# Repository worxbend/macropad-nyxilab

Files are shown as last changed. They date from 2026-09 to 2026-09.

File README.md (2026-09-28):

<div align="center">

# 🌙 nyxilab macropad

**12 keys. 2 screens. 16 LEDs. 1 stick *or* 1 knob. 0 glue.**
<br>it's giving main character desk energy 💅








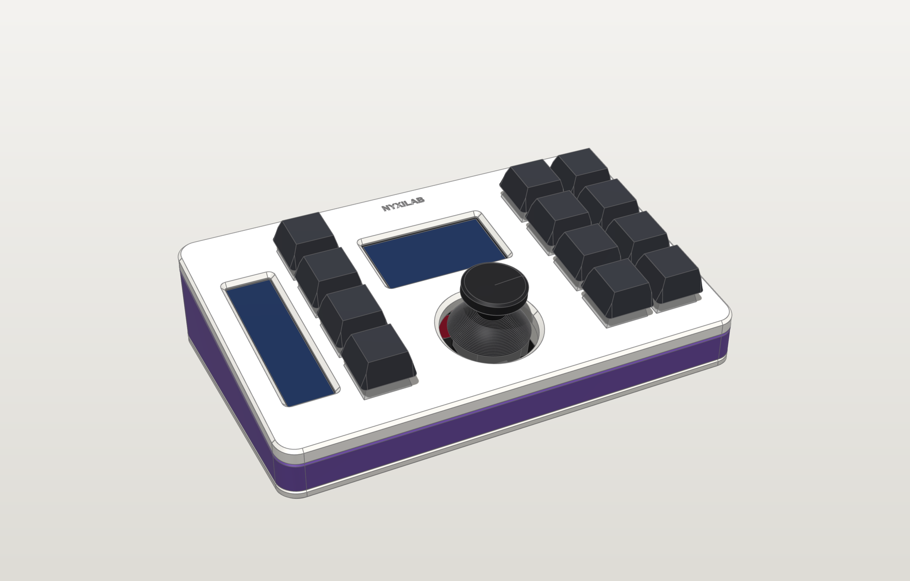
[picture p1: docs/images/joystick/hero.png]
nyxilab macropad render, joystick edition


**[📖 docs site](https://worxbend.github.io/macropad-nyxilab/) · [🧊 3D viewer](https://worxbend.github.io/macropad-nyxilab/viewer.html) · [⬇️ downloads](https://worxbend.github.io/macropad-nyxilab/downloads.html)**

</div>

## tl;dr 🫠

a hand-wired, 3D-printed macropad built around a **Raspberry Pi Pico 2**, with two color
displays, 16 RGB LEDs, and your pick of an analog thumbstick or a clicky rotary knob. this
monorepo has literally everything: the parametric case, print-ready files, blueprints,
a soldering guide with wiring maps, and the firmware. clone it, print it, solder it, flex it.
no custom PCB, no extra USB socket, no cap.

## choose your fighter 🎮

same case, same keys, same screens, same LEDs. only the thing in the middle changes,
and each edition is its own pair of projects.

| 🕹️ **joystick edition** | 🎛️ **rotary edition** |
|---|---|
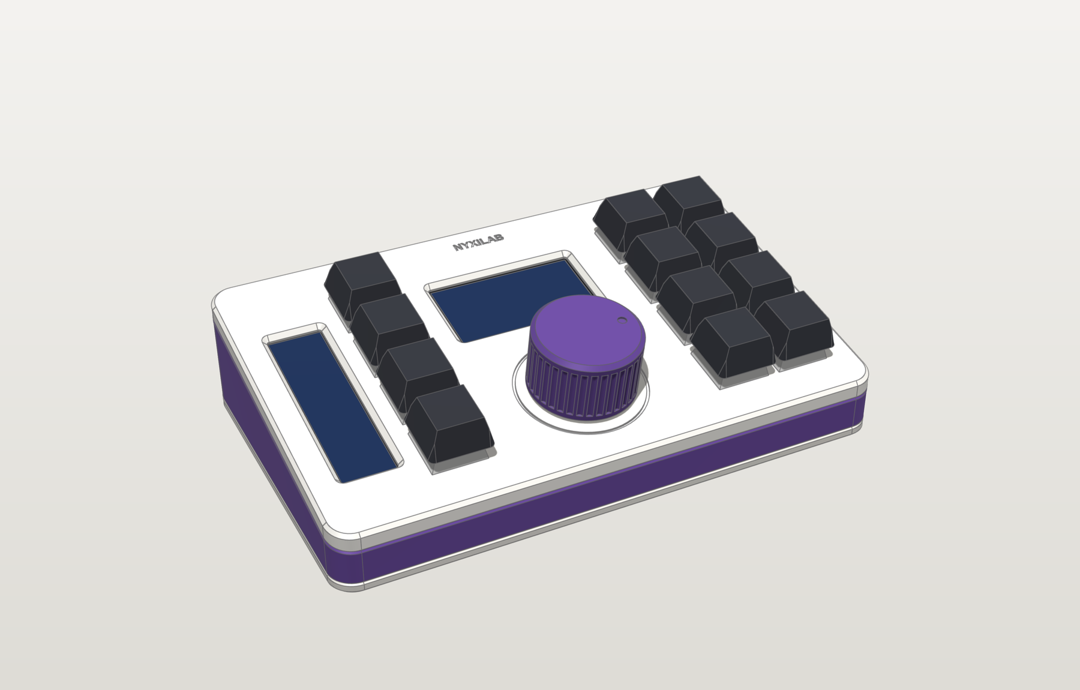
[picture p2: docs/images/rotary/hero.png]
rotary edition
| joystick edition |  |
| KY-023 thumbstick: mouse, scroll or arrow keys, per layer | KY-040 encoder + a chunky printed Ø30 knob: volume, undo/redo, scroll, zoom… |
| [`joystick/cad`](joystick/cad) · [`joystick/firmware`](joystick/firmware) | [`rotary/cad`](rotary/cad) · [`rotary/firmware`](rotary/firmware) |
| `nyxilab-macropad-joystick-pico2.uf2` | `nyxilab-macropad-rotary-pico2.uf2` |
| [read more →](joystick/README.md) | [read more →](rotary/README.md) |

the frame and the bar-display spine are literally the same parts in both, so switching
teams later means reprinting the top plate and the base. that's it.

## the specs (no cap) 📋

| | |
|---|---|
| ⌨️ **inputs** | 12 × MX switches (hand-wired matrix + diodes) and a KY-023 thumbstick that clicks **or** a KY-040 knob that clicks |
| 📺 **screens** | 1.9" 170×320 ST7789 IPS (main character) + 2.25" 76×284 ST7789P3 bar (the sidekick) |
| 💡 **lights** | 2 × 8 WS2812B LED sticks on the base, either side of the Pico: layer color, breathing or rainbow |
| 🧠 **brain** | Pico 2 (RP2350) USB-C clone, or the OG Pico (RP2040) if that's what you've got |
| 📐 **case** | 3-layer wedge: top plate, contrasting centre frame, base · 10° tilt · 159 × 98 mm · 18 → 35 mm tall |
| 🔩 **held together by** | 8 × M3×8 countersunk screws into heat-set inserts. zero glue, fully serviceable |
| ⚡ **firmware** | USB keyboard + media + mouse, layers, tap-hold, macros, joystick modes or per-layer knob bindings, LED effects |

## the lore 📜

every design decision had a reason, bestie. here's the tea:

- **three layers, two colors.** top plate + base in color A, the frame in color B, so you get
  that stripe all the way around. the screws pull the base and plate together *through* the frame,
  so the color seams close tight. no gaps, no drama.
- **print the frame translucent and the stripe glows.** the LED sticks sit on the base
  pointing up, so a clear or frosted PETG frame turns into a light band in your layer color.
  opaque frame? still works, just more subtle (the glow leaks around the stick).
- **all 8 screws are the same length.** the screw posts hang off the top plate, so the wedge
  doesn't make you buy three screw sizes. we love a consistent queen.
- **the Pico clone has no holes at the USB end** (rude). so the back wall thins down to 1.2 mm
  around the USB-C socket and holds it in place. any cable plugs in all the way. understood the assignment.
- **the joystick dome swings wider than you'd think** when you tilt it. posts hanging from the top
  plate would've been in the way, so the stick stands on tilted posts that grow out of the base.
- **the knob is panel-mounted like a real audio knob.** the encoder's M7 nut clamps the plate,
  a square pocket underneath stops it from spinning, and the printed knob's bore ends exactly at
  the shaft tip, so you just press it on until it stops. pressing it clicks the switch, not the knob
  down the shaft. an engraved ring frames it, because a sunken well would've printed as a 34 mm
  bridge on the pretty side. no thanks.
- **the bar display only has holes at one end.** a tiny printed clamp (`bar_spine`) holds the
  other end. no glue, no hot-glue era.

<div align="center">
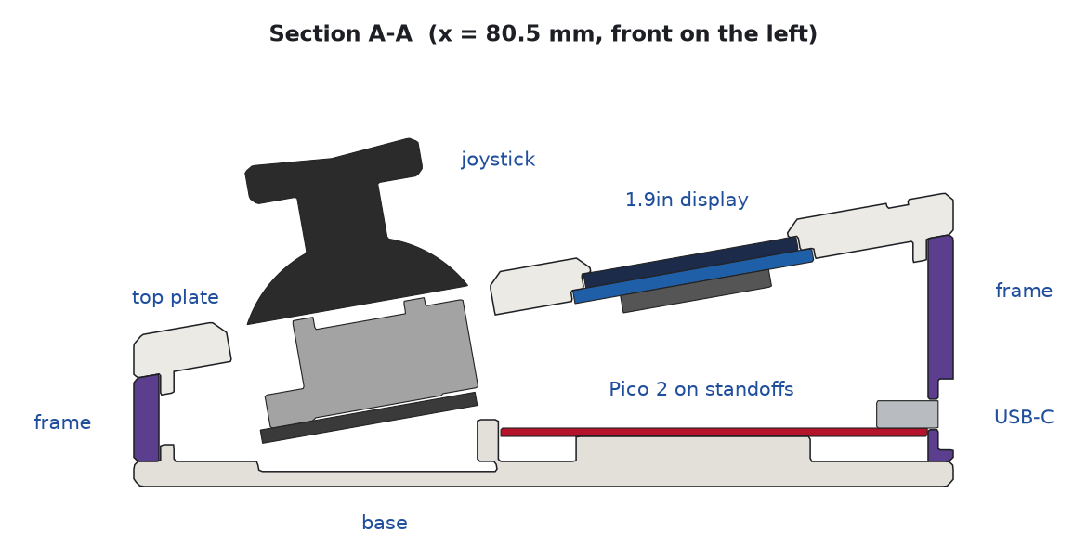
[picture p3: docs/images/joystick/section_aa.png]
section view through the joystick, display, Pico and USB-C

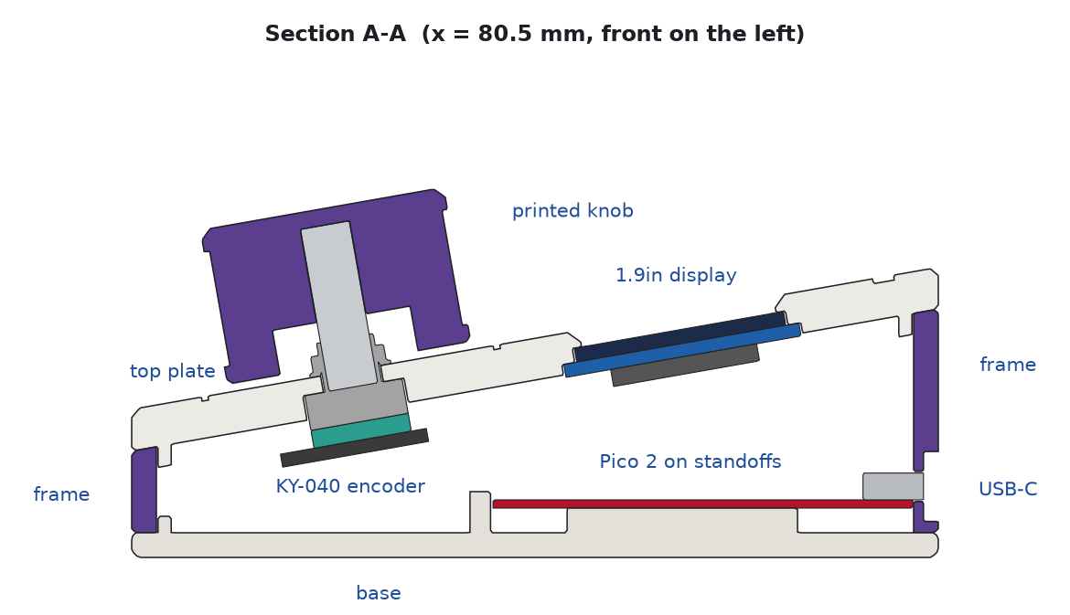
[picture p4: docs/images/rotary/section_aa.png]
section view through the knob, encoder, display, Pico and USB-C

<br><sub>cross-sections through the stick / the knob, the main screen, the Pico and the USB-C port. every mm accounted for 🧮</sub>
</div>

## glamour shots 📸

| exploded (it's a whole stack) | the knob era |
|---|---|
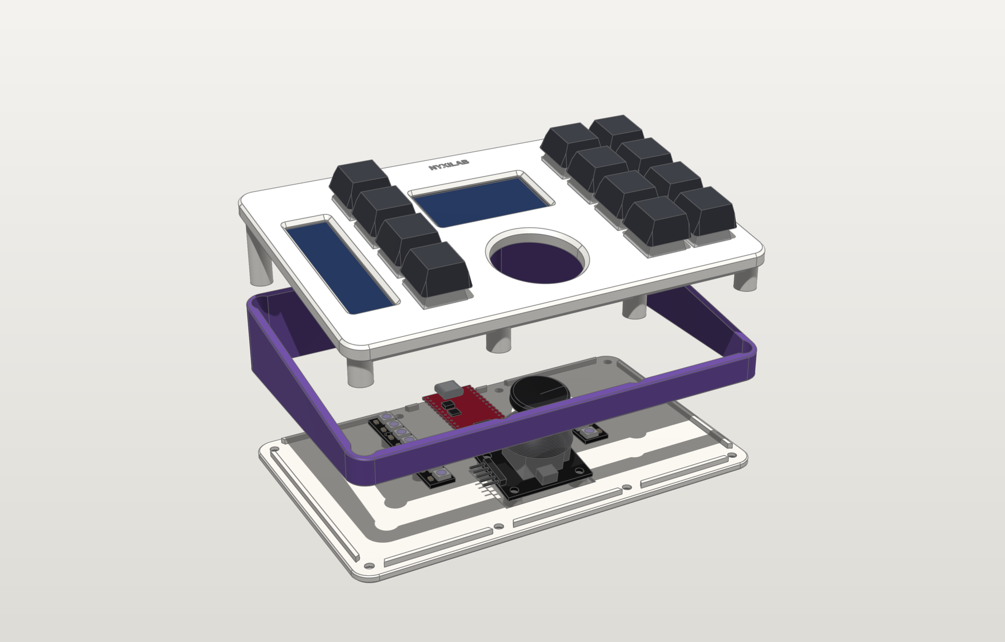
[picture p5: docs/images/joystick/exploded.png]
exploded view, joystick edition
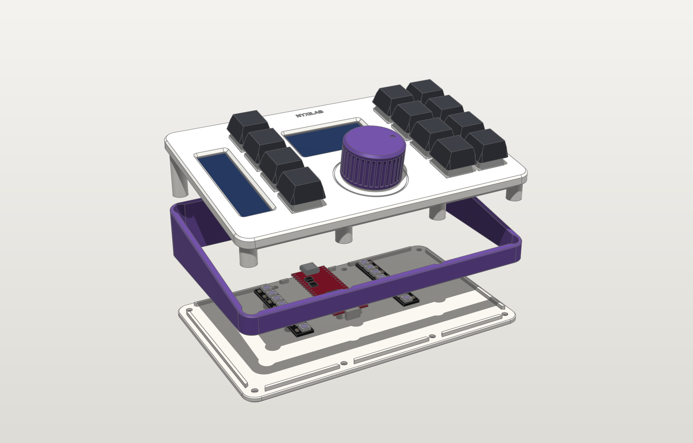
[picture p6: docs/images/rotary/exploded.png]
exploded view, rotary edition
|  |  |
| **the base: Pico + LED sticks** | **the back (USB-C, centered, obviously)** |
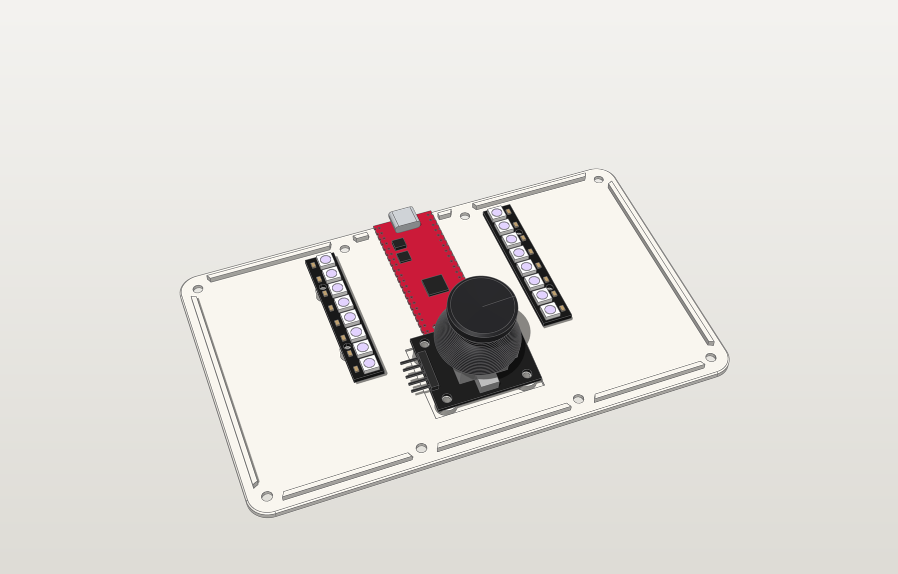
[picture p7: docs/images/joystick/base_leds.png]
base with the Pico and the two LED sticks
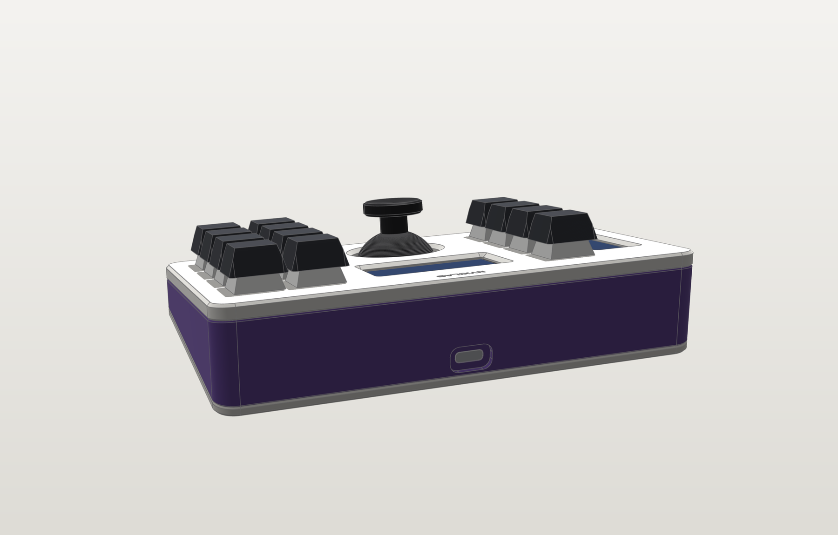
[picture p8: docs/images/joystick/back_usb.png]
back view with USB-C
|  |  |
| **what's inside** | **the underside of the plate** |
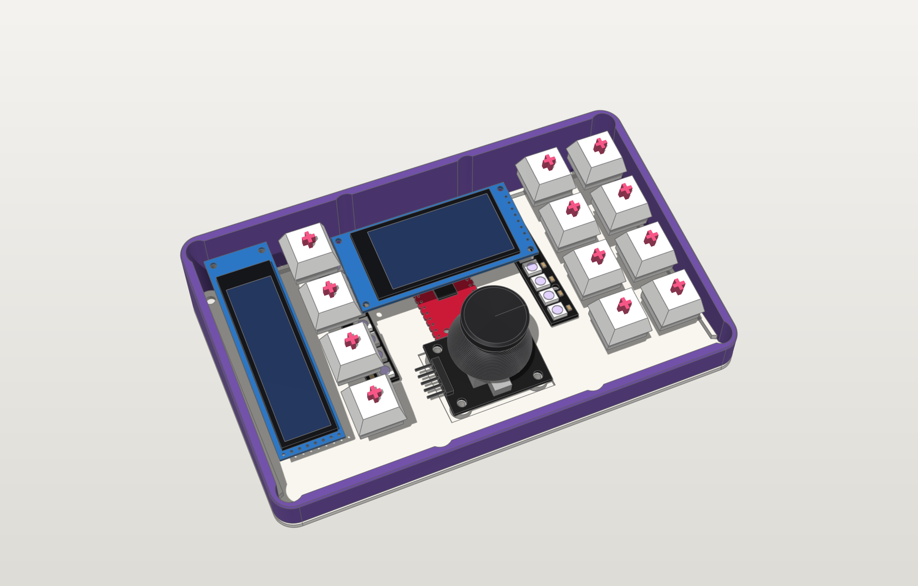
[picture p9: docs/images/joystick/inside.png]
inside view
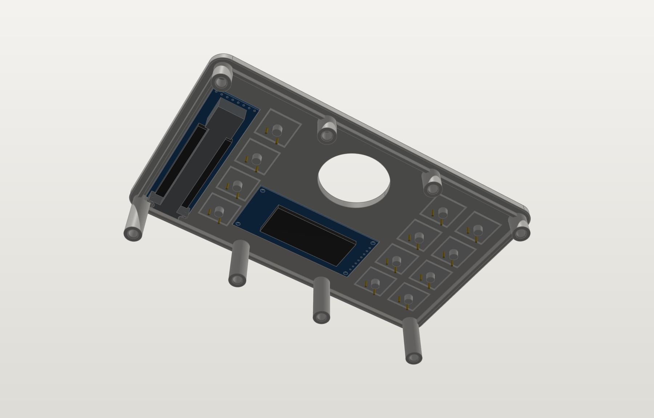
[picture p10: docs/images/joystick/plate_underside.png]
plate underside
|  |  |

wanna spin it around yourself? **[open the 3D viewer](https://worxbend.github.io/macropad-nyxilab/viewer.html)**
(or `docs/viewer.html` offline): switch editions, orbit, explode the layers, slice it with a live
section plane, toggle parts. it's lowkey addictive.

## the screens are eating fr 📺

these are rendered by the **actual firmware code** running on your PC (`make ui-sim`), not a mockup.
the dots underneath are the 16 LEDs, as the firmware would light them. real ones know.

| MEDIA layer | EDIT layer, caps lock on | FN held |
|---|---|---|
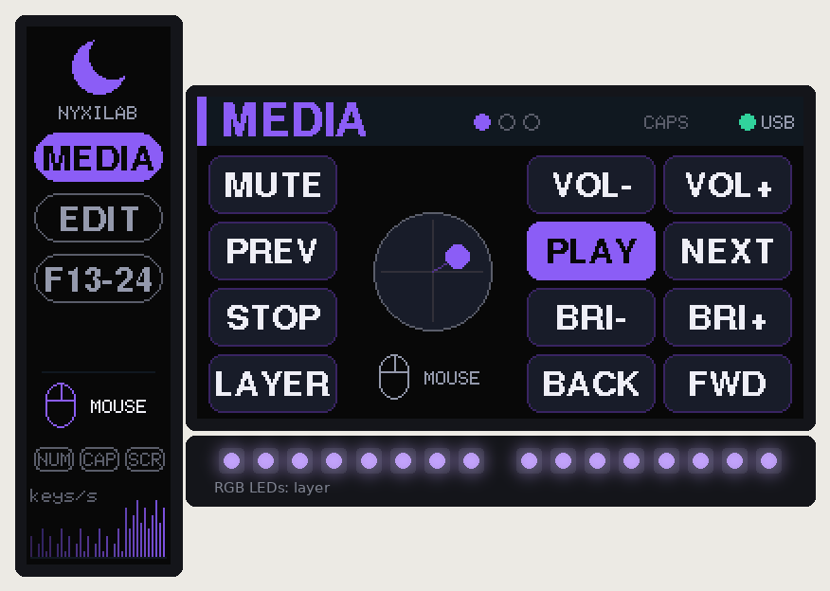
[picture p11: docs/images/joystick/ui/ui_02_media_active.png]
media layer UI
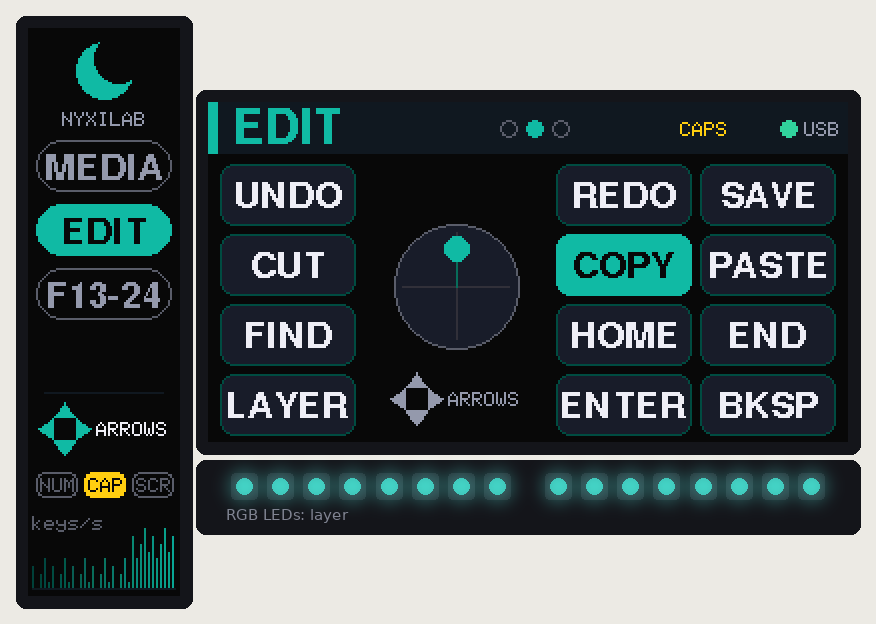
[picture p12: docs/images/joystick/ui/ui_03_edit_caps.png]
edit layer UI
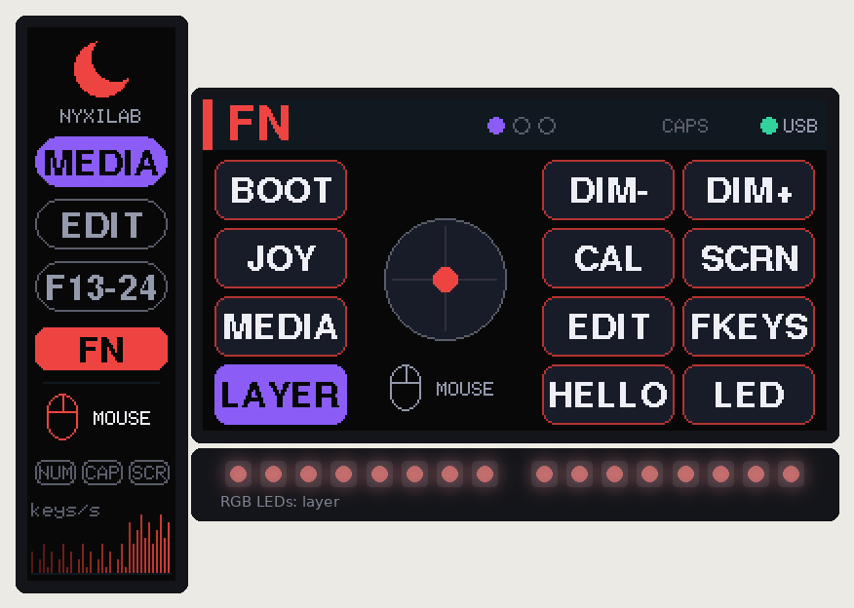
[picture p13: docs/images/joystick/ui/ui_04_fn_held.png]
FN layer UI
|  |  |  |
| **knob: volume** | **knob: undo/redo** | **knob: zoom preset + rainbow** |
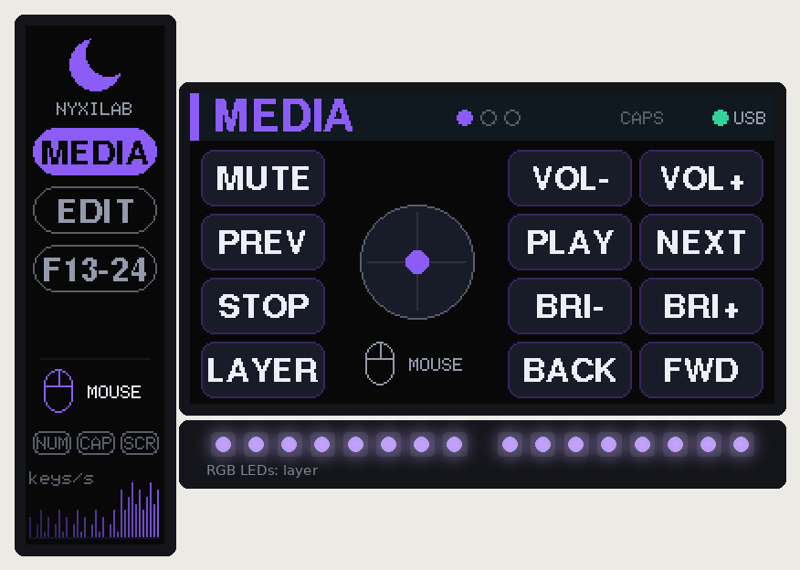
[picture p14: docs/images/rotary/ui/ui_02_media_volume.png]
rotary edition, volume
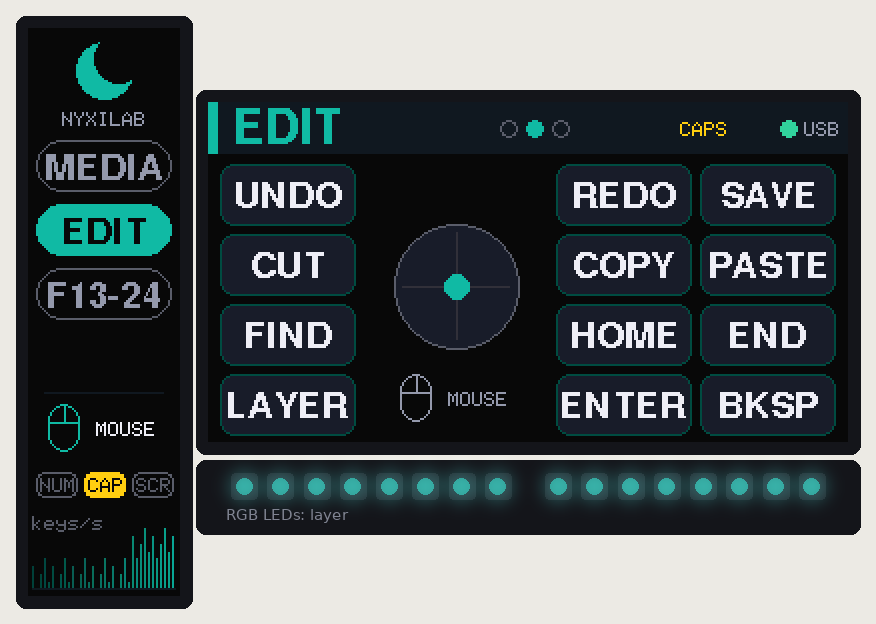
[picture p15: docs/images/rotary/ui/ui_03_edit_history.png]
rotary edition, history
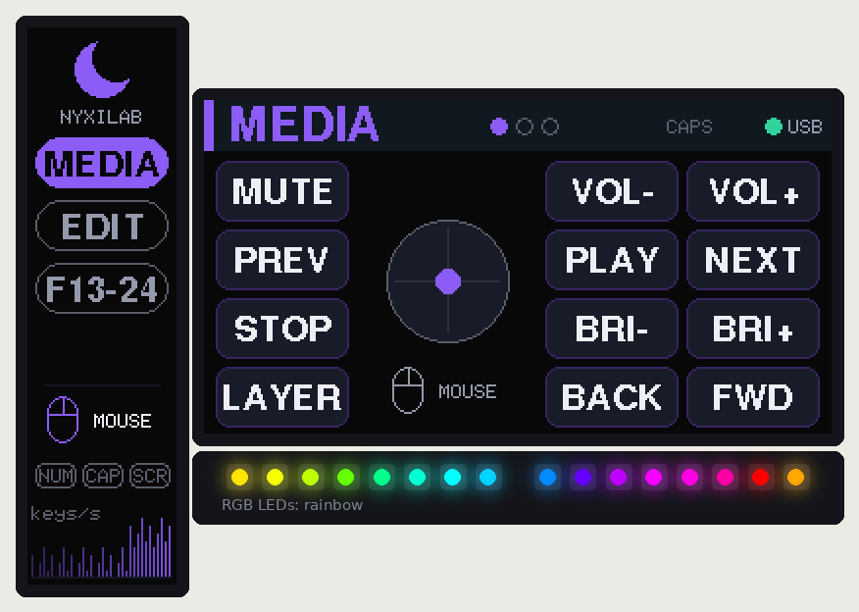
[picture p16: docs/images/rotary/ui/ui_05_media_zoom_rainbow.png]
rotary edition, zoom preset and rainbow LEDs
|  |  |  |

the 1.9" screen mirrors the physical key layout and lights up what you press. the middle
shows the stick, or a dial with 20 ticks that follows the knob and says what it does right
now. the bar shows your layers, the stick mode or knob function, NUM/CAPS/SCROLL straight
from your computer, and a keys-per-second graph so you can watch yourself go feral.

## soldering, but make it not scary 🔥

no PCB means you wire it yourself. the [soldering guide](docs/soldering.md) walks you through
it with pictures: how the matrix works, which way the diodes go, how the bent diode legs
*become* the row wires, and a wiring map drawn from the CAD model that shows where every
wire runs inside the case (plate seen from below, base from above).

| the diode, step by step | where the wires run |
|---|---|
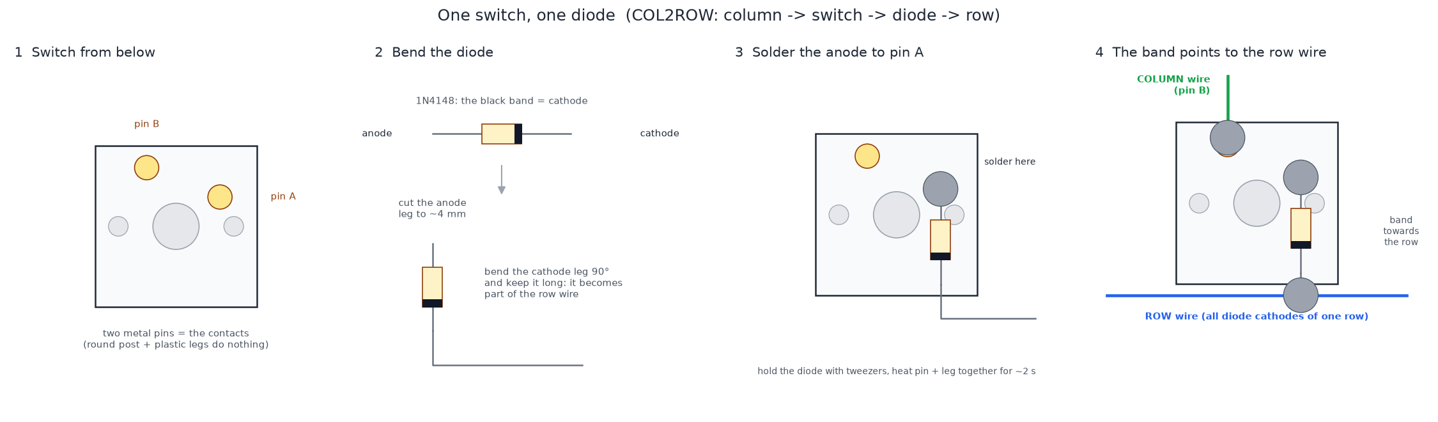
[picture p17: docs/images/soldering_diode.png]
how to solder a diode to a switch
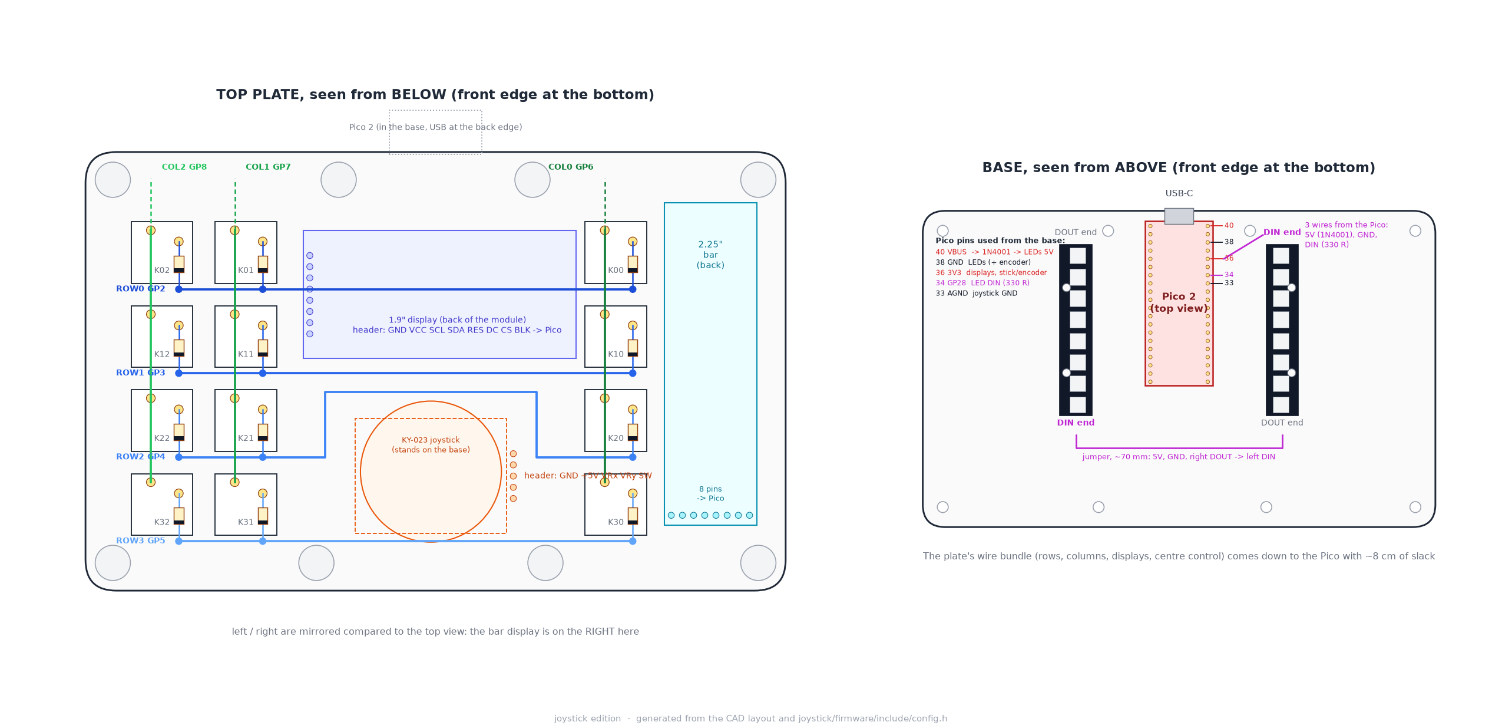
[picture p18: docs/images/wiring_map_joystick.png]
wiring map, joystick edition
|  |  |

## what's in the box 📦

four projects and the stuff they share:

```
joystick/
  cad/               the joystick edition's case: edition.py + build.py, exports/ (STL, 3MF, STEP, FreeCAD, GLB, blueprints)
  firmware/          its PlatformIO project: config.h, keymap.cpp, the stick, tests, dist/*.uf2
rotary/
  cad/               the rotary edition's case: the encoder mount + the knob, exports/
  firmware/          its PlatformIO project: config.h, keymap.cpp, the knob, tests, dist/*.uf2
common/
  cad/               the shared parametric case model (build123d) that both editions build on
  firmware/          the shared firmware libraries: engine, USB HID, displays, LEDs, the app loop (+ their tests)
docs/                design notes, printing, soldering, wiring, assembly, generated images, 3D viewer
tools/               UI simulator, wiring diagrams + maps, soldering figures, viewer + website builders
```

## speedrun any% 🏃‍♀️

1. **pick your edition** (joystick or rotary) and grab its files: `<edition>/cad/exports/` or the
   [downloads page](https://worxbend.github.io/macropad-nyxilab/downloads.html).
2. **print the fit tests first** (`3mf/fit-tests/`, ~1 h total). they check the switch
   cut-out, both display pockets, the USB-C port, the joystick posts or the encoder mount,
   and the LED-stick posts against *your* parts. rotary gang: print the knob early too.
   something off? measure it, tweak `common/cad/macropad_cad/params.py` (or the edition's
   `edition.py`), run `make cad`. easy.
3. **print the case**: `top_plate` (color A, top face down), `frame` (color B, translucent if you
   want the glow), `base` (color A), the tiny `bar_spine`, and the `knob` for the rotary edition.
   settings in [docs/printing.md](docs/printing.md).
4. **solder it and put it together**: [docs/soldering.md](docs/soldering.md) →
   [docs/wiring.md](docs/wiring.md) → [docs/assembly.md](docs/assembly.md).
   the LED sticks need one diode and one resistor, no board.
5. **flash it**: hold BOOTSEL while plugging in the Pico, drop
   `joystick/firmware/dist/nyxilab-macropad-joystick-pico2.uf2` (or the rotary one) onto the
   `RP2350` drive (or `make flash-joystick` / `make flash-rotary`). after that, flashing reboots
   it for you, no button needed. W.

> [!WARNING]
> **red flags 🚩 read before printing.** a few dimensions came from photos, not datasheets:
> how far the Pico's USB-C sticks out past the board, the bar display's glass and hole positions,
> the joystick's hole spacing, the KY-040's shaft length, and the LED sticks' hole spacing.
> they're tagged `MEASURE` in the params. grab your calipers, or at least print the fit tests.
> skipping this is a skill issue.

> [!TIP]
> image upside down on a screen? pointer going the wrong way? knob turning backwards?
> that's one setting each in `<edition>/firmware/include/config.h` (`*_ROTATION`, `JOY_INVERT_X/Y`,
> `ENC_REVERSE`, or just FN + REV on the pad). the [firmware README](common/firmware/README.md) has the full list.

## build from source (for the terminally online) 🛠️

```bash
make setup              # Python venv for the CAD + docs tools, PlatformIO
make cad                # both editions: fit checks, exports, renders, blueprints (~5 min)
make firmware           # both editions for the Pico 2, UF2s land in <edition>/firmware/dist/
make test               # all unit tests on your PC (shared core, stick maths, knob decoder)
make docs               # UI renders, wiring diagrams + maps, soldering figures, 3D viewer, the website
```

one edition at a time: `make cad-rotary`, `make firmware-joystick`, `make test-rotary`, and so on.
the FreeCAD files rebuild when `freecadcmd` is on your PATH (or set `FREECAD_CMD=/path/to/freecadcmd`).
everything else only needs Python and PlatformIO. the website in `site/` is what
[GitHub Pages](https://worxbend.github.io/macropad-nyxilab/) serves; it redeploys on every push to `main`.

```mermaid
flowchart LR
  subgraph core0["core 0 · the grind"]
    scan["matrix scan 1 kHz"] --> deb["debounce 5 ms"] --> eng["engine: layers, tap-hold, macros, knob"] --> usb["USB HID"]
    centre["stick ADC or knob interrupts"] --> eng
  end
  subgraph core1["core 1 · the aesthetic"]
    main["1.9in screen"]
    bar["2.25in bar"]
    leds["16 RGB LEDs"]
  end
  eng -. "UI snapshot" .-> main
  eng -. "UI snapshot" .-> bar
  eng -. "UI snapshot" .-> leds
```

## receipts 🧾

we don't just vibe, we verify:

- **169 collision checks** (joystick) and **191** (rotary) on every build: each printed part
  against each component (plus room for solder joints and wiring), against the joystick's full
  25° swing or the spinning knob, and every component against every other, LED sticks
  included. **0 clashes.**
- **printability check** in print orientation: no supports needed, only a few short bridges (the longest is a 10.5 mm foot recess).
- **33 firmware unit tests** (debounce, layers, tap-hold, macros, knob bindings, LED effects and
  the current limit in the shared core; the stick maths; the knob decoder), all green ✅
- both editions build for **both** boards (Pico 2 / OG Pico) with **zero warnings** under `-Wall -Wextra`.
- the wiring diagrams are generated from each edition's `config.h`, and the build refuses if the two
  editions ever disagree on a shared pin.

## faq 💬

**joystick or knob?** stick if you want a mouse, arrows and scrolling with your thumb. knob if
you live in volume, timelines and undo history. both are in this repo and share almost every part.

**do I need the LEDs?** nope. leave them out, the posts don't care. set `LED_COUNT = 0` if you
want the firmware to stop talking to GP28.

**will 16 LEDs cook my USB port?** no. the firmware caps them at 250 mA total, and they dim with
the screens and switch off when your computer sleeps.

**does it need supports?** nah. every part prints flat as exported.

**glue?** zero. it's screws all the way down, so you can open it up and fix your wiring later.

**can I use the OG Pico (RP2040)?** yes bestie, `make firmware-joystick-pico` (or `-rotary-pico`)
and flash the `…-pico.uf2`. same footprint, same case.

**what do the keys do?** four layers out of the box: MEDIA, EDIT, F13–F24 and a hold-for-FN layer.
tap the front-left key for the next layer, hold it for FN. the knob does volume, undo/redo,
scroll and screen brightness depending on the layer, and FN + KNOB swaps in volume / scroll /
zoom / arrows. remap everything in `<edition>/firmware/src/keymap.cpp`.

**macOS?** the shortcuts use Ctrl. swap `MOD_LCTRL` for `MOD_LGUI` in the keymap and you're golden.

## docs (the boring-but-important era) 📚

everything below is also on the **[docs site](https://worxbend.github.io/macropad-nyxilab/)**, rendered nicely.

- **[3D viewer](https://worxbend.github.io/macropad-nyxilab/viewer.html)**: both editions. orbit, explode, section, toggle parts
- [design notes](docs/design.md): layout, the 3-layer stack, how each part is held, what the checks verify
- [printing](docs/printing.md): orientation, settings, colors, the knob, the dimensions to verify first
- [soldering](docs/soldering.md): tools, the matrix, diodes step by step, displays, LEDs, the Pico, wiring maps, troubleshooting
- [wiring](docs/wiring.md): Pico pin map, matrix, displays, joystick, encoder, LED sticks
- [assembly](docs/assembly.md): bill of materials + step-by-step build, both editions
- [joystick edition](joystick/README.md) · [rotary edition](rotary/README.md): what is specific to each
- [firmware](common/firmware/README.md): keymap, layers, joystick modes, knob bindings, LED modes, display settings, serial console
- [CAD](common/cad/README.md): the shared model, the edition hooks, changing parameters and regenerating the files

<div align="center">
<br>
made with 💜, calipers, and way too many clearance checks
<br>
<sub>touch grass after soldering. you earned it 🌱</sub>
</div>

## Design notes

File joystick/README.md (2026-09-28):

# Joystick edition

The Nyxilab macropad with a **KY-023 thumbstick** in the middle: mouse, scroll or
arrow keys, chosen per layer, and a click.

Joystick edition

| | |
|---|---|
| `cad/` | the case of this edition: `edition.py` (the joystick, its posts and opening), `build.py`, and the generated `exports/` (STL, 3MF, STEP, FreeCAD, GLB, blueprints) |
| `firmware/` | the PlatformIO project: `include/config.h` (pins), `src/keymap.cpp` (layers + stick mode per layer), `src/stick.cpp` (the stick as the app's centre control), `src/joystick.cpp` (the stick maths), `test/`, `dist/` (prebuilt UF2) |

The case model itself and the firmware's engine, USB, displays and LEDs are shared
with the rotary edition and live in [`common/`](../common).

## Build

```bash
make cad-joystick                 # checks + exports + renders + blueprints  (python joystick/cad/build.py all)
make firmware-joystick            # Pico 2 UF2 -> joystick/firmware/dist/    (cd joystick/firmware && pio run)
make firmware-joystick-pico       # original Pico (RP2040)
make flash-joystick               # build + upload over USB
make test-joystick                # unit tests of the stick maths on this PC
```

## What is specific to this edition

- **Case**: the stick's dome sweeps wide when tilted, so the module stands on four
  posts that grow out of the **base** (tilted 10°, M3 self-tapping screws), and the
  top plate has a Ø32 bevelled opening. A 1.2 mm relief in the base clears the solder
  joints. Fit checks: 169 pairs, including the dome's full 25° sweep.
- **Firmware**: `STICK(JoyMode::Mouse | Scroll | Arrows | Off)` per layer in
  `keymap.cpp`; FN + JOY cycles the mode of the current layer, FN + CAL re-centres.
  Stick click = left click / middle click / Enter depending on the mode. Calibration
  is learned while you use it and saved in flash.
- **Wiring**: VRx → GP26, VRy → GP27, SW → GP22, +5V → **3V3**, GND → AGND.

## Files to print

`cad/exports/3mf/`: `top_plate`, `frame`, `base`, `bar_spine`, plus the fit-test
coupons in `3mf/fit-tests/` (`fit_plate_joy`, `fit_joystick` are the ones only this
edition has). See [docs/printing.md](../docs/printing.md).

## Docs

[Design](../docs/design.md) · [Printing](../docs/printing.md) · [Soldering](../docs/soldering.md) ·
[Wiring](../docs/wiring.md) · [Assembly](../docs/assembly.md) · [Firmware](../common/firmware/README.md) ·
[CAD](../common/cad/README.md)

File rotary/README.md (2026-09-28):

# Rotary edition

The Nyxilab macropad with a **KY-040 rotary encoder** and a printed Ø30 knob in the
middle: volume, undo/redo, scrolling, zoom, per layer, and a click.

Rotary edition

| | |
|---|---|
| `cad/` | the case of this edition: `edition.py` (the encoder mount, the knob), `build.py`, and the generated `exports/` (STL, 3MF, STEP, FreeCAD, GLB, blueprints) |
| `firmware/` | the PlatformIO project: `include/config.h` (pins), `src/keymap.cpp` (layers + knob binding per layer + presets), `src/knob.cpp` (the knob as the app's centre control), `src/quad_decoder.h`, `test/`, `dist/` (prebuilt UF2) |

The case model itself and the firmware's engine, USB, displays and LEDs are shared
with the joystick edition and live in [`common/`](../common).

## Build

```bash
make cad-rotary                   # checks + exports + renders + blueprints  (python rotary/cad/build.py all)
make firmware-rotary              # Pico 2 UF2 -> rotary/firmware/dist/      (cd rotary/firmware && pio run)
make firmware-rotary-pico         # original Pico (RP2040)
make flash-rotary                 # build + upload over USB
make test-rotary                  # unit tests of the quadrature decoder on this PC
```

## What is specific to this edition

- **Case**: the encoder is panel-mounted in the **top plate**: its M7 bushing goes up
  through a Ø7.4 hole, the washer and nut clamp a 2 mm section from the top, and a
  12.5 mm square pocket underneath keys the body so it can't turn. The base has no
  posts. The **knob** (Ø30 × 19, 36 flutes, indicator dimple) is a press fit on the
  D-shaft; its bore ends at the shaft tip, so it stops 1 mm above the plate and a push
  goes into the encoder's switch. An engraved ring frames it. Fit checks: 191 pairs,
  including the spinning knob's envelope.
- **Firmware**: `KNOB(cw, ccw, press, "LABEL")` per layer in `keymap.cpp`
  (volume / undo-redo / scroll / screen brightness by default). FN + KNOB cycles the
  current layer through the presets (volume, scroll, zoom, arrows), FN + REV flips
  the direction. Detents are decoded by interrupts and queued, so fast turns lose
  nothing.
- **Wiring**: CLK → GP26, DT → GP27, SW → GP22, + → **3V3**, GND → GND.

## Files to print

`cad/exports/3mf/`: `top_plate`, `frame`, `base`, `bar_spine`, **`knob`** (top face
down, fine layers), plus the fit-test coupons in `3mf/fit-tests/` (`fit_plate_enc` is
the one only this edition has). Print the knob early: it is the best test of the
shaft fit (`Knob.bore_clear` in `cad/edition.py`). See
[docs/printing.md](../docs/printing.md#the-knob-rotary-edition).

## Docs

[Design](../docs/design.md) · [Printing](../docs/printing.md) · [Soldering](../docs/soldering.md) ·
[Wiring](../docs/wiring.md) · [Assembly](../docs/assembly.md) · [Firmware](../common/firmware/README.md) ·
[CAD](../common/cad/README.md)

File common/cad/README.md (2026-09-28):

# CAD

The parametric case, in [build123d](https://github.com/gumyr/build123d) (OpenCASCADE
B-rep), with mesh checks in [manifold3d](https://github.com/elalish/manifold), headless
renders (moderngl/EGL) and matplotlib blueprints.

This package (`macropad_cad`) is the **shared** model: the tilted top plate with the
switches and the two displays, the wedge frame with the USB-C port, the base with the
Pico cradle and the LED-stick posts, the bar-display spine, the fit checks, the
exporters, the renders and the drawings. It does not know what sits in the middle.
Each edition adds that in its own project:

| Edition | `edition.py` | Outputs | Images |
|---|---|---|---|
| [`joystick/cad`](../../joystick/cad) | KY-023 thumbstick: posts in the base, bevelled opening in the plate, dome sweep | `joystick/cad/exports/` | `docs/images/joystick/` |
| [`rotary/cad`](../../rotary/cad) | KY-040 encoder: panel mount in the plate, printed knob, knob envelope | `rotary/cad/exports/` | `docs/images/rotary/` |

Frame and bar spine come out identical in both editions.

## Setup and commands

```bash
python3 -m venv .venv && .venv/bin/pip install -e "common/cad[render]"   # or `make setup` from the repo root
.venv/bin/python joystick/cad/build.py check      # fit / interference / printability checks
.venv/bin/python joystick/cad/build.py export     # STEP, STL, 3MF, GLB (+ FreeCAD)
.venv/bin/python joystick/cad/build.py render     # renders into docs/images/joystick
.venv/bin/python joystick/cad/build.py drawings   # blueprints into joystick/cad/exports/drawings
.venv/bin/python joystick/cad/build.py all        # everything (~2.5 min with FreeCAD)
```

Same for `rotary/cad/build.py`. From the repo root: `make cad` (both editions),
`make cad-joystick CMD=check`, `make cad-rotary`.

The FreeCAD document needs FreeCAD 1.x: put `freecadcmd` on the PATH or set
`FREECAD_CMD` (an extracted AppImage works: `FreeCAD.AppImage --appimage-extract`,
then `squashfs-root/usr/bin/freecadcmd`). Without it the previous document is kept.
Rendering needs an OpenGL driver (EGL); everything else is pure Python.

## Changing the design

Shared dimensions live in `macropad_cad/params.py` (components, fasteners,
tolerances, the case), grouped by part; the centre control's dimensions live in the
edition's `edition.py`. Values marked `MEASURE` should be checked against your own
modules. Typical edits:

| Want | Change |
|---|---|
| steeper / flatter wedge | `Case.tilt_deg` (front height is set by `Case.front_h`) |
| tighter or looser switch fit | `MXSwitch.hole` |
| modules loose in their pockets | `PrintTol.pocket` |
| different insert size / self-tapping | `Fasteners.insert_d`, `insert_depth` |
| no logo | `Case.logo = ""` |
| move the centre control / displays | `Case.centre_v`, `Case.bar_v`, `Case.center_half` |
| move the LED sticks | `Case.led_dx` (from the Pico axis), `Case.led_y` |
| LED stick with other holes | `LedStick.hole_pitch`, `hole_y`, `hole_d` |
| joystick opening, posts, relief | `JoystickMount` in `joystick/cad/edition.py` |
| knob too tight / loose on the shaft, knob size, grip | `Knob.bore_clear`, `Knob.d`, `h`, `flutes` in `rotary/cad/edition.py` |
| encoder clamp, pocket, ring | `EncoderMount` in `rotary/cad/edition.py` |

Run `check` after every change: it fails (non-zero exit) if any printed part intrudes
into a component, its wiring space, the joystick sweep or the knob's envelope, or if
parts or components overlap. The numbers also go to `<edition>/cad/exports/checks.json`.

## Package layout

```
params.py      shared dimensions (components, fasteners, tolerances, case)
edition.py     the Edition interface: the hooks an edition implements (geometry, checks, drawings)
layout.py      derived positions: key grid, module placements, bosses, heights; Layout(edition)
components.py  reference models of switches, keycaps, Pico 2, displays, LED sticks (+ keep-outs)
parts.py       top_plate, frame, base, bar_spine; print orientation (the edition adds its parts)
fit_tests.py   quick coupons for the critical fits (+ helpers for the editions' coupons)
checks.py      interference, clearance and printability checks (manifold3d, trimesh)
export.py      STEP / STL / 3MF / GLB writers, FreeCAD hand-off
freecad_doc.py runs inside FreeCAD to build the .FCStd
render.py      headless OpenGL renderer; renders.py = the standard views
drawings.py    A3 blueprint sheets, section view, 1:1 template
cli.py         the build.py command line
```

## Outputs (`<edition>/cad/exports/`)

| Folder | Content |
|---|---|
| `stl/`, `3mf/` | print-ready parts in print orientation; `fit-tests/` coupons |
| `step/` | each part in assembled position (editable in any CAD), full colour assembly, reference components |
| `freecad/` | `nyxilab_macropad_<edition>.FCStd`: printed parts, reference components, a layout spreadsheet |
| `gltf/` | coloured assembly / case for viewers (`docs/viewer.html` embeds both editions) |
| `drawings/` | `nyxilab_macropad_<edition>_blueprints.pdf` (5 × A3), per-sheet SVG, `template_top_plate_1to1.pdf` |
| `manifest.json` | layout summary, part sizes/volumes, print notes |
| `checks.json` | fit-check count, clearances, printability report, facts for the viewer |

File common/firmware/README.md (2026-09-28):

# Firmware

The firmware of both editions is one code base: four PlatformIO libraries here in
`lib/`, and one small project per edition that adds its centre control and keymap
([`joystick/firmware`](../../joystick/firmware), [`rotary/firmware`](../../rotary/firmware)).
It runs on the Raspberry Pi Pico 2 (RP2350) and the Pico (RP2040), on the
[Arduino-Pico](https://github.com/earlephilhower/arduino-pico) core with Adafruit
TinyUSB (composite HID), Adafruit GFX / ST7789 and Adafruit NeoPixel.

| Joystick edition | Rotary edition |
|---|---|
| Joystick edition UI | Rotary edition UI |

<sub>Rendered by `tools/ui_sim` from the real firmware code, with the 16 LEDs as the firmware
would light them.</sub>

## Build & flash

| Project | Environment | Board | UF2 |
|---|---|---|---|
| `joystick/firmware` | `pico2` (default) / `pico` | Pico 2 / Pico | `joystick/firmware/dist/nyxilab-macropad-joystick-pico2.uf2` (`-pico.uf2`) |
| `rotary/firmware` | `pico2` (default) / `pico` | Pico 2 / Pico | `rotary/firmware/dist/nyxilab-macropad-rotary-pico2.uf2` (`-pico.uf2`) |

```bash
cd joystick/firmware        # or rotary/firmware
pio run                     # Pico 2
pio run -e pico             # original Pico
pio run -t upload           # flash over USB (reboots the pad into the bootloader itself)
pio device monitor          # serial console, 115200
pio test -e native          # this edition's unit tests on the PC
```

From the repo root: `make firmware` (both editions, Pico 2), `make firmware-all` (all
four UF2 files), `make test` (all unit tests), `make ui-sim` (render the UI).

First flash, or if the firmware is broken: hold **BOOTSEL** while plugging the Pico
in and copy the UF2 for your board and edition to the `RP2350` (or `RPI-RP2`) drive.
Once the case is closed you do not need BOOTSEL any more:
- `pio run -t upload` resets the pad into the bootloader over USB,
- or hold the **back-left + front-right** keys while plugging in,
- or press **FN + BOOT** (hold the front-left key, press the back-left key).

## Features

- 4×3 hand-wired matrix, COL2ROW, 1 kHz scan, 5 ms per-key debounce
- Composite USB HID: 6-key keyboard + consumer (media) + mouse with wheel and pan
- Layers with momentary / toggle / to / next, tap-hold keys (hold-on-other-key), text macros
- **Joystick edition**: mouse, scroll or arrow keys, chosen per layer and cycled with
  FN + JOY; stick click = left click / middle click / Enter; radial dead zone, response
  curve, auto-learned travel
- **Rotary edition**: every layer says what the knob does (turn clockwise, turn
  counter-clockwise, press). FN + KNOB switches the current layer to a preset (volume,
  scroll, zoom, arrows) and back. The knob is read by pin-change interrupts with a
  detent-synchronised decoder, so bounce never adds steps; key taps from fast turns are
  queued, so none are lost.
- **RGB LED sticks** (2 × 8 WS2812B, both editions): layer colour with a flash on every key
  press or knob click, breathing, or a rainbow running around the case; FN + LED cycles
  the modes. They follow the display brightness and idle dimming and go dark while the host
  sleeps; a 250 mA current budget keeps the pad inside a USB 2.0 port's limit.
- Main display (1.9"): layer name, the 12 key labels in their physical layout with live
  press highlight, the joystick position and mode or a knob dial with its current
  function, CAPS and USB state
- Bar display (2.25"): layer list, joystick mode or knob function, NUM/CAPS/SCROLL LEDs
  from the host, key-press activity graph
- Backlight PWM with FN + DIM±, dims after 1 min idle, off after 10 min or when the host sleeps
- Settings (brightness, per-layer stick mode or knob preset, knob direction, LED mode,
  last layer, joystick calibration) stored in flash
- Dual core: input + USB on core 0; the displays and the LEDs on core 1 (off-screen
  canvases, no flicker)

## Default keymap

Rows are listed back (row 0) to front (row 3); column 0 is the single column next to the bar display.

| Layer | Col 0 | Col 1 | Col 2 | Joystick | Knob: turn right / left / press |
|---|---|---|---|---|---|
| **MEDIA** | MUTE / PREV / STOP / LAYER | VOL− / PLAY / BRI− / BACK | VOL+ / NEXT / BRI+ / FWD | mouse | volume up / down / mute |
| **EDIT** | UNDO / CUT / FIND / LAYER | REDO / COPY / HOME / ENTER | SAVE / PASTE / END / BKSP | arrows | redo / undo / save |
| **F13-24** | F13 / F16 / F19 / LAYER | F14 / F17 / F20 / F22 | F15 / F18 / F21 / F23 | scroll | scroll down / up / middle click |
| **FN** (hold LAYER) | BOOT / JOY or KNOB / MEDIA / (held) | DIM− / CAL or REV / EDIT / HELLO | DIM+ / SCRN / FKEYS / LED | – | screen brightness + / − / screens on-off |

LAYER (front-left key): **tap** = next layer, **hold** = FN. Holding LAYER and turning the
knob uses the FN binding straight away. F13–F24 are handy for binding actions in OBS,
IDEs and window managers without clashing with real shortcuts.

The two centre-control keys on the FN layer differ per edition: **JOY** (cycle the
stick mode) and **CAL** (re-centre) in the joystick keymap, **KNOB** (cycle the knob
preset for this layer) and **REV** (flip the turning direction) in the rotary keymap.

## Customising

| What | Where |
|---|---|
| Keys, labels, layers, colours, tap-hold, macros, stick modes or knob bindings and presets | `<edition>/firmware/src/keymap.cpp` |
| Pins, display rotation / inversion / BGR, stick or knob direction, LED count and brightness, SPI speed, idle times | `<edition>/firmware/include/config.h` |
| Joystick feel (dead zone, curve, speeds, arrow thresholds) | `JoyConfig` in `joystick/firmware/src/joystick.h` |
| LED effects (flash length, breathing and rainbow speed) | `lib/nyx_core/src/core/led_fx.h` |
| Boot-to-bootloader key combo | `BOOT_COMBO` in `lib/nyx_core/src/core/keymap.h` |

Action helpers for the keymap (`lib/nyx_core/src/core/keycodes.h`):
`K(hid::A)`, `KC(MOD_LCTRL, hid::C)`, `CC(cc::VOL_UP)`, `MB(MB_LEFT)`, `WHEEL(-1)`,
`MO(n)`, `TG(n)`, `TO(n)`, `LNEXT`, `TH(i)`, `MACRO(i)`, `SYS(SYS_BOOTLOADER)`,
`JOY(JoyMode::Scroll)`, `KNOB_PRESET(i)`, `KNOB_CYCLE`, `___` (transparent), `XX`
(nothing). Shortcuts use Ctrl – on macOS use `MOD_LGUI`.

A layer is `{"NAME", colour, centre, {keys}}`. `centre` is `STICK(JoyMode::Mouse)` in
the joystick keymap, `KNOB(clockwise, counter-clockwise, press, "LABEL")` in the rotary
keymap, or `CENTRE_INHERIT` to fall through to the layer below. Each knob detent taps a
key, consumer or mouse-button action once, and runs a wheel step or system command
immediately.

**Display orientation**: if an image is upside down, change `MAIN_ROTATION` (1 ↔ 3) or
`BAR_ROTATION` (2 ↔ 0). Wrong colours: toggle `*_INVERT`; red/blue swapped: set `*_BGR`.

## Serial console

`pio device monitor` (115200): `help`, `info` (layers, USB, lock LEDs, brightness, LED
mode, plus the stick calibration or the knob binding), `layer <n>`, `boot`, and the
edition's own commands: `joy` (raw stick values for 5 s) and `cal` (re-centre), or
`enc` (knob pins and position for 5 s).

## Code layout

```
common/firmware/lib/
  nyx_core/src/core/    pure C++ (no Arduino), unit-tested here (pio test -e native, 23 tests)
    keycodes.h          action encoding (32-bit: type | argument) + HID usages
    keymap.h            layer / key / centre-control types; the layers live in the editions
    debounce.h          per-key deferred debounce
    engine.h/.cpp       layers, tap-hold, macros, knob bindings and queued taps -> HID report state
    led_fx.h/.cpp       LED effects and the current budget
  nyx_hw/src/hw/        matrix scan, USB HID report scheduler, settings in flash
  nyx_ui/src/ui/        UI state hand-over between the cores, rendering, ST7789 panels, WS2812 sticks
  nyx_app/src/app/      the application: core 0 loop, console, UI feed; core 1 displays + LEDs
                        app::Centre is the interface an edition's centre control implements
joystick/firmware/      config.h, keymap.cpp, stick.cpp (JoystickCentre), joystick.cpp, main.cpp, 6 tests
rotary/firmware/        config.h, keymap.cpp, knob.cpp (KnobCentre), quad_decoder.h, main.cpp, 4 tests
tools/ui_sim/           builds render.cpp + led_fx.cpp + the edition's keymap natively and writes PNGs
```

An edition's `main.cpp` is four lines: it hands its `Centre` (the stick or the knob)
to `app::begin()`. The `Centre` reads its hardware, tells the engine what to do, fills
its part of the UI snapshot, answers its FN-layer commands (JOY/CAL or KNOB/REV) and
its console commands, and keeps 16 bytes in the flash settings.

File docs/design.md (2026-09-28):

# Design notes

How the requirements turned into the case, why each part is held the way it is,
and what is verified automatically on every build.

There are two editions of the same case. They share the frame, the bar-display spine,
the layout, the electronics and the firmware, and differ only in the centre control:

- **joystick edition**: KY-023 thumbstick ([`joystick/`](../joystick), files in `joystick/cad/exports/`)
- **rotary edition**: KY-040 rotary encoder with a printed Ø30 knob ([`rotary/`](../rotary), files in `rotary/cad/exports/`)

The case model is one shared package (`common/cad/macropad_cad`); each edition adds its
centre control in its own `cad/edition.py`. Frame and bar spine come out identical.

Both have two RGB LED sticks on the base.

| Joystick edition | Rotary edition |
|---|---|
| Section A-A through the joystick, main display, Pico and USB port | Section A-A through the knob, encoder, main display, Pico and USB port |

## Requirements (from the brief and sketches)

| Requirement | Where it is solved |
|---|---|
| Wedge case, USB-C at the back, low and centred | 10° slope, port 8.6 mm above the desk, centred on the back wall |
| Top plate / centre plate in another colour / bottom base | three separate prints; the centre frame is the colour band all around |
| 4 keys next to a 76×284 bar display, 8 keys on the right, 1.9" display above a joystick | top layout below, taken 1:1 from the sketch |
| Hand-wired switches and diodes, no custom PCB, no extra USB socket | plate-mount MX cut-outs, Pico 2's own USB-C used through the wall |
| 3D printable, easy to assemble, screws (glue optional) | every part prints without supports; 8 identical case screws; nothing needs glue |
| Joystick **or** rotary knob | two editions of one shared model, each with its own `edition.py`; the rotary edition reuses the frame and spine |
| LED sticks on the base, either side of the Pico | two 8 × WS2812B sticks on screw posts, LEDs up; the translucent-frame option makes the colour band glow |

## Top layout

All positions are on the tilted top surface (u → right, v → up the slope), in mm.

| Element | u | v |
|---|---|---|
| 2.25" bar display window centre | 17.04 | 46.60 |
| Key column C0 | 38.53 | rows 19.52 / 38.58 / 57.62 / 76.67 |
| 1.9" display window centre | 80.53 | 67.15 |
| Joystick axis / knob axis | 80.53 | 27.00 |
| Key columns C1 / C2 | 122.53 / 141.58 | same rows |

Key pitch is 19.05 mm (standard 1u). The centre gap between the key columns is set
by the 1.9" module (62 mm PCB), and the window is kept centred over the joystick (or
knob) even though the active area is off-centre on that PCB. Plate borders are ~8 mm left/right,
10.5 mm front, 13.8 mm back (the back border carries the engraved logo, set
`logo = ""` in `params.py` to remove it).

## The stack

```
top plate  5.0 mm, tilted 10 deg   colour A   switches, displays, 8 hanging screw bosses
frame      9.9 mm (front) - 27.2 mm (back) walls, 3.0 mm thick   colour B, USB-C port
base       3.0 mm   colour A       Pico cradle, LED-stick posts, joystick posts*, countersinks, feet
                                   (* joystick edition only)
```

* The screw bosses belong to the **top plate** and hang straight down (world-vertical)
  inside the frame's corners and edges. M3 heat-set inserts sit at their lower ends,
  0.3 mm above the base. Eight **M3×8 countersunk** screws go up through the base.
  All eight are the same length regardless of the wedge.
* Because the bosses stop 0.3 mm short of the base, the screws pull the base and the
  plate together **through the frame** – the frame is the compression member, so the
  two colour seams close tightly.
* The frame has vertical saddles that wrap the bosses (locating it in X/Y); the plate
  has a 1.6 × 2.5 mm lip that drops inside the frame; the base has lip segments. The
  three parts self-align when stacked. 0.5 mm chamfers at both seams form V-grooves
  that hide small print differences.

## How each component is held

### MX switches (12)
14.0 × 14.0 cut-outs in a 1.5 mm skin (MX spec), with a 15.0 × 15.6 mm relief pocket
below so the clips can spring out under a 5 mm-thick, stiff plate. Switches clip in
from the top; wiring hangs below. Front-row wiring clears the base by 6.5 mm.

### 1.9" display (MSP1901-compatible module, 62 × 29 mm PCB)
Stepped pocket from below: glass (+0.25 mm), then PCB (+0.25 mm), with a 2 mm skin
above the glass and a 1.4 mm × 45° bevelled window around the visible area. A relief
groove clears the header solder joints on the glass side. Four **M2×4** self-tapping
screws through the module's own corner holes into blind pilots (0.7 mm of skin left
above, so nothing shows on top).

### 2.25" bar display (73.15 × 21.08 mm PCB, holes only at one end)
Same pocket scheme. The module has mounting holes at one end only, so the printed
**spine** clamps it: its crossbar is screwed with **2 × M2×8** through the module's two
holes, it arches 3 mm over the FPC / ZIF / parts on the back, and a pad presses the
PCB near the header end (0.2 mm preload). The header points to the front of the case
so the window can stay centred between the two corner bosses.

### KY-023 joystick
The stock knob's dome (Ø26.8) is a sphere around the stick's pivot; at 25° tilt its
rim sweeps down to ~6 mm above the module PCB. Posts hanging from the top plate at the
module's corner holes would sit inside that sweep, so the module stands on **four posts
that grow out of the base**, tilted 10° so the stick is perpendicular to the plate,
with **M3×6** self-tapping screws from above. The plate opening is Ø32 with a
1.5 mm bevel; the knob sweep (+0.4 mm) clears it by 0.7 mm at the underside. A 1.2 mm
relief in the base clears the solder joints under the module. The steel frame of the
stick sits 1.5 mm below the plate surface; the knob stands ~18.6 mm above the plate.

### KY-040 rotary encoder and knob (rotary edition)
The encoder is **panel-mounted** like a potentiometer: its M7 bushing goes up through a
Ø7.4 hole, and the washer and nut on top clamp a 2.0 mm section of the plate. From
below, a 12.5 mm square pocket takes the encoder body, so the module cannot turn when
the knob is turned hard. It hangs from the plate on its own. The base has no posts in
this edition, and the solder joints clear the base by 6.5 mm. The case height and the
frame are unchanged, so both editions share the frame and the spine.

The printed **knob** (Ø30 × 19, 36 flutes, indicator dimple) is a press fit on the
6 mm D-shaft. Its bore is round below the flatted part of the shaft and D-shaped where
the flat is (9.5 mm of D engagement), and it ends exactly at the shaft tip. So the knob
presses on until it stops at 1 mm above the plate, and a push on the knob goes straight
into the encoder's switch (0.5 mm travel, still clear of the plate). A recess under the
knob covers the nut, the washer and the bushing thread. Around the knob, a 0.8 mm
engraved ring (Ø36) frames it. A sunken well would have printed as a 34 mm bridge on
the visible face; the ring prints as two tiny bridges instead.

### RGB LED sticks (both editions)
Two 53 × 10 mm sticks of eight WS2812B LEDs lie on the base floor, one each side of the
Pico, running front to back as in the sketch. Each stick sits on **two Ø5 posts** at its
own mounting holes and is held by **2 × M2×5**. The posts hold the PCB 3 mm above the
floor, which leaves room for the solder joints and wires on the back of the stick's end
pads. The LEDs face up into the case: in a translucent frame the whole middle stripe
lights up in the layer colour, and in the joystick edition light also comes out around
the stick. The sticks stay 1.5 mm or more from everything else (bosses, switch wiring,
the joystick header), and are checked like every other component. Electrically they are
chained on one GPIO; see [wiring.md](wiring.md#rgb-led-sticks-both-editions).

### Pico 2 USB-C clone
The clone has **no mounting holes at the USB end**. It sits on two Ø4.2 standoffs at
the debug-end holes (**M2×5** self-tapping), a centre rail and a forward stop. The USB
end is held by the port itself: the back wall is thinned to 1.2 mm around the
receptacle with a 9.34 × 3.66 mm opening (0.2 mm clearance), and the receptacle face
ends flush with that thin wall. A 14 × 8.5 mm recess outside takes the plug overmold,
so any USB-C cable seats fully. Plugging pushes against the standoffs and the stop;
unplugging pulls against the wall.

## Heights

The front height (18 mm) is set by the joystick: steel frame 1.5 mm below the plate,
12.2 mm mechanism, 1.6 mm PCB and 1.5 mm of solder joints must fit above the base at
the lowest (front) edge of the tilted module. With 10° tilt the back is 35.3 mm. The
rotary edition keeps the same heights (the encoder would fit a lower case) so that the
frame is shared; the knob top is 44.8 mm above the desk. Change
`tilt_deg` / `front_h` in `common/cad/macropad_cad/params.py`; the fit checks will tell
you if something no longer fits (8° gives ~18.3 → 32 mm).

## Automated verification (`make cad-check`)

Every build runs:

* **Interference pairs** with manifold3d: **169** for the joystick edition, **191** for the
  rotary edition, **0 clashes**. Each printed part is tested against each component
  keep-out (component + solder joints + hand-wiring room), against the joystick knob's
  full sweep (all directions to 25°, plus 1.5 mm press travel) or the spinning knob's
  envelope, printed parts against each other, and components against each other
  (the LED sticks included).
* **Clearance report**: joystick joints above the base (1.9 mm), knob sweep vs opening
  (0.72 mm); encoder joints above the base (6.5 mm), knob above the plate (1.0 mm, 0.5
  while pressed), D-flat engagement (9.5 mm); LED joints above the base (1.5 mm), LED
  sticks to their nearest neighbour (1.5 mm); front switch wiring above the base
  (6.5 mm), frame wall behind a boss (1.95 mm), insert engagement (4.7 mm). The numbers
  are saved to `<edition>/cad/exports/checks.json` on every build.
* **Printability report** in print orientation: flags any down-facing surface steeper than
  50° and lists bridges. Current result: only small bridges (logo letters, the USB
  openings ≤ 8 mm, the Ø10.5 feet recesses, the engraved ring's 0.8 mm groove) and a
  1 mm edge chamfer at 50°.

## Dimensions that came from photos (measure these)

The display drawings and the KY-023 measurements are from published data; these values
were estimated from your photos and should be checked with calipers (they are marked
`MEASURE` in `common/cad/macropad_cad/params.py`, or in the edition's `cad/edition.py` for the centre control):

| Parameter | Default | What to measure |
|---|---|---|
| `Pico2.usb_overhang` | 1.3 | how far the USB-C receptacle sticks out past the PCB edge |
| `Pico2.t` | 1.0 | PCB thickness of your clone |
| `DisplayBar.lcm_x0` | 8.2 | bar module: hole-end PCB edge to the start of the glass |
| `DisplayBar.hole_x`, `hole_y` | 2.5, 8.15 | bar module hole position from the end / centre line |
| `DisplayBar.pcb_t` | 1.2 | bar module PCB thickness |
| `Display19.hole_d` | 2.2 | 1.9" module hole diameter (M2 must pass) |
| `JoystickKY023.hole_dx`, `hole_dy` | 26.7, 20.3 | joystick hole spacing (sources say 26.5–26.7 × 19.0–20.3) |
| `EncoderKY040.shaft_len` | 20.0 | encoder body top face to the shaft tip (15 / 20 / 25 mm versions exist) |
| `EncoderKY040.body_h`, `bushing_h` | 6.5, 6.0 | PCB top to the body's top face; bushing height |
| `EncoderKY040.pcb_l`, `pcb_w`, `axis_dx`, `axis_dy` | 24, 18, 1.4, 1.15 | module PCB size and where the shaft sits on it |
| `LedStick.pcb_l`, `pcb_w` | 53.0, 10.0 | LED stick PCB size |
| `LedStick.hole_pitch`, `hole_y`, `hole_d` | 26.4, 2.9, 2.5 | LED stick mounting holes: spacing, offset from the centre line, diameter |

The fit-test coupons check exactly these.

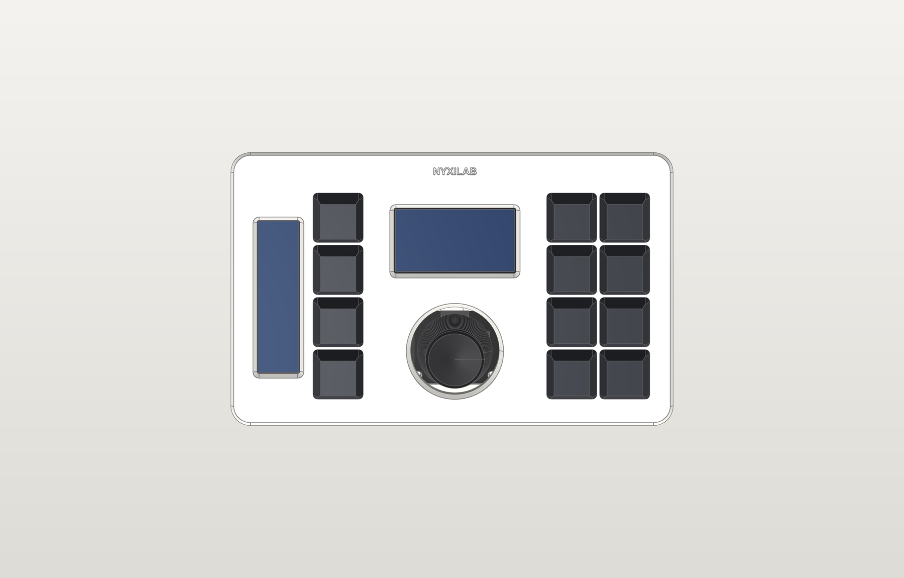
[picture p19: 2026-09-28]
docs/images/joystick/top.png

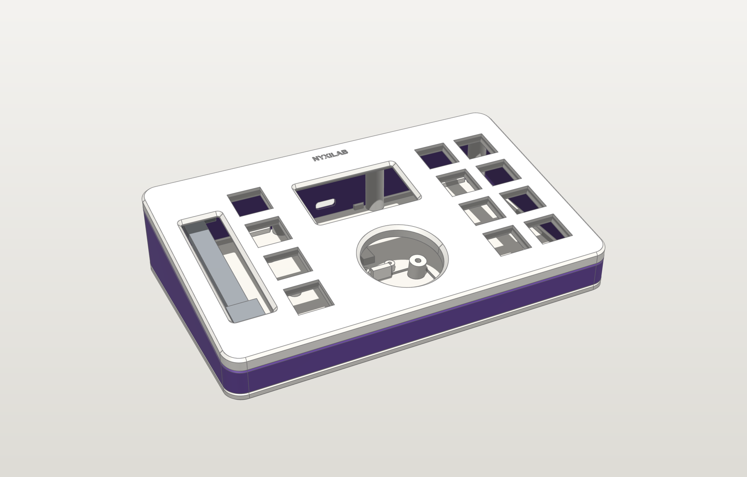
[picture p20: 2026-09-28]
docs/images/joystick/case_only.png

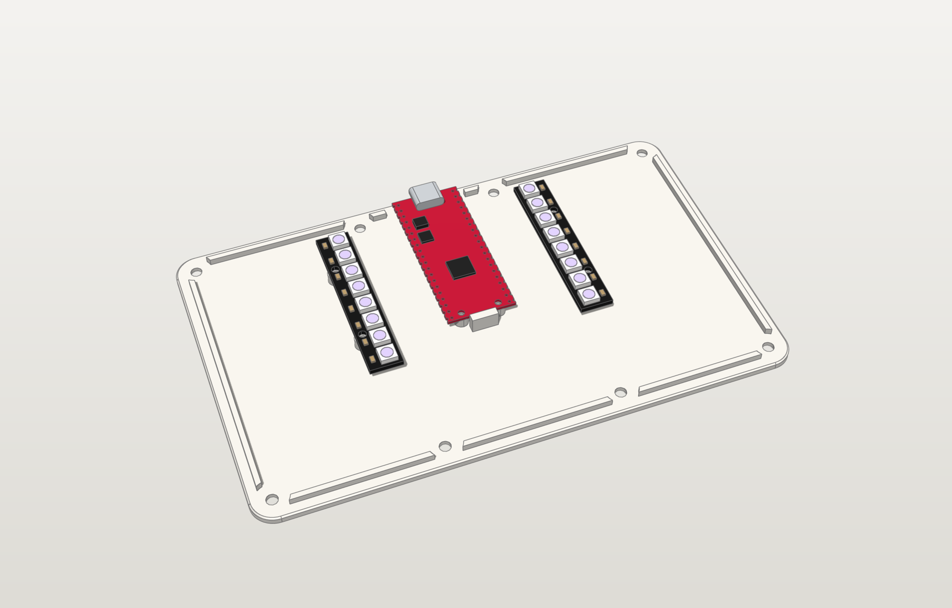
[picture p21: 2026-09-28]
docs/images/rotary/base_leds.png

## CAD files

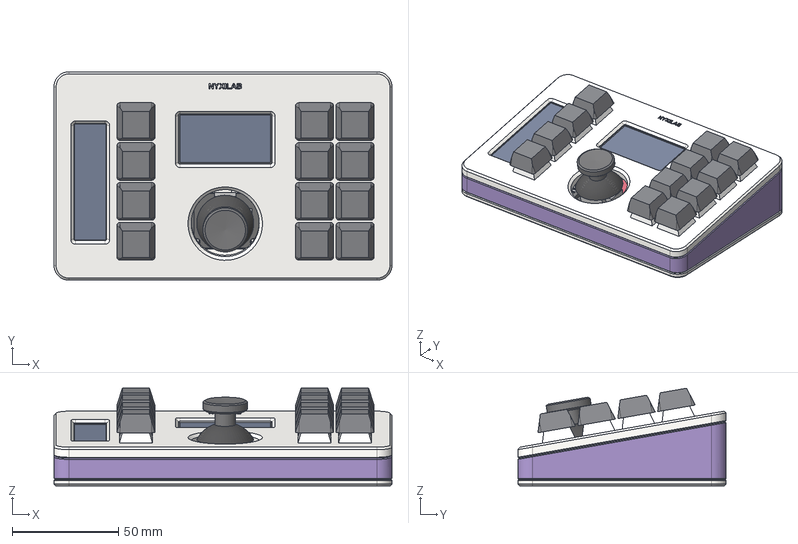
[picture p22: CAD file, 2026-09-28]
joystick/cad/exports/step/macropad_assembly.step
158.9 x 98.0 x 45.9 mm
top_plate
frame
base
bar_spine
switch K32 housing x 12
switch K32 stem x 12
switch K32 pins x 12
keycap K32 cap x 12
pico pcb
pico usb
pico chips
display 1.9 lcm
display 1.9 screen
display 1.9 pcb
display 1.9 back
display bar lcm
display bar screen
display bar pcb
display bar back
joystick pcb
joystick mech
joystick header
joystick knob
led L pcb x 2
led L led x 2
led L lens x 2
led L caps x 2

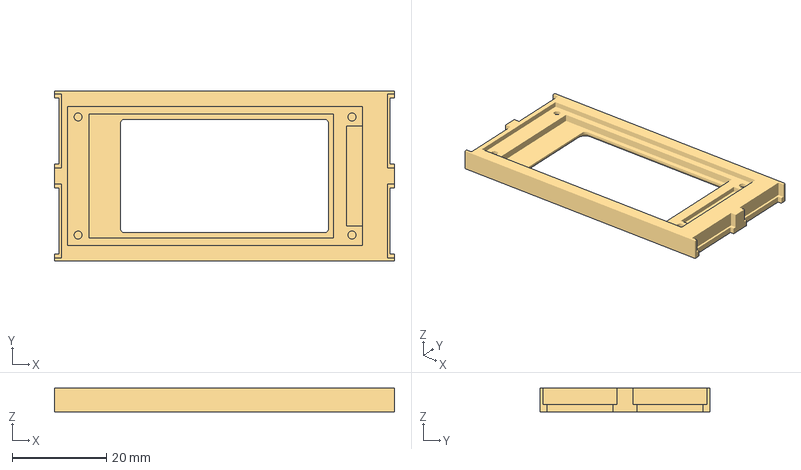
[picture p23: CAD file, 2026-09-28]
joystick/cad/exports/3mf/fit-tests/fit_plate_d19.3mf
72.0 x 36.0 x 5.00 mm

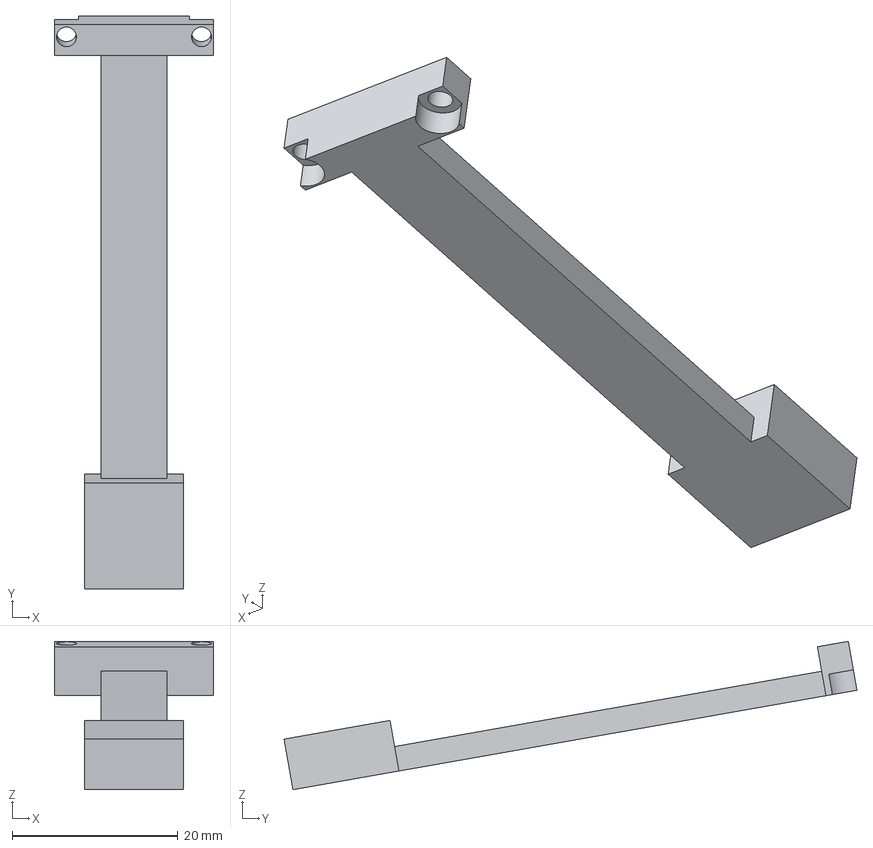
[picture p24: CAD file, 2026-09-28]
joystick/cad/exports/step/bar_spine.step
19.2 x 69.2 x 17.9 mm

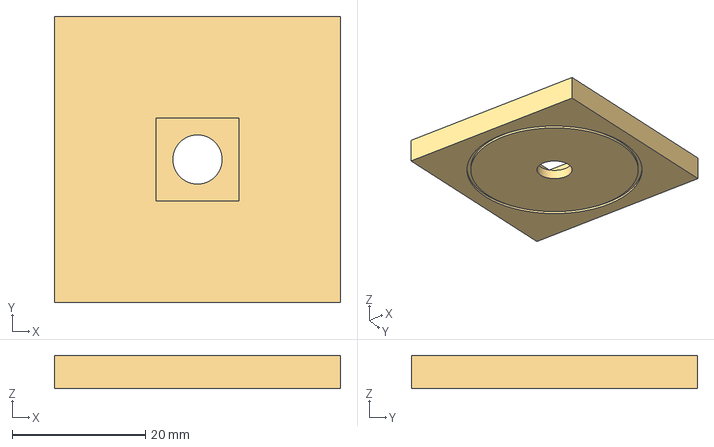
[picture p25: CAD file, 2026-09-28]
rotary/cad/exports/3mf/fit-tests/fit_plate_enc.3mf
43.0 x 43.0 x 5.00 mm

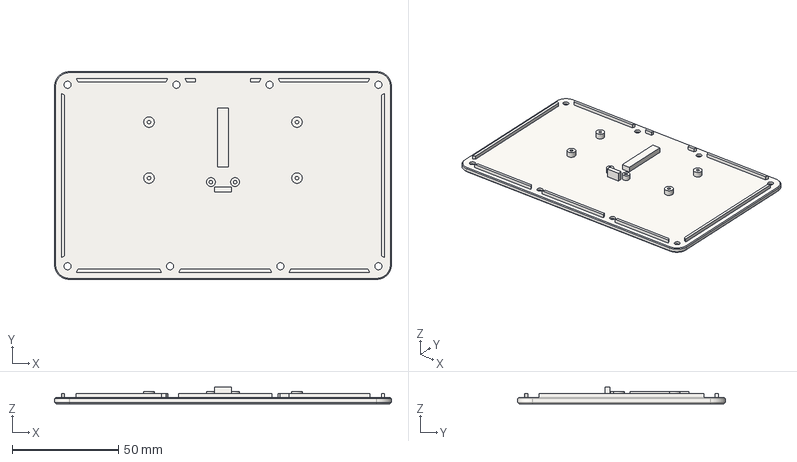
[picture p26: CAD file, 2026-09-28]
rotary/cad/exports/step/base.step
158.9 x 98.0 x 8.00 mm

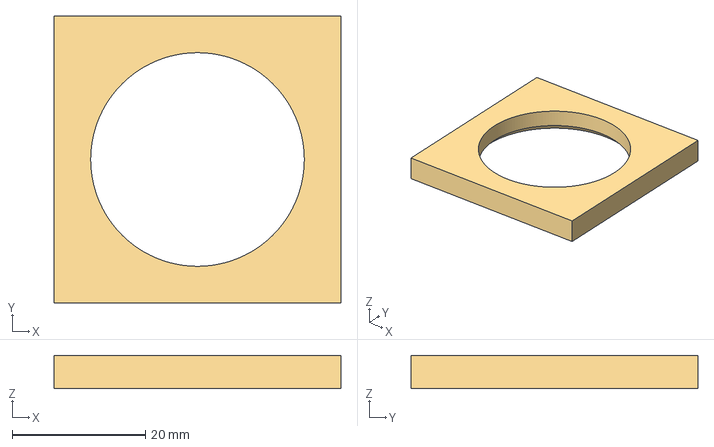
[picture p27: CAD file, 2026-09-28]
joystick/cad/exports/3mf/fit-tests/fit_plate_joy.3mf
43.0 x 43.0 x 5.00 mm

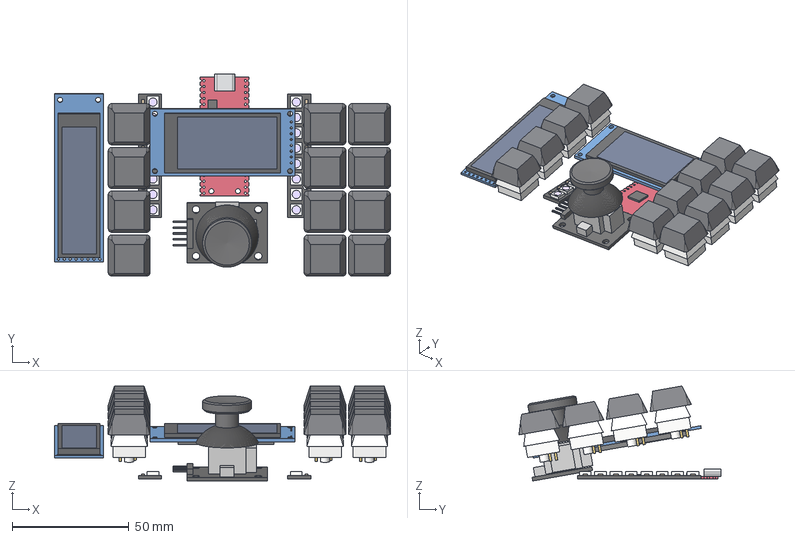
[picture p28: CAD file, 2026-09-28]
joystick/cad/exports/step/reference_components.step
144.1 x 86.7 x 40.7 mm
switch K32 housing x 12
switch K32 stem x 12
switch K32 pins x 12
keycap K32 cap x 12
pico pcb
pico usb
pico chips
display 1.9 lcm
display 1.9 screen
display 1.9 pcb
display 1.9 back
display bar lcm
display bar screen
display bar pcb
display bar back
joystick pcb
joystick mech
joystick header
joystick knob
led L pcb x 2
led L led x 2
led L lens x 2
led L caps x 2

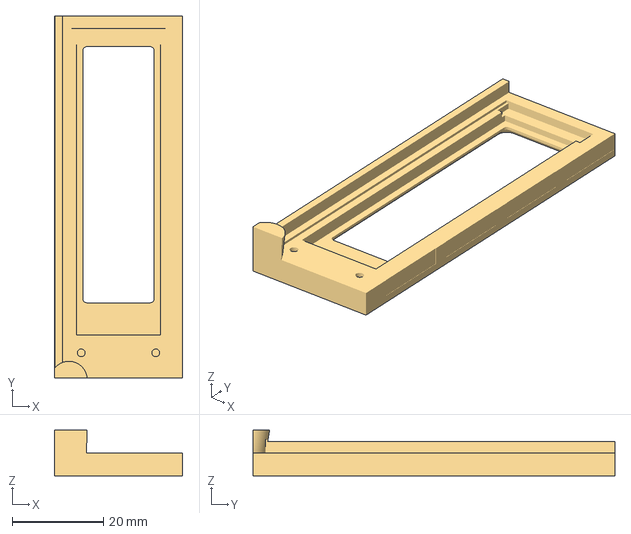
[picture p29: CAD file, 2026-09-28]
rotary/cad/exports/3mf/fit-tests/fit_plate_bar.3mf
28.1 x 79.2 x 10.0 mm

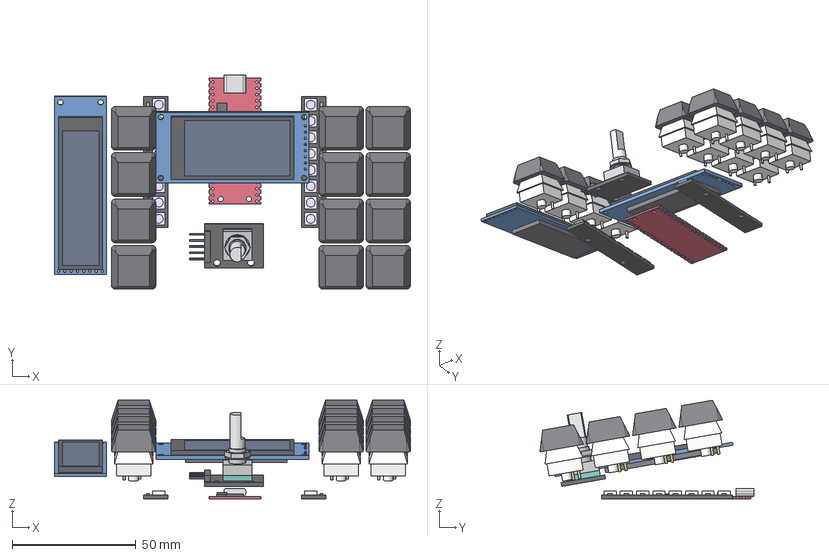
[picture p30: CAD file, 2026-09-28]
rotary/cad/exports/step/reference_components.step
144.1 x 86.7 x 39.9 mm
switch K32 housing x 12
switch K32 stem x 12
switch K32 pins x 12
keycap K32 cap x 12
pico pcb
pico usb
pico chips
display 1.9 lcm
display 1.9 screen
display 1.9 pcb
display 1.9 back
display bar lcm
display bar screen
display bar pcb
display bar back
encoder pcb
encoder enc_base
encoder mech
encoder shaft
encoder header
led L pcb x 2
led L led x 2
led L lens x 2
led L caps x 2

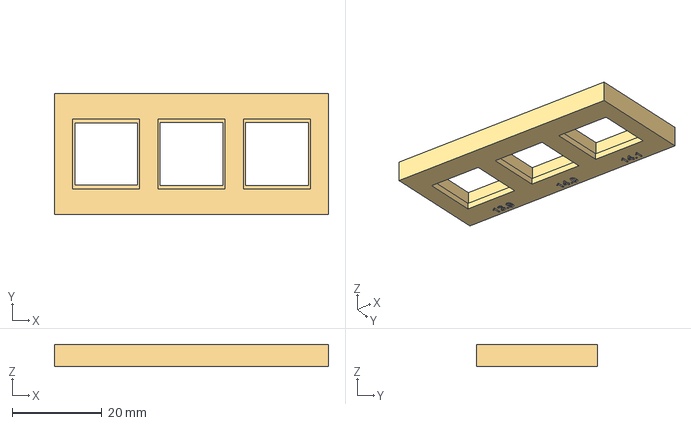
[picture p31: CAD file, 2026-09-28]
joystick/cad/exports/3mf/fit-tests/fit_switch.3mf
61.1 x 27.1 x 5.00 mm

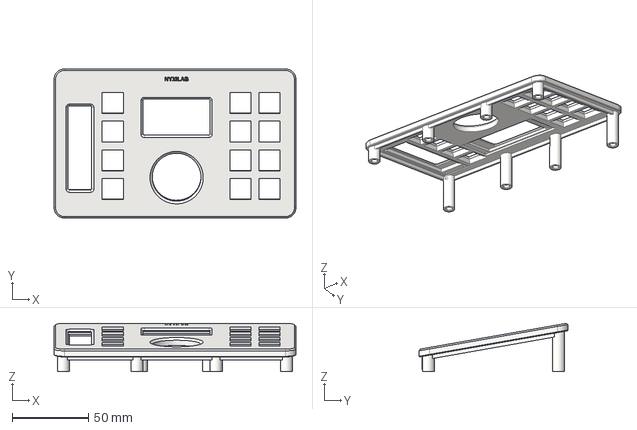
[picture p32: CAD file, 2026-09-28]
joystick/cad/exports/step/top_plate.step
158.9 x 98.0 x 31.8 mm

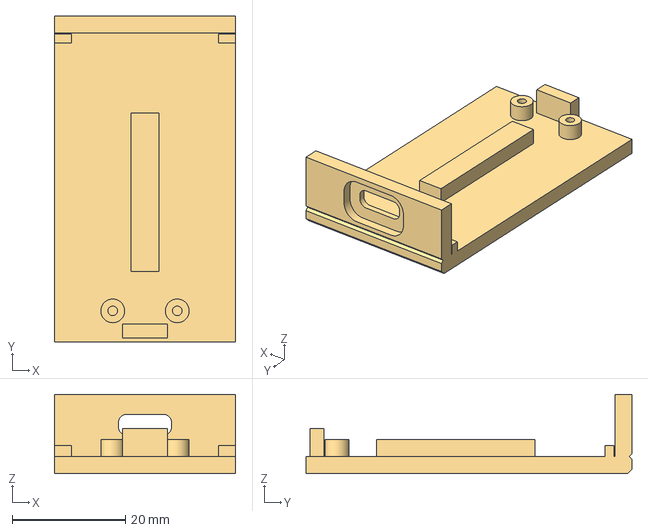
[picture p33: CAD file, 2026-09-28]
rotary/cad/exports/3mf/fit-tests/fit_usb.3mf
32.0 x 57.6 x 14.0 mm

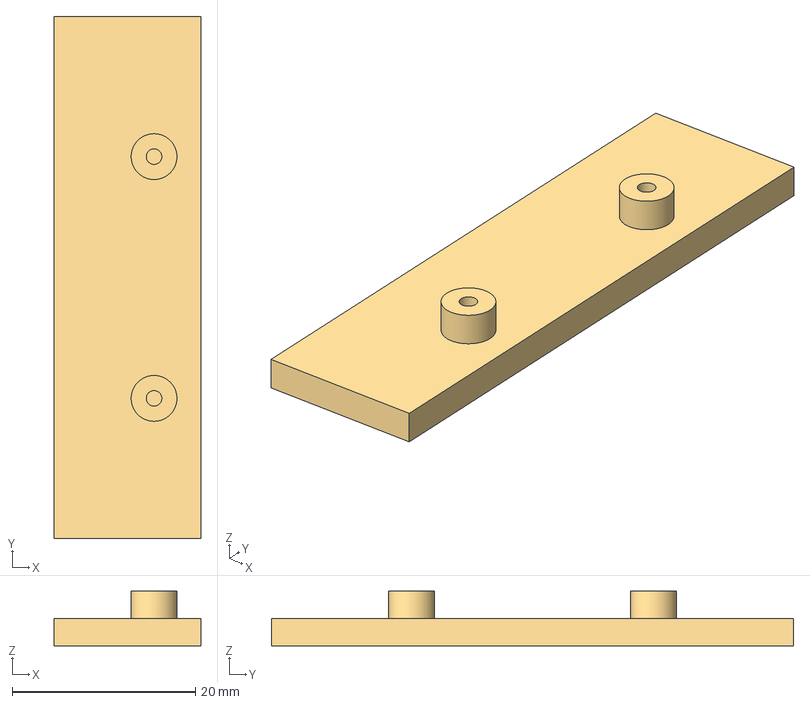
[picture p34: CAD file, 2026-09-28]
rotary/cad/exports/3mf/fit-tests/fit_led.3mf
16.0 x 57.0 x 6.00 mm

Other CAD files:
rotary/cad/exports/step/macropad_assembly.step
joystick/cad/exports/freecad/nyxilab_macropad_joystick.FCStd
rotary/cad/exports/freecad/nyxilab_macropad_rotary.FCStd
rotary/cad/exports/step/bar_spine.step
joystick/cad/exports/3mf/fit-tests/fit_plate_bar.3mf
joystick/cad/exports/3mf/bar_spine.3mf
joystick/cad/exports/3mf/base.3mf
joystick/cad/exports/3mf/fit-tests/fit_joystick.3mf
joystick/cad/exports/3mf/fit-tests/fit_led.3mf
joystick/cad/exports/3mf/fit-tests/fit_usb.3mf
joystick/cad/exports/3mf/frame.3mf
joystick/cad/exports/3mf/top_plate.3mf
joystick/cad/exports/step/base.step
joystick/cad/exports/step/frame.step
joystick/cad/exports/stl/bar_spine.stl
joystick/cad/exports/stl/base.stl
joystick/cad/exports/stl/fit-tests/fit_joystick.stl
joystick/cad/exports/stl/fit-tests/fit_led.stl
joystick/cad/exports/stl/fit-tests/fit_plate_bar.stl
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

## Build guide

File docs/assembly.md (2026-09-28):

# Assembly

| Joystick edition | Rotary edition |
|---|---|
| Exploded view, joystick edition | Exploded view, rotary edition |

Both editions share the frame, the bar-display spine, the displays, the keys, the Pico
and the two RGB LED sticks. They differ in the centre control, the top plate and the
base (the joystick stands on posts in the base; the encoder hangs from the plate).

## Bill of materials

| Qty | Part | Notes |
|---|---|---|
| 1 | Raspberry Pi Pico 2 (RP2350), USB-C version | the original Pico (RP2040) also works |
| 12 | MX-style switches | plate-mount (3-pin) or PCB-mount (5-pin, clip the two plastic legs or leave them) |
| 12 | 1u MX keycaps | any profile |
| 12 | 1N4148 diodes | through-hole |
| 1 | 1.9" 170×320 ST7789 IPS module, 8-pin (GND VCC SCL SDA RES DC CS BLK) | |
| 1 | 2.25" 76×284 ST7789P3 module, 8-pin (GND VCC SCL SDA RST DC CS BL) | |
| 2 | WS2812B LED stick, 8 × 5050 on a 53 × 10 mm PCB (CJMCU-2812-8 style) | chained, on the base |
| 1 | 1N4001 (any 1N400x) diode | LED 5 V feed, see [wiring](wiring.md#rgb-led-sticks-both-editions) |
| 1 | 330 Ω resistor | LED data line |
| 8 | M3 heat-set inserts, 5.7 × 4.6 mm | |
| 8 | M3 × 8 countersunk screws (ISO 10642 / DIN 7991) | case |
| 4 | M2 × 4 pan-head self-tapping screws | 1.9" display |
| 2 | M2 × 8 pan-head self-tapping screws | bar display + spine |
| 6 | M2 × 5 pan-head self-tapping screws | Pico (2), LED sticks (4) |
| 4 | Rubber feet Ø10 × 3 mm (3M Bumpon or similar) | |
| – | 26–28 AWG silicone wire (or 30 AWG wire-wrap), ~2.5 m in several colours | |
| – | Kapton tape, heat-shrink tubing, small cable ties | wire dressing |

**Joystick edition** adds:

| Qty | Part | Notes |
|---|---|---|
| 1 | KY-023 / HW-504 thumb joystick module | |
| 4 | M3 × 6 pan-head self-tapping screws | joystick posts |

**Rotary edition** adds:

| Qty | Part | Notes |
|---|---|---|
| 1 | KY-040 rotary encoder module (EC11, 20 detents, M7 bushing, 6 mm D-shaft) | its washer and M7 nut hold it in the plate |
| 1 | printed knob | `rotary/cad/exports/3mf/knob.3mf` |

Tools: soldering iron (with a heat-set insert tip if you have one), flush cutters,
2.5 mm hex / Phillips #0 and #1 drivers, a small wrench or pliers for the encoder nut,
multimeter.

## 1 · Prepare the printed parts

1. Remove any stringing from the switch cut-outs and display windows.
2. Press the **8 heat-set inserts** into the boss ends of the top plate
   (see [printing.md](printing.md#heat-set-inserts)).
3. Stick the **rubber feet** into the four recesses under the base.
4. Rotary edition: try the **knob** on the encoder shaft now. It should need a firm push
   and not wobble; see [printing.md](printing.md#the-knob-rotary-edition) if it does not.

## 2 · Build the top plate

1. **Switches**: push all 12 switches into the plate from the top until both clips snap.
   Orient them the same way (e.g. the two metal pins towards the back).
2. **1.9" display**: lay the plate top-down, drop the module glass-first into its
   pocket (header towards the right-hand key block), and fix it with **4 × M2×4**.
   Snug, not tight – the screws cut their own thread.
3. **2.25" bar display**: drop it into the long pocket, header towards the *front*.
   Put the **spine** over its back (crossbar at the hole end, pad at the header end)
   and drive **2 × M2×8** through the spine and the module's two holes.
4. **Rotary edition – encoder**: take the nut and washer off the KY-040, push its bushing
   up through the round hole from below, header pointing left (towards the left key
   column; that is the orientation the fit checks cover). The square encoder body drops
   into the square pocket, which stops it from turning. From the top, fit the washer
   and the nut and tighten gently: the nut clamps a 2 mm section of the plate. Don't fit
   the knob yet.
5. Peel the protective films off the display glass (from the top) now or at the very end.

## 3 · Hand-wire the matrix

Follow the [soldering guide](soldering.md) (it has step-by-step pictures) and the
[matrix diagram](wiring.md#key-matrix). In short:

1. Solder a **1N4148** to one pin of every switch, cathode band pointing away from the
   switch, towards where the row wire will run.
2. **Rows** (4 wires): join the diode cathodes of each physical row – left key, then
   across under the display / centre-control area to the two right keys. Row 0 is the
   back row.
3. **Columns** (3 wires): join the other switch pin of every key in a column, front to back.
4. Check with a multimeter (diode mode): column → row conducts through a pressed key only.

Keep wires flat against the plate underside and away from the joystick opening (or the
encoder); a few bits of Kapton tape help.

## 4 · Wire the modules, the LEDs and the Pico

Use the [wiring diagram](wiring.md) and the [wiring map](soldering.md#the-wiring-map).
Cut every wire from the top plate to reach the Pico's position at the back centre
**plus ~8 cm of slack**, so the top plate can be opened like a book later.

- **Displays**: 8 wires each, soldered from the back of the module (the relief grooves in
  the plate clear the solder on the glass side).
- **Joystick** (5 wires) or **encoder** (5 wires): **power it from 3V3, not 5 V.**
  Remove the right-angle header or solder to it; there is room for either.
- **LED sticks** (these stay in the base, so their wires only need to reach the Pico):
  1. Right stick, DIN end: three wires to the Pico: 5V → VBUS (pin 40) with the
     **1N4001** in line (band towards the stick), GND → pin 38, DIN → GP28 (pin 34) with
     the **330 Ω** in line close to the stick. Heat-shrink both.
  2. A three-wire jumper, about 70 mm, from the right stick's DOUT end (5V, GND, DOUT) to
     the left stick's DIN end (5V, GND, DIN). In the case the two sticks point in opposite
     directions, so this jumper runs across the front of the Pico.
  3. Solder to the pads on the back of the sticks and keep the joints flat. The posts
     leave 3 mm under the sticks for them.
- Solder all wires to the Pico from the top.

Flash the firmware now (drop the UF2 for your edition onto the `RP2350` drive while
holding BOOTSEL; see the [firmware README](../common/firmware/README.md)) and test every key,
both displays, the stick or the knob, and the LEDs before closing the case. The LEDs
should light in the layer colour and flash on every key press. The serial console
(`make monitor`) prints raw values with the command `joy` or `enc`.

## 5 · Mount the LED sticks, the joystick and the Pico in the base

1. **LED sticks**: LEDs up, one each side of the Pico's cradle, with the mounting holes
   over the posts (the holes are on the outer side of each stick). The **right** stick
   has its DIN end at the back, the **left** stick has its DIN end at the front. Fix each
   stick with **2 × M2×5**.
2. Place the **frame** on the **base** (the lip segments locate it).
3. Joystick edition: set the **joystick** on its four posts, header to the left,
   click-switch towards the front, and fix it with **4 × M3×6** from above.
4. Insert the **Pico**: tilt it, push the USB-C receptacle into the opening in the back
   wall, lower the far end onto the two standoffs and fix it with **2 × M2×5**.
   A cable must now plug in fully from outside.

## 6 · Close the case

1. Fold the wires into the case: keep them out of the joystick opening and away from the
   stick's mechanism, and don't cover the LEDs.
2. Lower the top plate onto the frame: the joystick knob passes through its opening (or
   the encoder module hangs into the space in front of the Pico), the lip drops inside
   the frame and the bosses slide into their saddles.
3. Turn the pad over and drive the **8 × M3×8 countersunk** screws. Tighten evenly in a
   cross pattern until the seams close – do not overtighten.
4. Fit the keycaps.
5. Rotary edition: turn the shaft so its flat points where you want the indicator dot to
   start, line up the flat in the knob's bore and **press the knob on until it stops** on
   the shaft tip. It then sits 1 mm above the plate, and pushing the knob presses the
   encoder's switch.

## Opening it again

Pull the knob off (rotary edition), remove the 8 bottom screws and lift the top plate; it
stays connected to the Pico by the wires. The Pico comes out with its two screws; tilt
it out of the port. The LED sticks and their wiring stay in the base.

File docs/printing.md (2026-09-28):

# Printing

All parts print **without supports** and fit a 180 × 180 mm bed. The files are already
oriented; just drop them on the plate:

- joystick edition: `joystick/cad/exports/3mf/` (and `stl/`)
- rotary edition: `rotary/cad/exports/3mf/` (and `stl/`). The frame and the bar spine
  are the same parts in both editions; the top plate and the base differ, and the
  rotary edition adds the knob.

Or grab the zips from the [downloads page](https://worxbend.github.io/macropad-nyxilab/downloads.html).

| Part | Colour | Bed footprint | Height | Orientation | Settings |
|---|---|---|---|---|---|
| `top_plate` | A (e.g. white) | 159 × 100 mm | 31 mm | top face **down** | 0.2 mm layers, 4 walls, 20 % gyroid, 5 top/bottom layers |
| `frame` | B (accent, e.g. violet) | 159 × 98 mm | 27 mm | flat bottom down | 0.2 mm, 3 walls, 15 % infill |
| `base` | A | 159 × 98 mm | 10 mm | flat bottom down | 0.2 mm, 3 walls, 20 % infill |
| `bar_spine` | any | 69 × 19 mm | 6 mm | flat side down | 0.2 mm, 100 % infill |
| `knob` (rotary) | B, like the frame | Ø30 mm | 19 mm | top face **down** | 0.12–0.16 mm layers, 4 walls, 30 % infill |

Material: PLA or PETG both work. PETG is a little tougher for the self-tapping screws
and the clips of the switches; PLA gives crisper edges. Approximate filament use:
top plate ~60 g, frame ~30 g, base ~50 g, knob ~12 g.

**Make the LEDs visible: print the frame translucent.** The two RGB sticks sit inside
the case, pointing up. In an opaque frame you mostly see them through the gap around the
joystick. Print the **frame** in translucent or "transparent" PETG (clear, frosted, or a
translucent colour) and the whole middle stripe glows in the layer colour. A white PLA
frame also lets some light through. 3 walls and 15 % infill are fine for this; for a more
even glow use 100 % infill, or 0 % infill with 4 walls.

**Top plate tips**
- Printing the top face down gives a flat, bed-textured top surface. A textured PEI
  sheet makes a nice matte finish; a smooth sheet gives gloss.
- The 1.5 mm switch skin and the 2 mm display skin are the first layers – level the bed
  well and use a normal (not squished) first layer so the 14.0 mm holes stay accurate.
- The screw bosses stand up to 26 mm tall; print them at normal speed with the part fan on.

**Frame tips**
- Use the brim only if your printer lifts corners; the 0.5 mm bottom chamfer already
  compensates elephant's foot.
- The USB-C opening has two short bridges (≤ 8 mm) – default bridge settings are fine.

**Base tips**
- The four LED-stick posts and the Pico standoffs are small; slow down the outer walls
  a little if they come out stringy.

## The knob (rotary edition)

- Print it **top face down** (as exported). The fluted grip then runs straight up the
  sides and the indicator dimple stays crisp; the top chamfer prints fine at 45°.
- Use fine layers (0.12–0.16 mm) for a smooth grip, 4 walls so the D-bore has solid
  walls, and no brim.
- The bore is a press fit on the 6 mm D-shaft and ends exactly at the shaft tip, so the
  knob stops at the right height (1 mm above the plate). Too tight or too loose? Change
  `Knob.bore_clear` in `rotary/cad/edition.py` (default 0.10 mm; 0.05 is tighter,
  0.20 looser), run `make cad-rotary` and reprint just the knob. It is a 30-minute print.
- Shaft lengths vary between KY-040 batches (15, 20 and 25 mm exist). Measure from the
  top of the encoder body to the shaft tip and set `EncoderKY040.shaft_len`.

## Print the fit tests first

`<edition>/cad/exports/3mf/fit-tests/` (≈1 h in total, a few grams each):

| Coupon | What to check |
|---|---|
| `fit_switch` | three cut-outs 13.9 / 14.0 / 14.1 mm – a switch should click in and not wobble |
| `fit_plate_d19` | 1.9" module drops into its pocket, glass touches the skin, the four M2 holes line up |
| `fit_plate_bar` | 2.25" module fits the pocket, the two M2 holes line up with the hole end |
| `fit_plate_joy` | joystick edition: the knob tilts fully in every direction without touching the bevel |
| `fit_plate_enc` | rotary edition: the KY-040 body drops into the square pocket, the washer and nut clamp it |
| `fit_usb` | Pico 2 on its standoffs, USB-C receptacle sits in the port, a cable plugs in fully |
| `fit_joystick` | joystick edition: the KY-023 holes line up with the four posts |
| `fit_led` | an LED stick lies flat on the two posts and both holes line up |

For the rotary edition, also print the knob early: it is the best test of the shaft fit.

If a coupon is off, measure the part and change the matching value in
`common/cad/macropad_cad/params.py` or the edition's `edition.py` (values marked
`MEASURE` are the likely suspects – see
[design.md](design.md#dimensions-that-came-from-photos-measure-these)), then `make cad`.
Common adjustments:

- switches loose / tight → `MXSwitch.hole` (13.9–14.1)
- modules too tight in their pockets → `PrintTol.pocket` (default 0.25)
- plate lip too tight in the frame → `PrintTol.fit` (default 0.20)
- LED stick holes don't match the posts → `LedStick.hole_pitch` / `hole_y`

## Heat-set inserts

Eight **M3 × 5.7 × 4.6 mm** inserts (Ruthex RX-M3x5.7 / CNC Kitchen standard M3) go into
the lower ends of the top-plate bosses (hole Ø4.0 × 6.2, with a lead-in chamfer).
Lay the plate top-down on the table: the bosses lean 10° (they are vertical in the
assembled case), so tilt the soldering iron to follow the boss axis. Press to flush,
let cool.

No inserts? Change `Fasteners.insert_d` to `2.6` and use M3 self-tapping screws
(e.g. M3 × 8 countersunk plastite) – fine for a few assembly cycles.

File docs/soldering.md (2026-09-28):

# Soldering guide

Everything in this pad is hand-wired: no PCB, just switches, diodes, wire and the
modules' own pin headers. This guide takes you from a bare top plate to a wired
pad, step by step. Read it once before you heat the iron, then keep the
[wiring map](#the-wiring-map) next to you.

What you will solder:

| Part | Joints | Wires to the Pico |
|---|---|---|
| 12 MX switches + 12 diodes | 12 diodes, 4 row buses, 3 column wires | 7 (4 rows, 3 columns) |
| 1.9" display | 8 pins | 8 |
| 2.25" bar display | 8 pins | 8 |
| KY-023 joystick **or** KY-040 encoder | 5 pins | 5 |
| 2 × WS2812B LED sticks | 6 pads + a 3-wire jumper | 3 (5V through a diode, GND, data through a resistor) |
| Pico 2 | 31 pins, soldered from the top | – |

About two evenings of work if it is your first hand-wired build.

## Tools and materials

- **Soldering iron** with a fine chisel or conical tip, temperature controlled.
  320–350 °C for leaded solder (63/37 or 60/40 flows best), 350–380 °C for
  lead-free. A cheap pen iron works; a T12 / Pinecil-class iron makes it much easier.
- **Solder** 0.6–0.8 mm, with a flux core. A **flux pen** or gel flux for the
  display headers and the LED pads.
- **Wire**: 26–28 AWG silicone-insulated stranded wire, ~2.5 m in 5–6 colours
  (a colour per signal group keeps you sane: rows, columns, power, SPI, LED). 30 AWG
  wire-wrap wire also works and is easier to route, but breaks more easily.
- Flush cutters, wire strippers (for 26–30 AWG), fine tweezers, a "helping hands"
  or a small vice, Kapton tape, 2 mm heat-shrink, isopropyl alcohol.
- **Multimeter** with a diode / continuity mode. You will use it after every step.
- Fume extraction or an open window. Solder fumes are flux smoke; don't breathe them.

## Soldering basics (60 seconds)

1. Tin the tip: melt a little solder on it, wipe on brass wool. A shiny, wet tip
   transfers heat; a black, dry tip does not.
2. Heat **the joint**, not the solder: touch the tip to the pin *and* the wire or pad
   for a second, then feed solder into the joint from the other side. It should wick
   in by itself. Two to three seconds per joint.
3. Take the solder away, then the iron, and don't move the parts for a second while
   it sets. A good joint is smooth and concave (shiny with leaded, satin with
   lead-free). A dull, grainy blob is a cold joint: reheat it with a little flux.
4. Strip 3–4 mm of insulation and **tin the wire end** before you bring it to the
   pin. Tinned wire + tinned pin = a joint in one second.
5. Keep joints small. Inside this case there is 3 mm of room above the Pico, 1.5 mm
   under the joystick and the LED sticks, and the diode legs run 1.5 mm below the
   switch pins.

## How the key matrix works

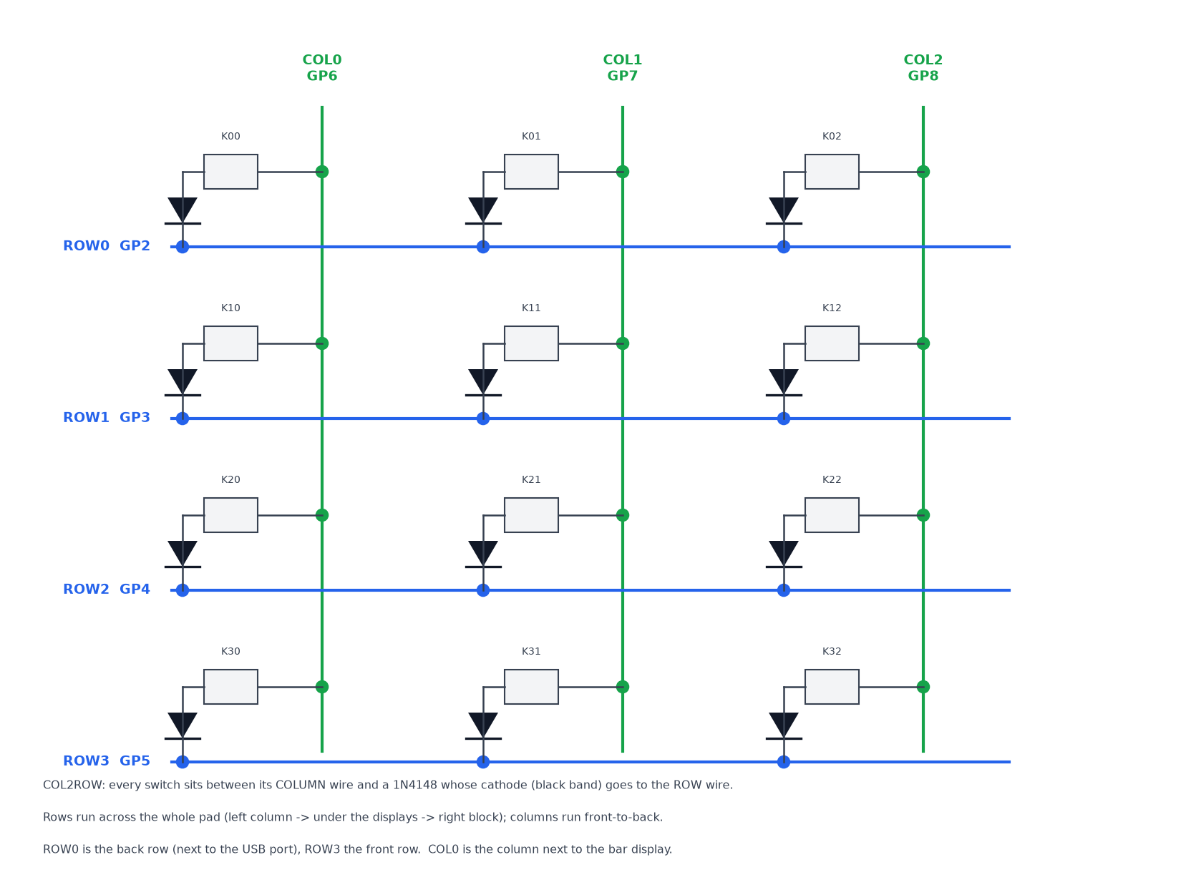
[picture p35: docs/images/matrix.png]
Matrix schematic


12 keys would need 12 pins; a matrix needs 7. The switches are wired in a grid of
**4 rows** (back to front) and **3 columns** (left to right). The firmware pulls one
row low at a time and reads the three columns with pull-up resistors: a pressed key
connects its column to the low row.

The **diode** in series with every switch is what makes it work with several keys
held at once. Without diodes, three pressed keys can pretend a fourth one is pressed
("ghosting"). Current must only flow **from the column, through the switch, through
the diode, into the row** (this is called COL2ROW), so every diode points the same
way: **the black band towards the row wire**.

## Step 1 · Diodes on the switches

One switch, one diode

Every MX switch has two metal contact pins on its underside (the round plastic post
and the two plastic legs are not connected to anything). Call them **pin A** (the one
nearer the switch's centre line) and **pin B**. Pin A gets the diode, pin B gets the
column wire. Be consistent: use the same pin for the diode on all 12 switches.

For each of the 12 switches:

1. Bend the **cathode** leg (the end with the **black band**) 90° about 3 mm from
   the body. Cut the **anode** leg to about 4 mm.
2. Hold the diode with tweezers, the short anode leg touching pin A, the body lying
   flat against the switch bottom and the long bent leg pointing towards where the
   row wire will run (towards the *front* of the plate when the plate is upside
   down, see the map below).
3. Heat pin A and the leg together, feed a little solder. Done.
4. Check: band **away** from the switch, pointing at the row.

> [!TIP]
> Do all 12 diodes with the plate upside down on a folded cloth, the switches
> already clipped in. Work row by row so all the bent legs point the same way.

## Step 2 · Row wires

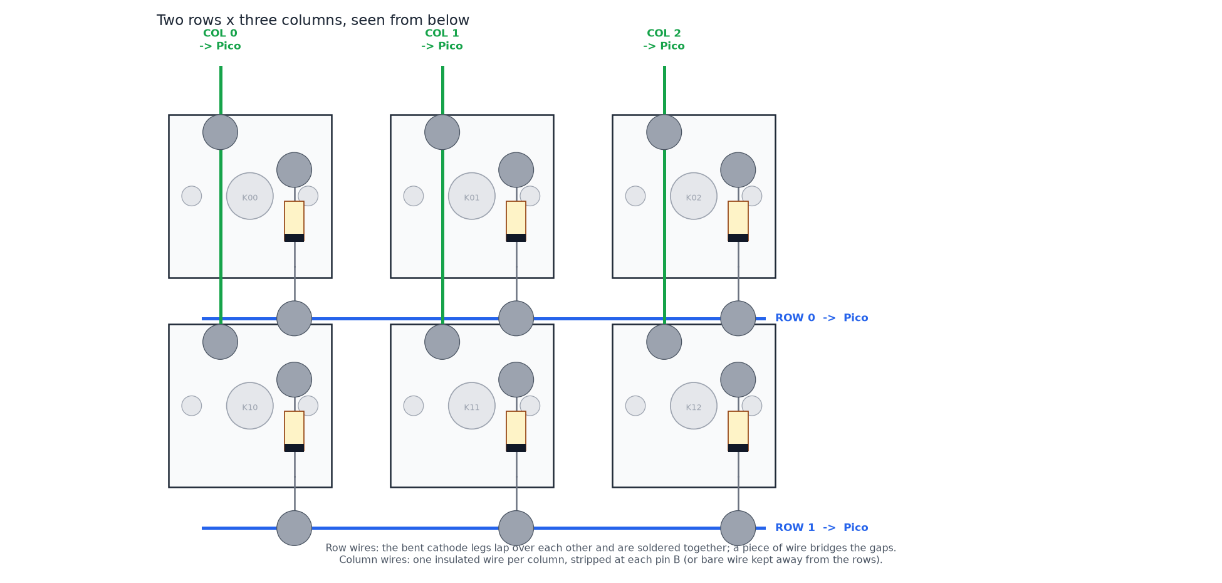
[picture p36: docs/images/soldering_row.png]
A row of switches, seen from below


The bent cathode legs of one row **are** the row wire: bend them so each leg reaches
the next diode's leg, overlap the ends by 5 mm and solder the overlaps. Where the
distance is longer (across the centre of the pad, between the left column and the
right block), bridge the gap with a piece of bare or insulated wire.

- **Row 0** is the *back* row (next to the USB port), row 3 the *front* row.
- Rows 0 and 1 run straight across; they pass **over the back of the 1.9" display
  module** (lay them flat, Kapton them down).
- Rows 2 and 3 have the joystick module (or the encoder) in their way. Route them
  **around the front** of it, as drawn on the wiring map: down between the module
  and the front bosses, then back up.
- Nothing may cross a row wire bare. Where a row crosses a column, one of them must
  be insulated.
- Finish each row with a 15 cm wire (leave slack, it gets trimmed at the Pico) and
  label it: R0 … R3.

## Step 3 · Column wires

One insulated wire per column, running **front to back** over pin B of every switch
in that column:

1. Cut the wire to the column length plus 15 cm towards the back.
2. At every switch, cut a 3 mm window in the insulation (strip the middle, or nick it
   with the strippers and slide the insulation apart), tin the bare copper, lay it
   on pin B and solder.
3. Column 0 is the single column next to the bar display, columns 1 and 2 the block
   on the right. Label the three tails: C0 … C2.

Alternative: bare wire for the columns and *insulated* row bridges. Either way, one
of the two must be insulated wherever they cross.

## Step 4 · Test the matrix before anything else

Multimeter in **diode mode**. Red probe on a **column** tail, black probe on a **row**
tail:

- key at that row/column **pressed**: the meter shows ~0.6 V (the diode drop)
- key **not** pressed: OL / no reading
- reading in the other probe direction, or a reading without pressing: that diode is
  backwards or a leg touches something. Fix it now, it is much harder later.

Check all 12 keys. Ten seconds each.

## Step 5 · The displays

Both displays have an 8-pin header with the pads on **both** sides of the PCB. The
glass side lies in the plate pocket, so solder the wires to the **back** side of the
module (the side with the components). The plate has a relief groove over the pin
row, so a little solder on the glass side is fine too.

1. Cut 8 wires per display, about 20 cm (the plate must open like a book later).
   Use the same colour order for both displays: GND black, VCC red, SCL, SDA, RES,
   DC, CS, BL.
2. Tin the wire ends, tin the pads, solder from the back, one pin at a time. Flux
   helps; the pads are small.
3. Tug-test every wire. Bundle the 8 wires with a bit of heat-shrink 3 cm from the
   header, so no single joint takes the strain.
4. Check with the continuity mode that no two neighbouring pins are bridged.

The 1.9" module's header ends up on the **right** in the top view (under the right
key block); the bar display's header points to the **front**.

## Step 6 · The joystick or the encoder

Five wires, 20 cm, to the module's 5-pin right-angle header. Solder to the header
pins (heat-shrink each joint) or unsolder the header and solder straight to the
board: both fit. Label them:

- **Joystick (KY-023)**: GND, +5V (goes to **3V3**, not 5 V!), VRx, VRy, SW.
- **Encoder (KY-040)**: GND, + (goes to **3V3**), SW, DT, CLK.

## Step 7 · The LED sticks

Each 8-LED stick has three pads at **both** ends on its back: 5V, GND, and DIN at
one end / DOUT at the other. The arrow on the LEDs points from DIN to DOUT.

1. **Right stick, DIN end** (this end faces the back of the case): three wires to
   the Pico, about 12 cm.
   - 5V wire: solder the **1N4001 diode** into it, band (cathode) towards the stick.
     Heat-shrink it.
   - Data wire: solder the **330 Ω resistor** into it, 2 cm from the stick.
     Heat-shrink it.
   - GND: plain wire.
2. **Right stick DOUT end → left stick DIN end**: a three-wire jumper (5V, GND,
   DOUT→DIN), about 70 mm. In the case the two sticks point in opposite directions,
   so both of these ends are at the *front* and the jumper runs across in front of
   the Pico.
3. Keep every joint **flat**: the sticks sit on 3 mm posts and the joints hang
   underneath. Tin the pad, tin the wire, lay the wire *along* the pad, tack it.
4. Continuity check: 5V must not touch GND on either stick.

## Step 8 · The Pico

The Pico sits on 3 mm standoffs with 1 mm under it, so all wires are soldered to the
**top** (component) side:

1. Tin each pad you will use.
2. Lay the tinned wire end into the hole from the top, at a shallow angle, and heat
   pad + wire together. The joint stays low. Don't push wires through and solder
   underneath: there is no room.
3. Work from the [pin map](wiring.md#pin-map), one group at a time: rows, columns,
   the 1.9" display, the bar display, the centre control, the LEDs, power.
4. Every GND can go to any GND pin; the joystick's ground is nicer on AGND (pin 33).
   All module VCCs go to **3V3 (pin 36)**, only the LED 5 V goes to VBUS (pin 40).

Cut the wires from the plate to reach the Pico's place at the back of the base **plus
~8 cm of slack**.

## The wiring map

Where everything actually is, drawn from the CAD model. Left: the top plate seen from
below, as it lies on your bench (so left and right are mirrored!). Right: the base
seen from above.

**Joystick edition**

Wiring map, joystick edition

**Rotary edition**

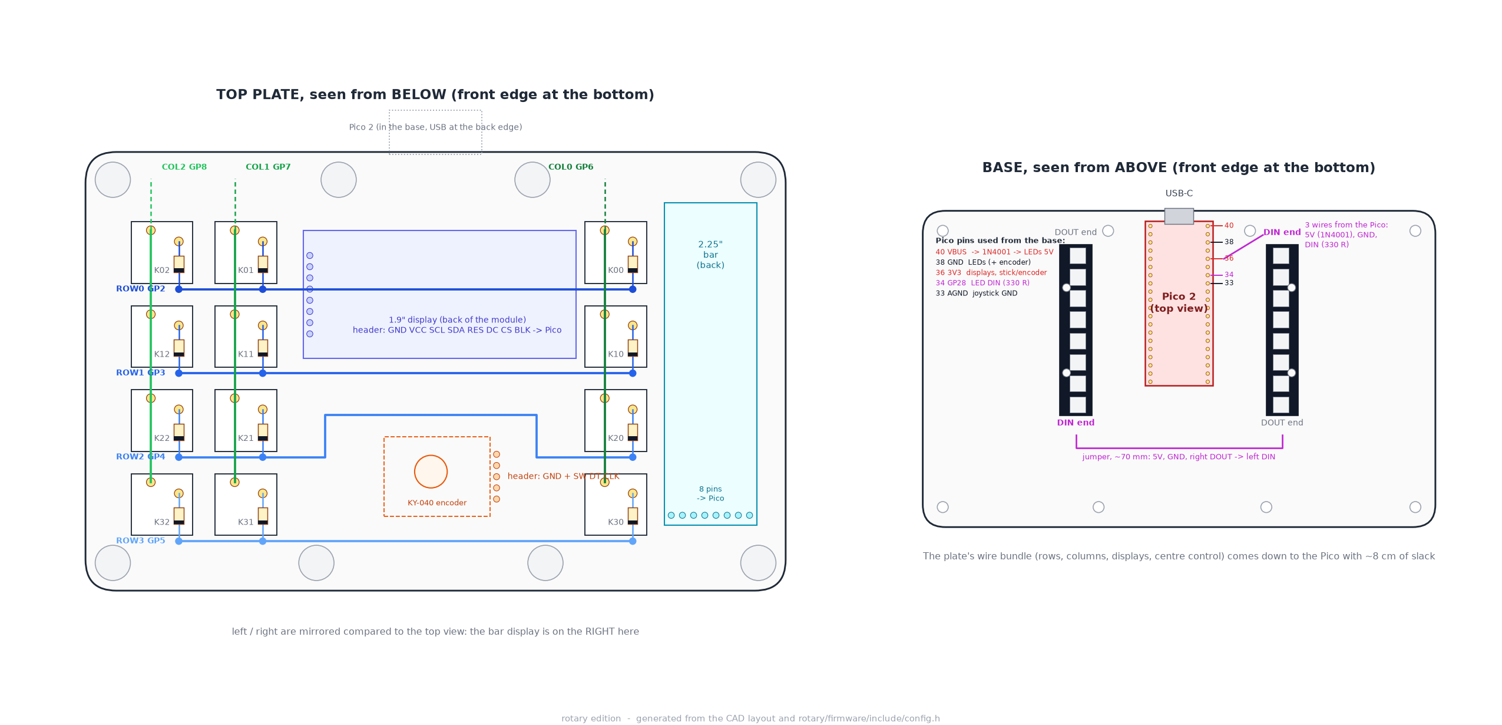
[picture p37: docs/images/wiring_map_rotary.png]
Wiring map, rotary edition


The [wiring page](wiring.md) has the pin-by-pin table and the Pico pinout diagram
for each edition.

## Before you plug it in

1. Continuity: **3V3 to GND**, **VBUS to GND**, **3V3 to VBUS**: all must read open.
   A short here means a bridged pin or a reversed LED stick.
2. Look along every module header for bridged pins.
3. Check the diode orientation once more (band towards the row).
4. Plug in. The screens should come up within a second and the LEDs light in violet.
   Then open the serial console (`make monitor`, 115200 baud) and type `info`; press
   every key and watch the 1.9" screen highlight it.

## Troubleshooting

| Symptom | Look at |
|---|---|
| One key does nothing | its diode joint, its window in the column wire |
| One key triggers another one too / phantom presses | a diode is backwards or missing, or a bare row touches a column |
| A whole row or column is dead | the tail wire at the Pico, wrong pin (rows GP2–5, columns GP6–8) |
| Key presses show up doubled | debounce is fine at 5 ms; look for a cracked joint that intermittently opens |
| A display stays white or black | its VCC/GND, then SCL/SDA (SPI0 for the 1.9", SPI1 for the bar), then RES |
| Display image is mirrored / upside down | not a soldering problem: `MAIN_ROTATION` / `BAR_ROTATION` in `config.h` |
| Colours look inverted | `MAIN_INVERT` / `BAR_INVERT` in `config.h` |
| LEDs stay dark | 5V and GND at the right stick's DIN end, the diode's direction, the data wire on GP28 |
| Only the first stick lights | the jumper from DOUT to the left stick's DIN |
| LEDs flicker or show wrong colours | a weak GND, or the data wire running next to the SPI wires: move it |
| The pointer / knob goes the wrong way | not a soldering problem: `JOY_INVERT_*`, or FN + REV |

If the Pico does not show up as a USB device at all, unplug it and check 3V3/VBUS
to GND again before anything else.

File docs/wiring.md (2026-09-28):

# Wiring

The pin map lives in each edition's `config.h`
([joystick](../joystick/firmware/include/config.h), [rotary](../rotary/firmware/include/config.h));
the diagrams below are generated from those files (`make diagrams`), so they always
match. Both editions use the same pins: the rotary encoder takes over the joystick's
three GPIOs, and the RGB LED sticks are fitted in both. How to solder all of it, and
where the wires run inside the case, is in the [soldering guide](soldering.md).

| Joystick edition | Rotary edition |
|---|---|
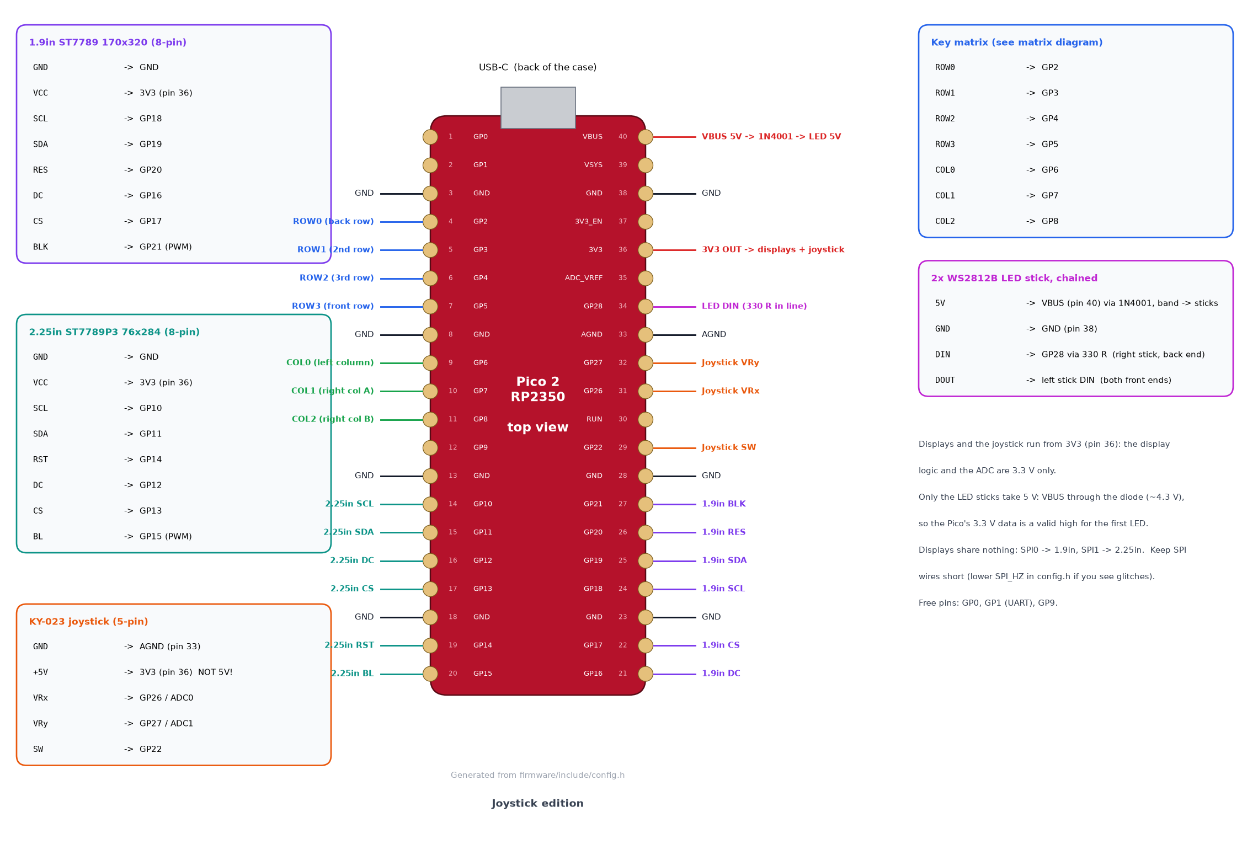
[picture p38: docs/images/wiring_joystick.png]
Pico 2 wiring, joystick edition
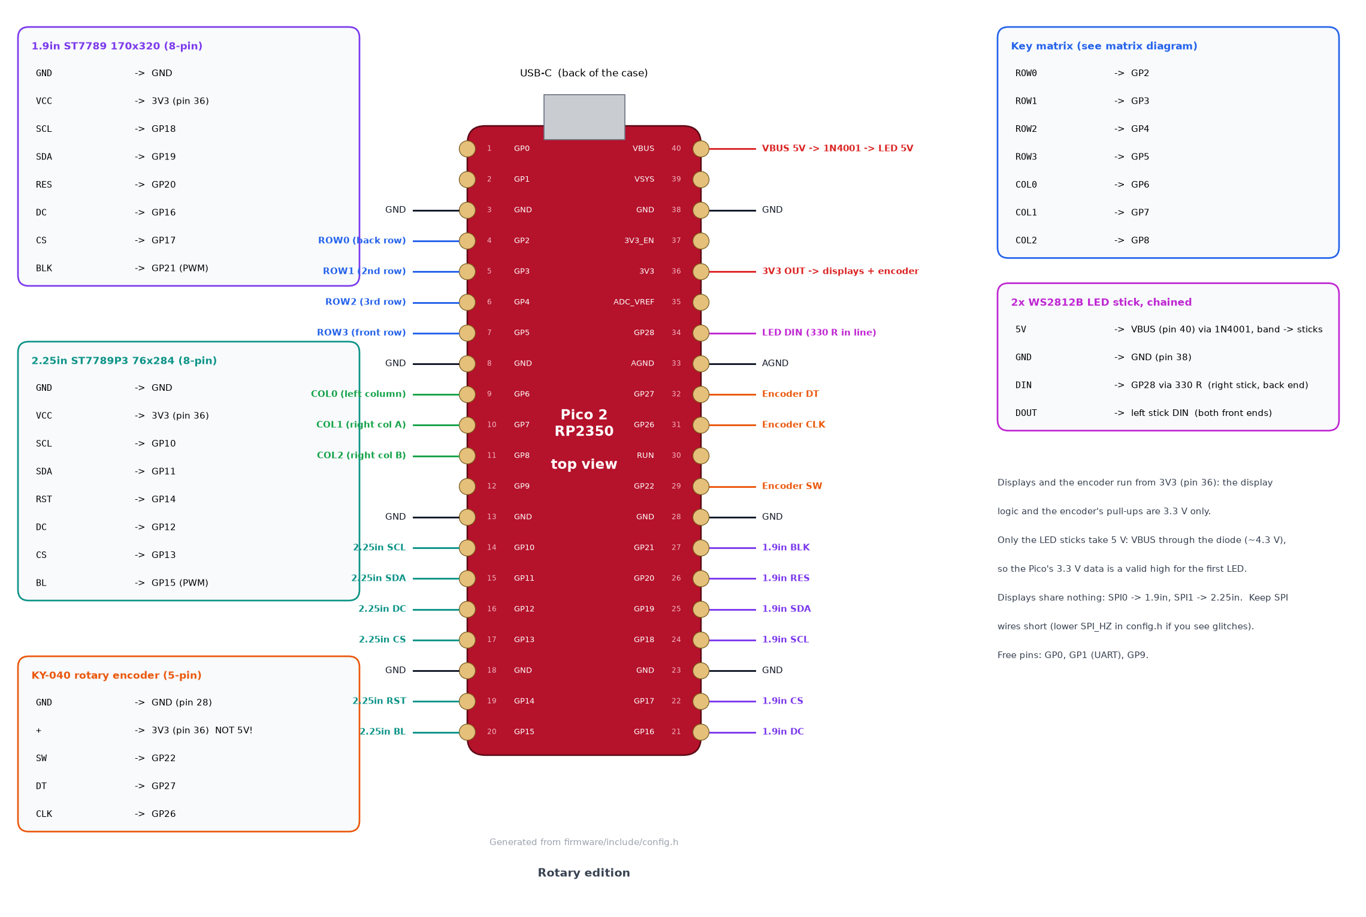
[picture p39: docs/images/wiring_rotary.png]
Pico 2 wiring, rotary edition
|  |  |

## Pin map

| Pico pin | GPIO | Connects to |
|---|---|---|
| 4, 5, 6, 7 | GP2, GP3, GP4, GP5 | matrix ROW0 (back) … ROW3 (front) |
| 9, 10, 11 | GP6, GP7, GP8 | matrix COL0 (left column), COL1, COL2 (right block) |
| 14 | GP10 | 2.25" SCL (SPI1 SCK) |
| 15 | GP11 | 2.25" SDA (SPI1 TX) |
| 16 | GP12 | 2.25" DC |
| 17 | GP13 | 2.25" CS |
| 19 | GP14 | 2.25" RST |
| 20 | GP15 | 2.25" BL (PWM backlight) |
| 21 | GP16 | 1.9" DC |
| 22 | GP17 | 1.9" CS |
| 24 | GP18 | 1.9" SCL (SPI0 SCK) |
| 25 | GP19 | 1.9" SDA (SPI0 TX) |
| 26 | GP20 | 1.9" RES |
| 27 | GP21 | 1.9" BLK (PWM backlight) |
| 28 | GND | encoder GND |
| 29 | GP22 | joystick SW · encoder SW |
| 31 | GP26 / ADC0 | joystick VRx · encoder CLK |
| 32 | GP27 / ADC1 | joystick VRy · encoder DT |
| 33 | AGND | joystick GND |
| 34 | GP28 | LED sticks DIN (through 330 Ω) |
| 36 | 3V3 | VCC of both displays, joystick "+5V" / encoder "+" |
| 38 | GND | LED sticks GND |
| 40 | VBUS | LED sticks 5V (through a 1N4001) |
| 3, 8, 13, 18, 23 | GND | display GNDs |

Free for later: GP0/GP1 (UART), GP9.

**Power notes**
- The displays and the joystick or encoder run from the Pico's **3V3** regulator
  (≈300 mA available; the two backlights and the logic draw well under 100 mA). Do
  **not** feed them from VBUS/VSYS: the 1.9" module passes VCC straight to the panel,
  the joystick's outputs must stay below 3.3 V for the ADC, and the KY-040's pull-up
  resistors go to its "+" pin, so 5 V there would reach the GPIOs.
- Only the LED sticks take 5 V, from VBUS through a diode (see below).
- Use AGND for the joystick ground; it keeps the analog readings quieter.

## Key matrix

Matrix schematic

- **COL2ROW**: each switch goes between its column wire and a diode; the diode's cathode
  (black band) goes to the row wire. The firmware drives one row low at a time and reads
  the columns with pull-ups.
- Row wires run across the whole pad: left column → under the centre (between the
  display/centre-control area and the plate) → the two right columns. Column wires run
  front to back.
- Physical order: ROW0 = back row (next to the USB port), COL0 = the single column
  next to the bar display. The keymaps (`<edition>/firmware/src/keymap.cpp`) use the
  same numbering.
- Step by step, with pictures: [soldering guide, steps 1–4](soldering.md#step-1--diodes-on-the-switches).

## Display modules

| Module pin | 1.9" (SPI0) | 2.25" (SPI1) |
|---|---|---|
| GND | GND | GND |
| VCC | 3V3 | 3V3 |
| SCL | GP18 | GP10 |
| SDA | GP19 | GP11 |
| RES / RST | GP20 | GP14 |
| DC | GP16 | GP12 |
| CS | GP17 | GP13 |
| BLK / BL | GP21 | GP15 |

Each display has its own SPI peripheral, so a wiring problem on one never affects the
other. Keep the SPI wires reasonably short (the Pico sits right under the 1.9" display).
`SPI_HZ` in `config.h` defaults to 40 MHz, which is safe for hand-wired leads; try
62.5 MHz for a faster refresh, or 20 MHz if you ever see garbled pixels.

## Joystick (KY-023), joystick edition

| Module pin | Pico |
|---|---|
| GND | AGND (pin 33) |
| +5V | **3V3** (pin 36) |
| VRx | GP26 (ADC0) |
| VRy | GP27 (ADC1) |
| SW | GP22 (internal pull-up) |

If the pointer moves the wrong way, flip `JOY_INVERT_X` / `JOY_INVERT_Y` (or
`JOY_SWAP_XY`) in `config.h`. The centre is re-sampled at every power-up (keep the stick
still while plugging in) and can be re-calibrated with the `CAL` key on the FN layer.

## Where the wires run

The physical map, drawn from the CAD model: the plate seen from below (as on your
bench) and the base from above.

| Joystick edition | Rotary edition |
|---|---|
| Wiring map, joystick edition | Wiring map, rotary edition |

## Rotary encoder (KY-040), rotary edition

| Module pin | Pico |
|---|---|
| GND | GND (pin 28, next to SW) |
| + | **3V3** (pin 36) |
| SW | GP22 (internal pull-up, most modules have no resistor fitted for SW) |
| DT | GP27 |
| CLK | GP26 |

The encoder is read by pin-change interrupts and a decoder that only counts complete
detents, so contact bounce never produces extra steps. If clockwise turns the wrong way,
press **FN + REV** (saved) or set `ENC_REVERSE` in `config.h`. For a half-step encoder
(two steps per click), set `ENC_STEPS_PER_DETENT = 2`.

## RGB LED sticks (both editions)

Two 8-LED WS2812B sticks (CJMCU-2812-8 style) are screwed to posts on the base, one
each side of the Pico, LEDs facing up. They are chained, so they need one data pin:

```
Pico GP28 ──330 Ω──► DIN  right stick (back end, next to the Pico's USB end)
                     DOUT right stick (front end) ──► DIN left stick (front end)
Pico VBUS ──►|── 1N4001 (band towards the sticks) ──► 5V of both sticks
Pico GND  ─────────────────────────────────────────► GND of both sticks
```

- **Why the diode:** a WS2812B on 5 V wants at least 3.5 V for a "high" on DIN, and the
  Pico only drives 3.3 V. The diode drops the LED supply to about 4.3 V, where 3.3 V is a
  clean high. The LEDs work fine at that voltage. A 74AHCT125 level shifter would also
  work, but the diode needs no board.
- **The 330 Ω resistor** sits in the data wire close to the first stick's DIN. It damps
  ringing on the wire and protects the first LED. Heat-shrink it inline.
- **Current:** the firmware caps the sticks at 250 mA (`LED_BUDGET_MA`) and at 160/255
  brightness (`LED_MAX_BRIGHTNESS`), so the whole pad stays well inside a USB 2.0 port's
  500 mA. The LEDs follow the display brightness, dim with it when idle, and go dark
  while the computer sleeps.
- The sticks have their pads on the back at both ends. The posts hold them 3 mm above
  the floor, so there is room for the solder joints and the wires under the ends.
- No sticks fitted? Set `LED_COUNT = 0` in `config.h`, or just leave GP28 unconnected.

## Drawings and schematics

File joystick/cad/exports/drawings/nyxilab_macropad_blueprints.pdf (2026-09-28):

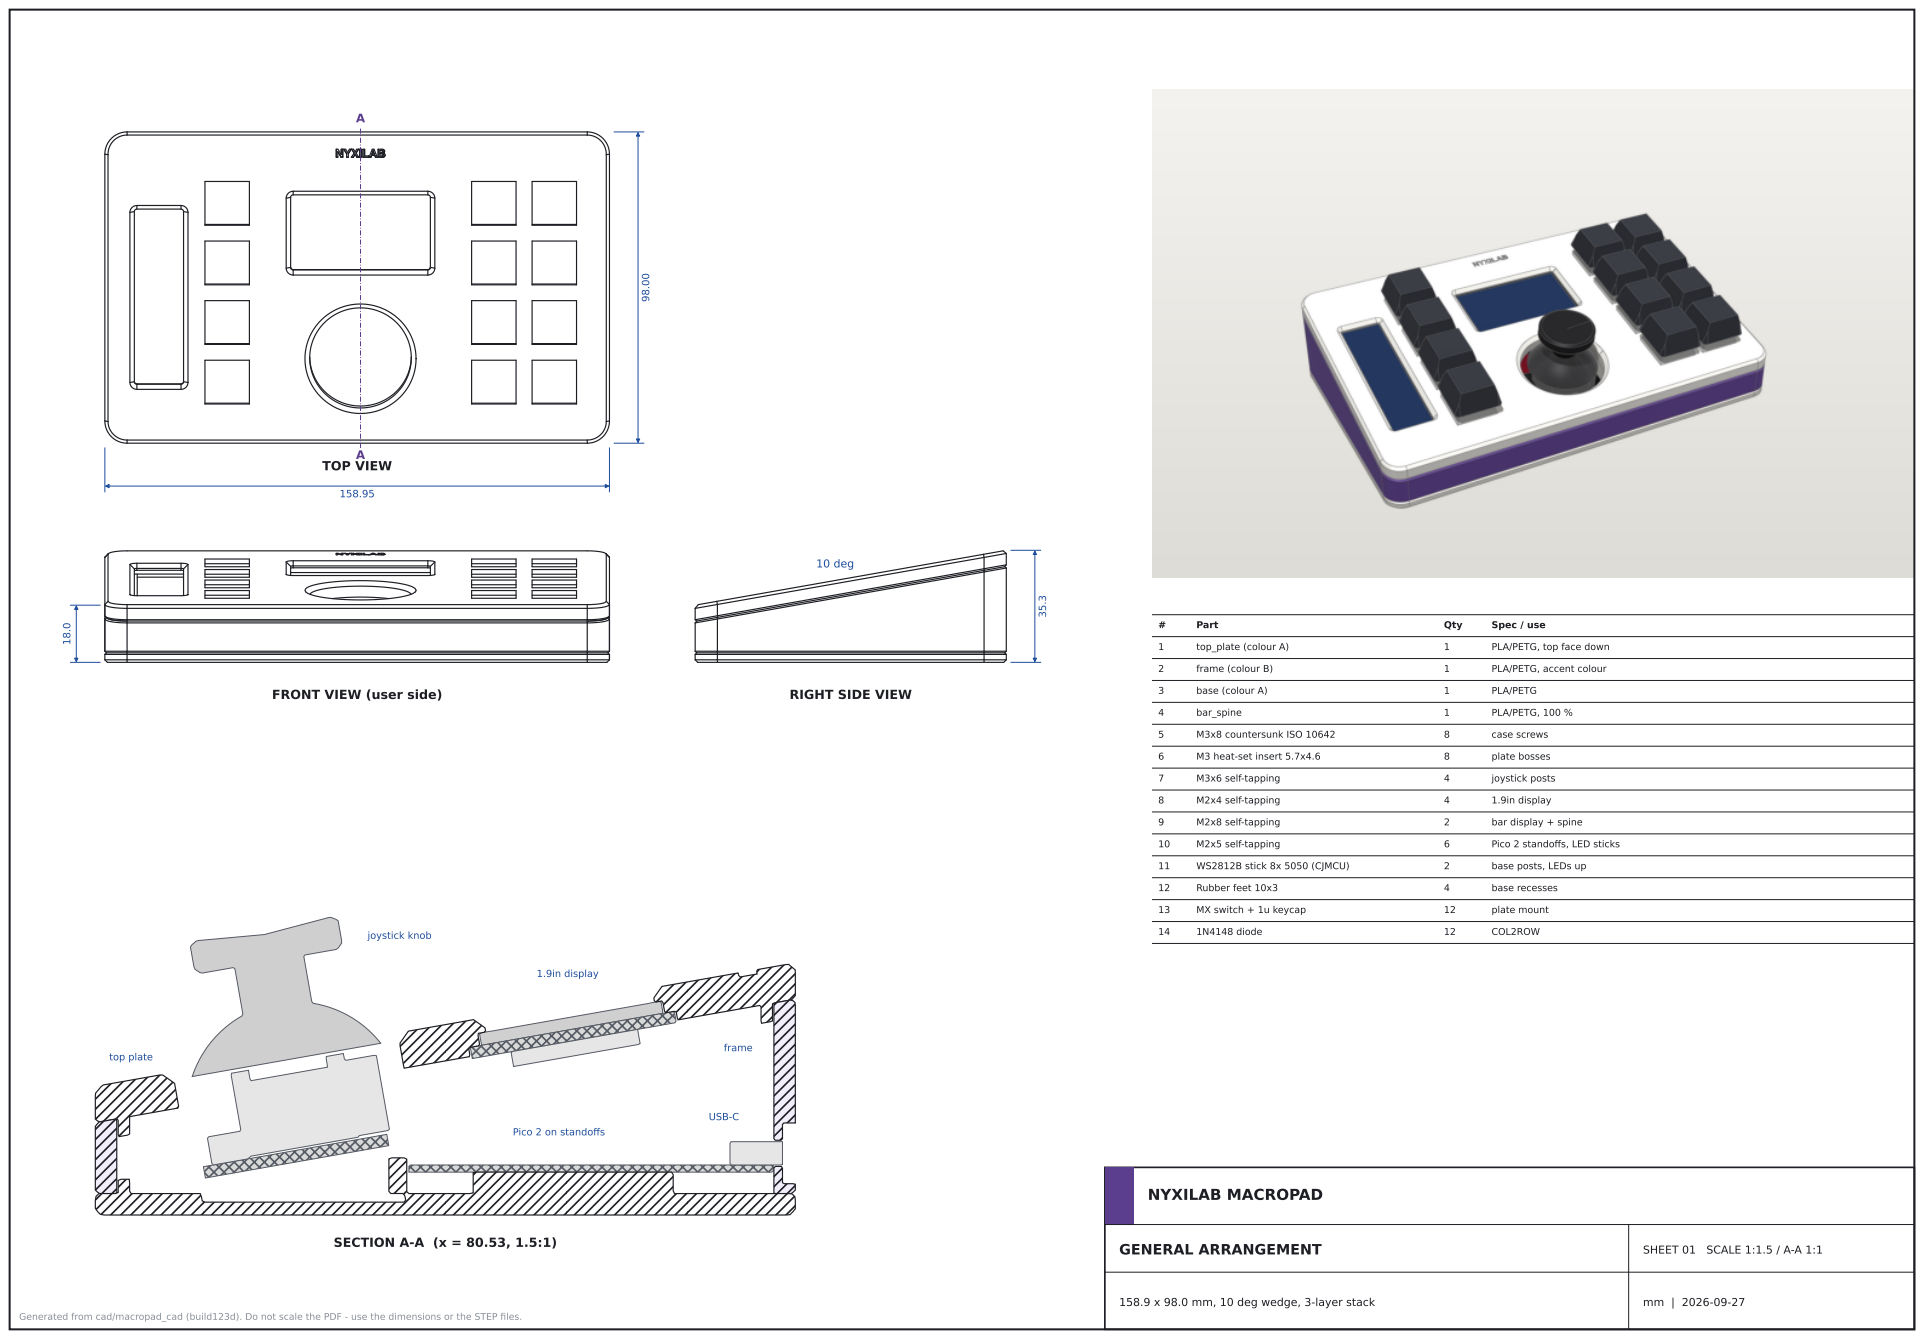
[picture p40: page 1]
NYXILAB MACROPAD; GENERAL ARRANGEMENT; SHEET 01 SCALE 1:1.5 / A-A 1:1; TOP VIEW; FRONT VIEW (user side); RIGHT SIDE VIEW; 10 deg; SECTION A-A (x = 80.53, 1.5:1); joystick knob; 1.9in display; USB-C; top plate; frame; Part; Qty; Spec / use; top_plate (colour A); PLA/PETG, top face down; frame (colour B); PLA/PETG, accent colour; base (colour A); PLA/PETG; bar_spine; PLA/PETG, 100 %; M3x8 countersunk ISO 10642; case screws; M3 heat-set insert 5.7x4.6; plate bosses; M3x6 self-tapping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

Pico 2 on standoffs

158.9 x 98.0 mm, 10 deg wedge, 3-layer stack

Generated from cad/macropad_cad (build123d). Do not scale the PDF - use the dimensions or the STEP files.

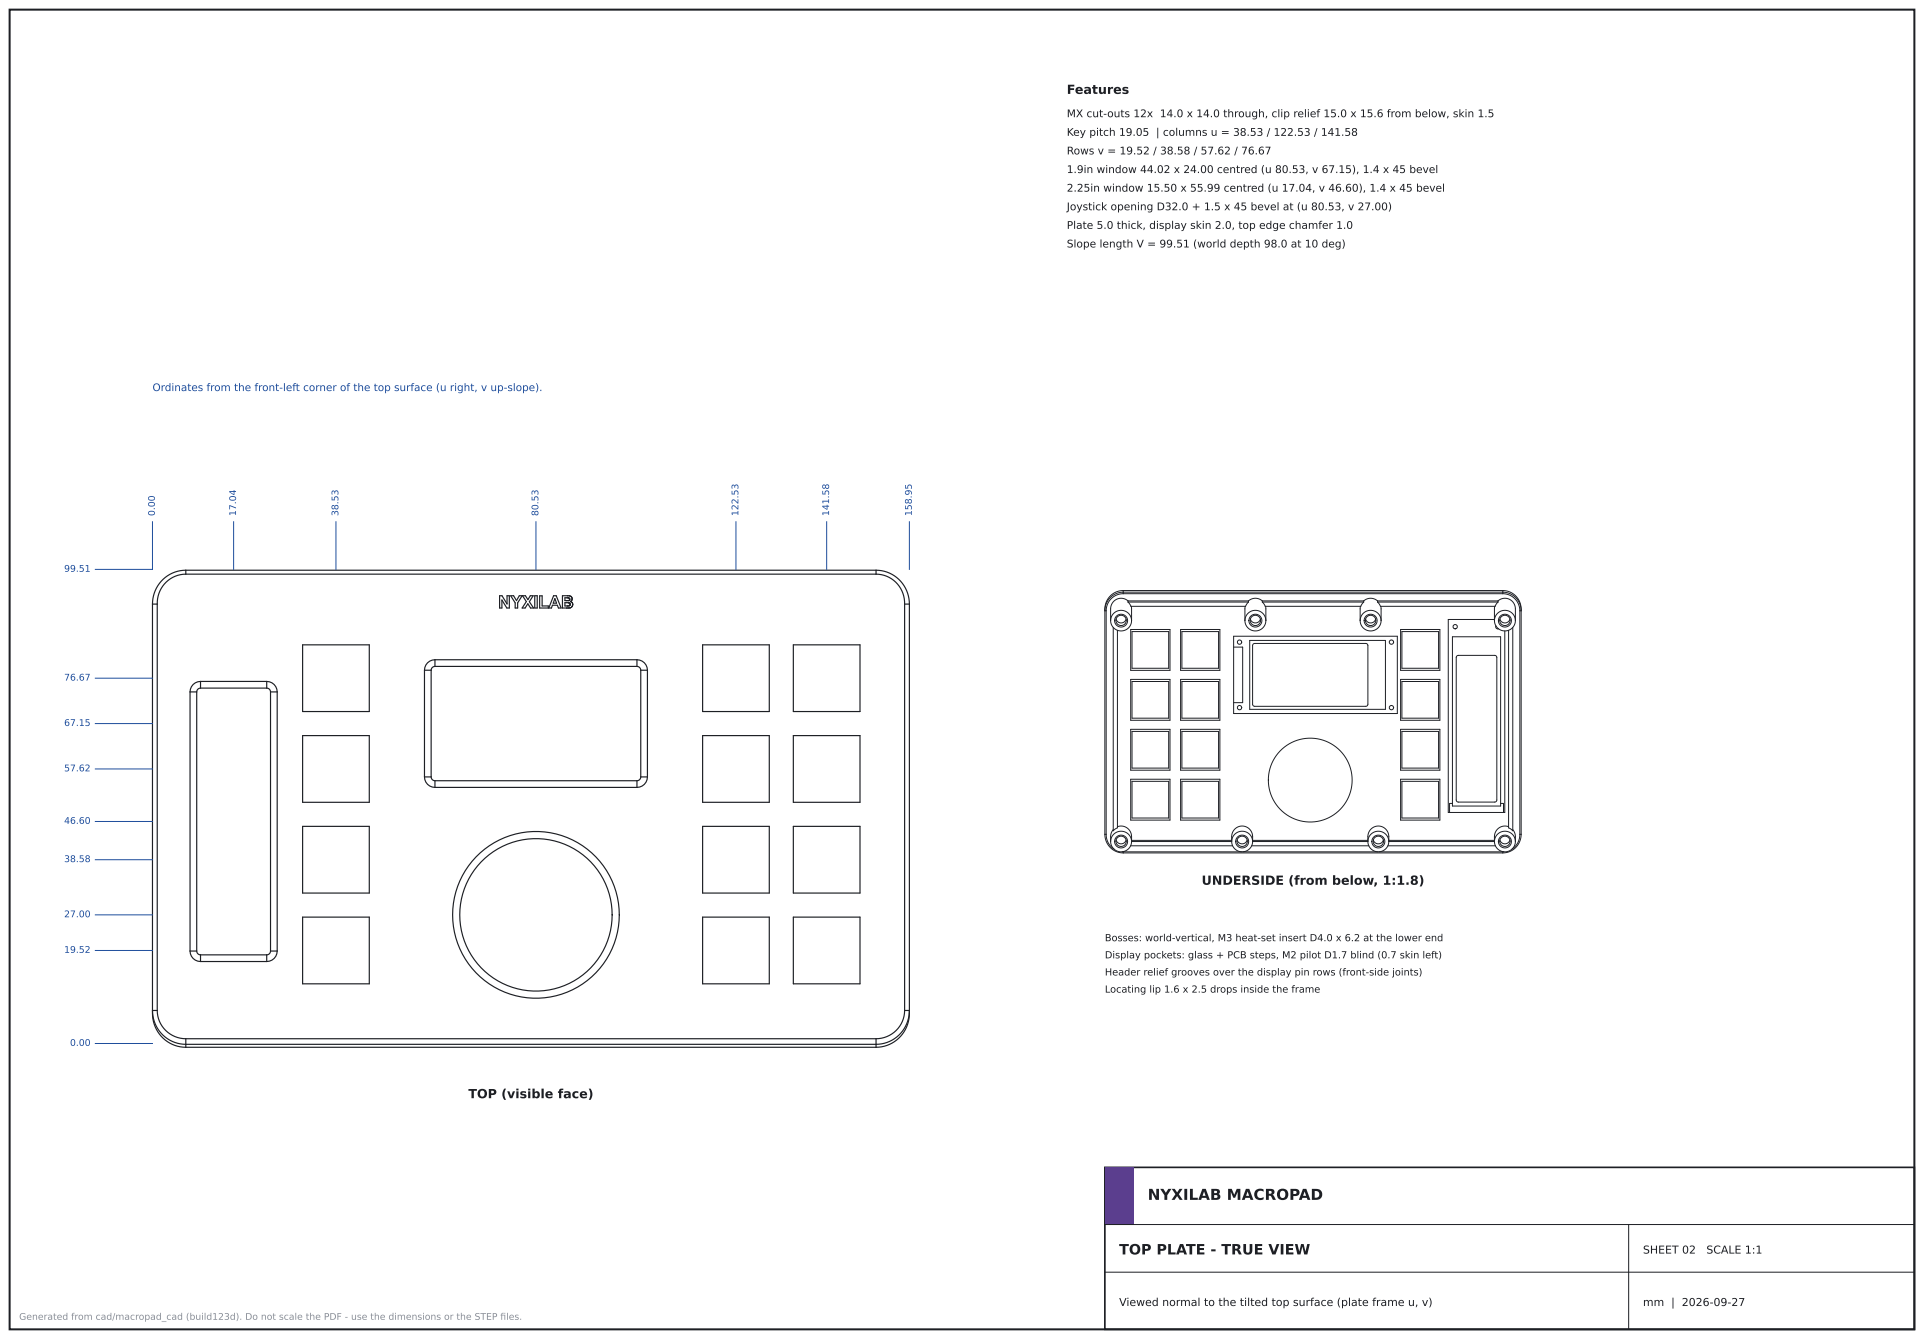
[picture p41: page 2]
NYXILAB MACROPAD; SHEET 02 SCALE 1:1; Features

MX cut-outs 12x 14.0 x 14.0 through, clip relief 15.0 x 15.6 from below, skin 1.5
Key pitch 19.05 | columns u = 38.53 / 122.53 / 141.58
Rows v = 19.52 / 38.58 / 57.62 / 76.67
1.9in window 44.02 x 24.00 centred (u 80.53, v 67.15), 1.4 x 45 bevel
2.25in window 15.50 x 55.99 centred (u 17.04, v 46.60), 1.4 x 45 bevel
Joystick opening D32.0 + 1.5 x 45 bevel at (u 80.53, v 27.00)
Plate 5.0 thick, display skin 2.0, top edge chamfer 1.0
Slope length V = 99.51 (world depth 98.0 at 10 deg)

Ordinates from the front-left corner of the top surface (u right, v up-slope).

UNDERSIDE (from below, 1:1.8)

Bosses: world-vertical, M3 heat-set insert D4.0 x 6.2 at the lower end
Display pockets: glass + PCB steps, M2 pilot D1.7 blind (0.7 skin left)
Header relief grooves over the display pin rows (front-side joints)
Locating lip 1.6 x 2.5 drops inside the frame

TOP (visible face)

TOP PLATE - TRUE VIEW

Viewed normal to the tilted top surface (plate frame u, v)

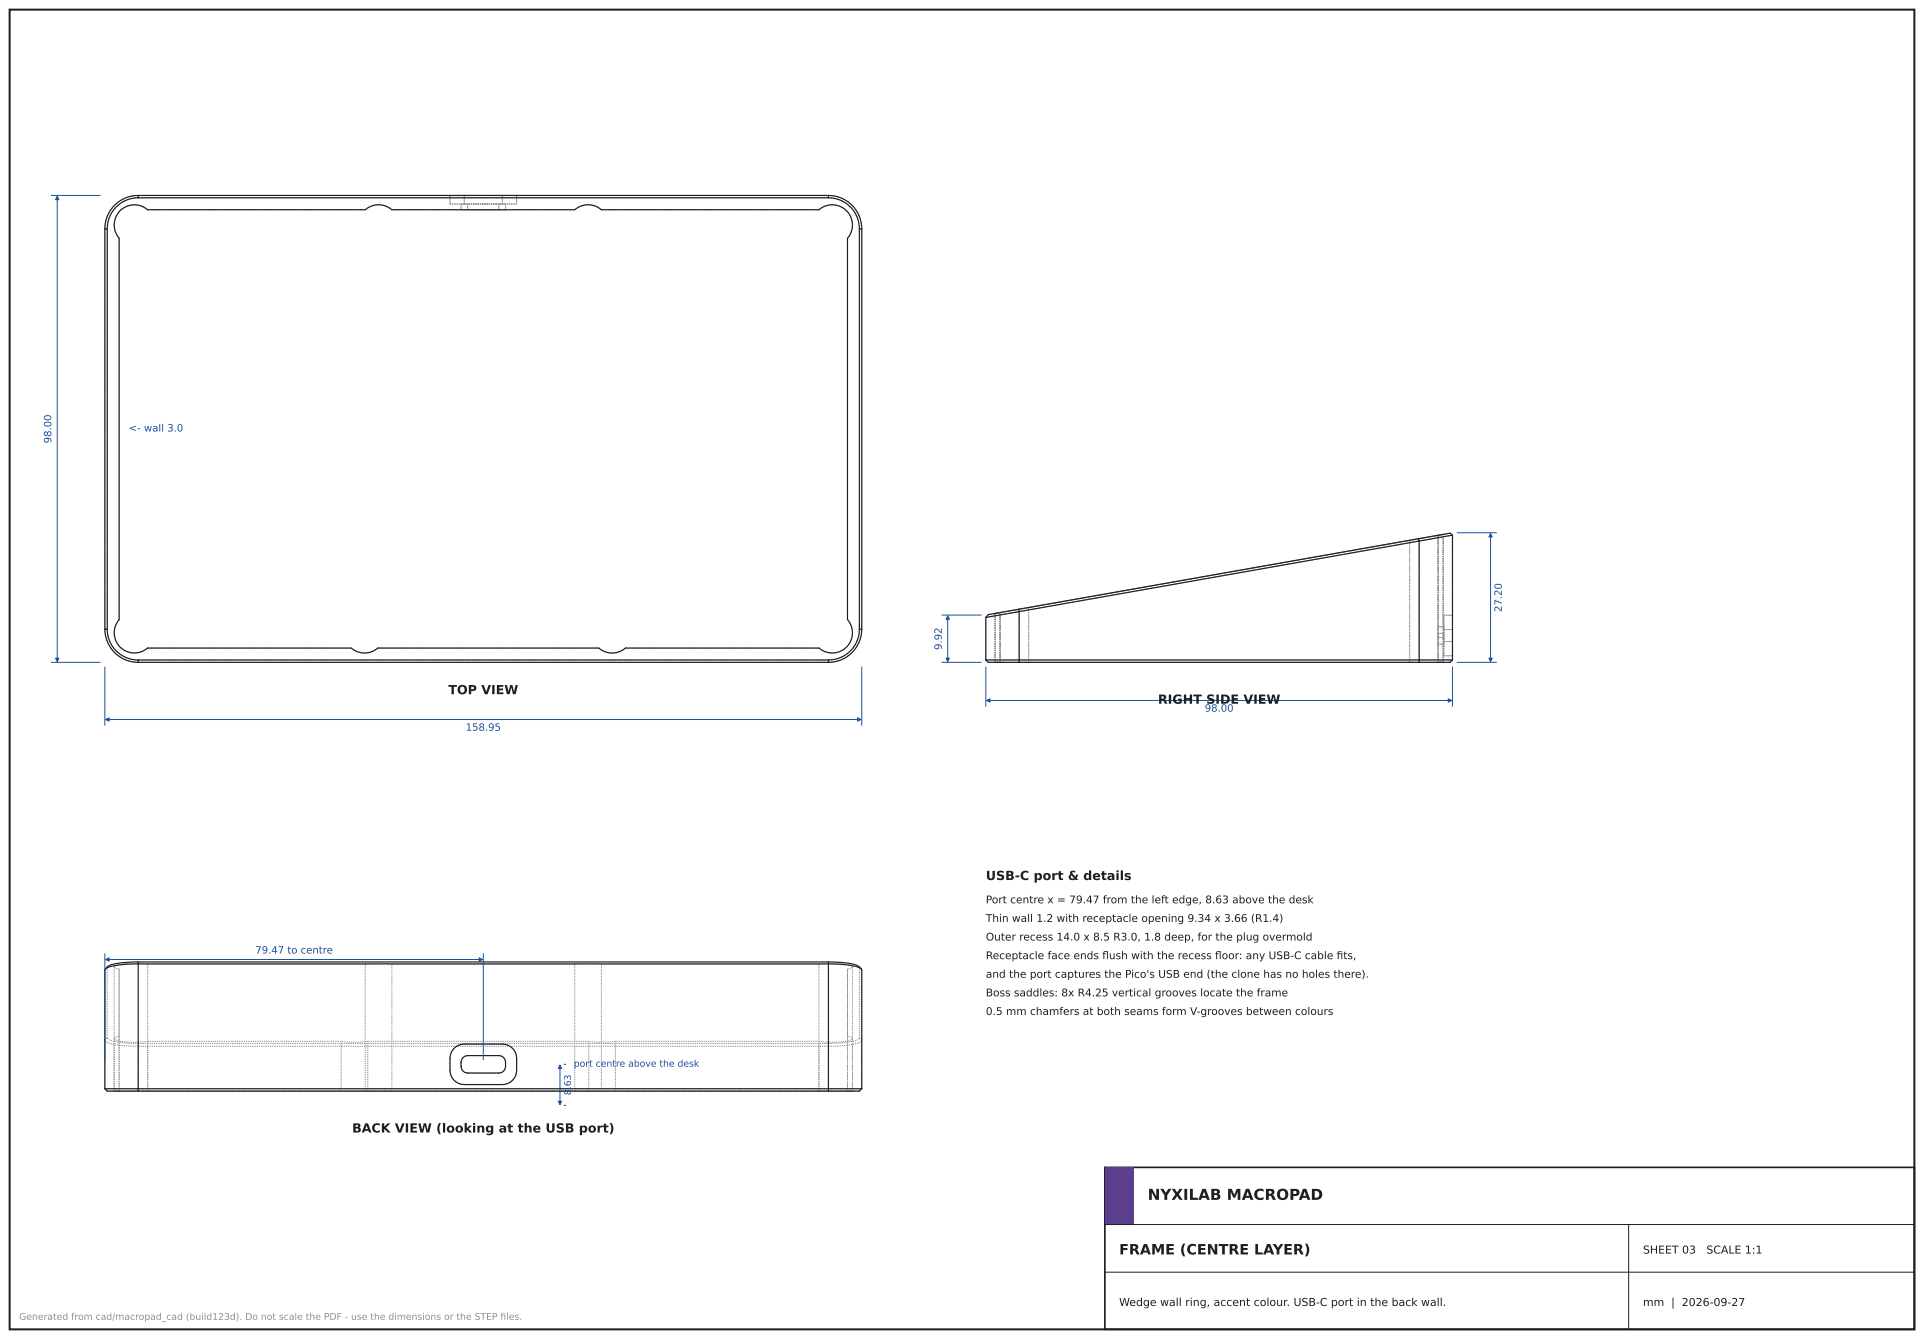
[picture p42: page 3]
NYXILAB MACROPAD; SHEET 03 SCALE 1:1; TOP VIEW; RIGHT SIDE VIEW; <- wall 3.0; 79.47 to centre

USB-C port & details

Port centre x = 79.47 from the left edge, 8.63 above the desk
Thin wall 1.2 with receptacle opening 9.34 x 3.66 (R1.4)
Outer recess 14.0 x 8.5 R3.0, 1.8 deep, for the plug overmold
Receptacle face ends flush with the recess floor: any USB-C cable fits,

and the port captures the Pico's USB end (the clone has no holes there).
Boss saddles: 8x R4.25 vertical grooves locate the frame
0.5 mm chamfers at both seams form V-grooves between colours

port centre above the desk

BACK VIEW (looking at the USB port)

FRAME (CENTRE LAYER)

Wedge wall ring, accent colour. USB-C port in the back wall.

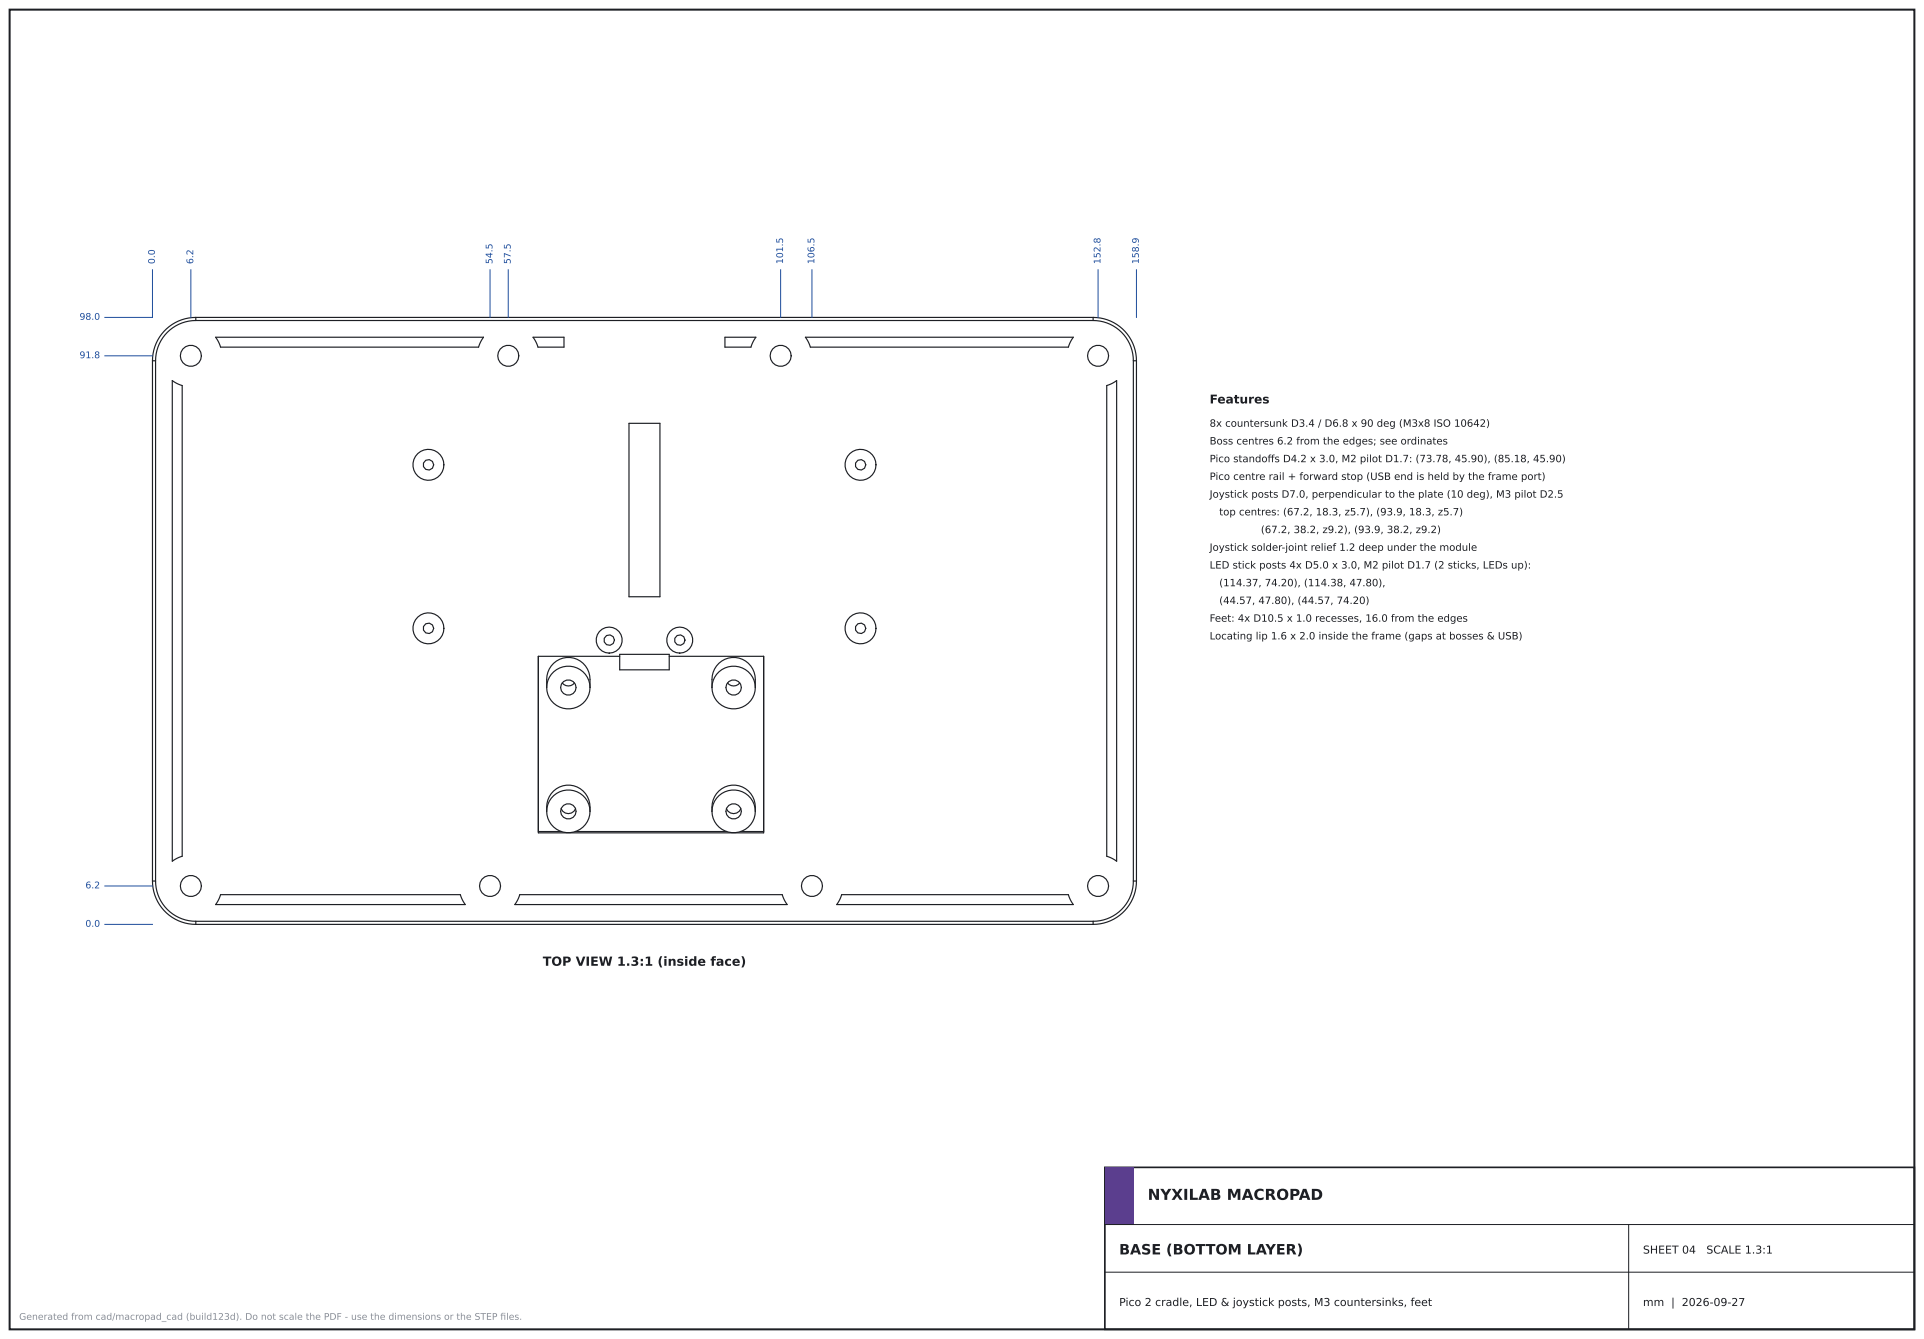
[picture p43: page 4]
NYXILAB MACROPAD; SHEET 04 SCALE 1.3:1; Features; top centres: (67.2, 18.3, z5.7), (93.9, 18.3, z5.7)

8x countersunk D3.4 / D6.8 x 90 deg (M3x8 ISO 10642)

Boss centres 6.2 from the edges; see ordinates
Pico standoffs D4.2 x 3.0, M2 pilot D1.7: (73.78, 45.90), (85.18, 45.90)

Pico centre rail + forward stop (USB end is held by the frame port)

Joystick posts D7.0, perpendicular to the plate (10 deg), M3 pilot D2.5

Joystick solder-joint relief 1.2 deep under the module

LED stick posts 4x D5.0 x 3.0, M2 pilot D1.7 (2 sticks, LEDs up):

Feet: 4x D10.5 x 1.0 recesses, 16.0 from the edges

Locating lip 1.6 x 2.0 inside the frame (gaps at bosses & USB)

TOP VIEW 1.3:1 (inside face)

BASE (BOTTOM LAYER)

Pico 2 cradle, LED & joystick posts, M3 countersinks, feet

## NYXILAB MACROPAD

## BAR DISPLAY SPINE & FIT TESTS

Clamp for the 2.25in module; coupons to print first

SHEET 05 SCALE 2:1

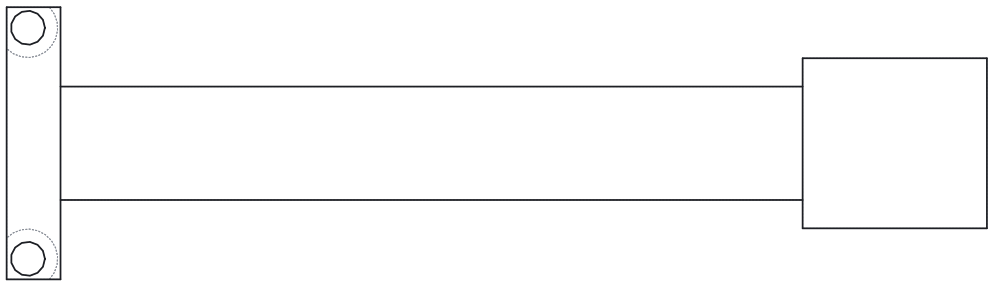
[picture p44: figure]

SPINE - TOP 2:1

SPINE - SIDE 2:1 (bed face down)

Bar display spine

Held by the bar module's own two M2 holes (M2x8 through spine + PCB into the plate).

Arches 3.0 mm over the FPC / ZIF / parts on the module back,

pad presses the PCB 3-16 mm from the header end (0.2 mm preload).
Print flat side down, 100 % infill.

Fit-test coupons (print these first, ~1 h total)

fit_switch 3 MX holes 13.9 / 14.0 / 14.1 - pick the one your switches click into

fit_plate_d19 1.9in window, pockets and M2 pilots

fit_plate_bar 2.25in window, pockets and pilots

fit_plate_joy joystick opening and bevel

fit_usb | back wall + Pico cradle: plug a cable in, check alignment
fit_joystick | base patch with the 4 posts: check the KY-023 hole grid
fit_led | base strip with the posts of one LED stick: check the hole pitch

If a fit is off, change the value in cad/macropad_cad/params.py

and rebuild (make cad). Values marked MEASURE are the likely suspects.

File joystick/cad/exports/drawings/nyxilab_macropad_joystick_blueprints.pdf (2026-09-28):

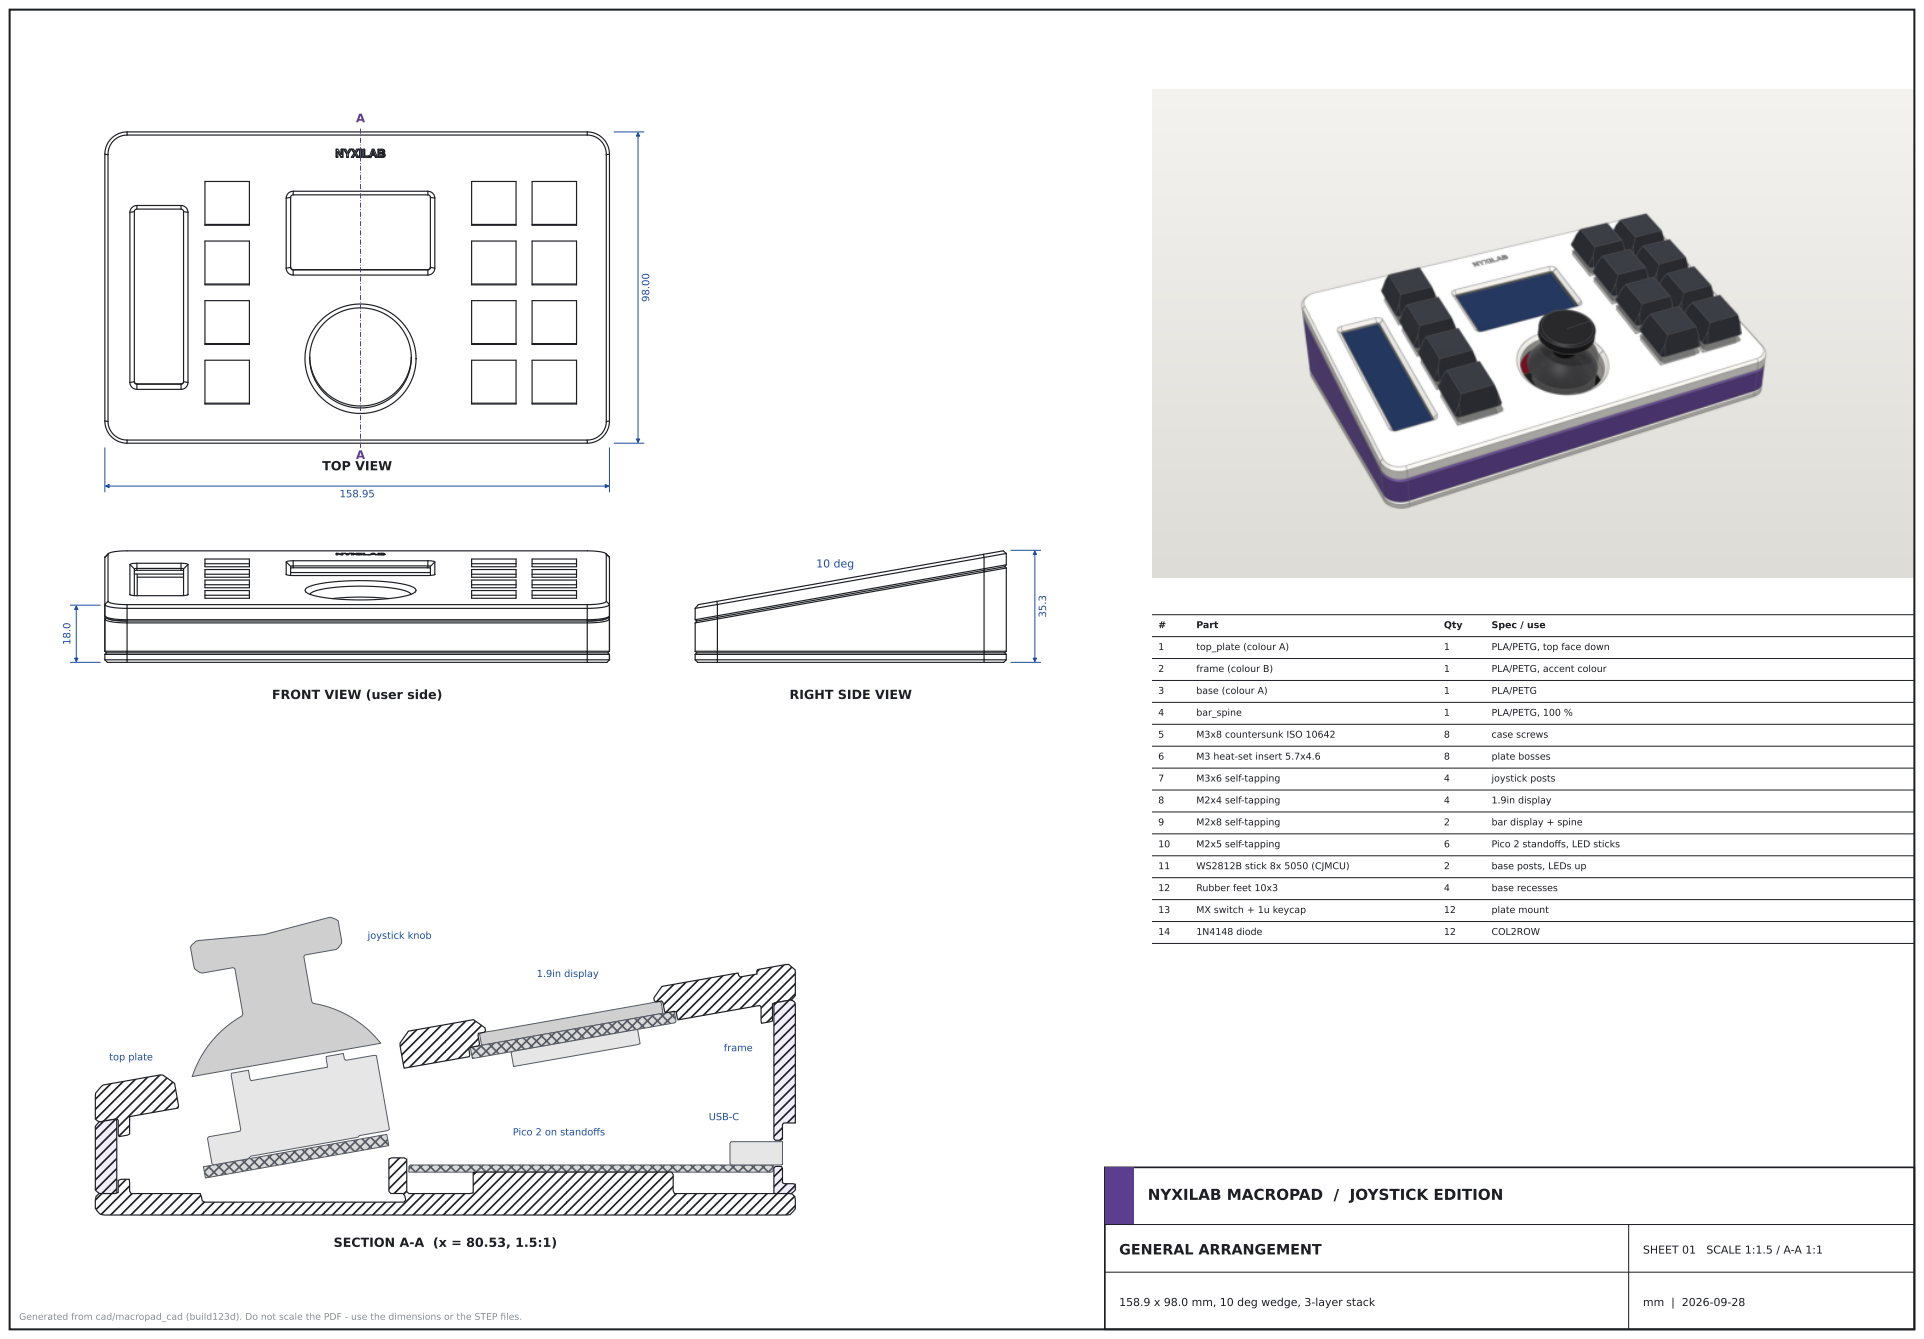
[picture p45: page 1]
GENERAL ARRANGEMENT; SHEET 01 SCALE 1:1.5 / A-A 1:1; TOP VIEW; FRONT VIEW (user side); RIGHT SIDE VIEW; 10 deg; SECTION A-A (x = 80.53, 1.5:1); joystick knob; 1.9in display; USB-C; top plate; frame; Part; Qty; Spec / use; top_plate (colour A); PLA/PETG, top face down; frame (colour B); PLA/PETG, accent colour; base (colour A); PLA/PETG; bar_spine; PLA/PETG, 100 %; M3x8 countersunk ISO 10642; case screws; M3 heat-set insert 5.7x4.6; plate bosses; M3x6 self-tapping; joystick posts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

Pico 2 on standoffs

NYXILAB MACROPAD / JOYSTICK EDITION

158.9 x 98.0 mm, 10 deg wedge, 3-layer stack

Generated from cad/macropad_cad (build123d). Do not scale the PDF - use the dimensions or the STEP files.

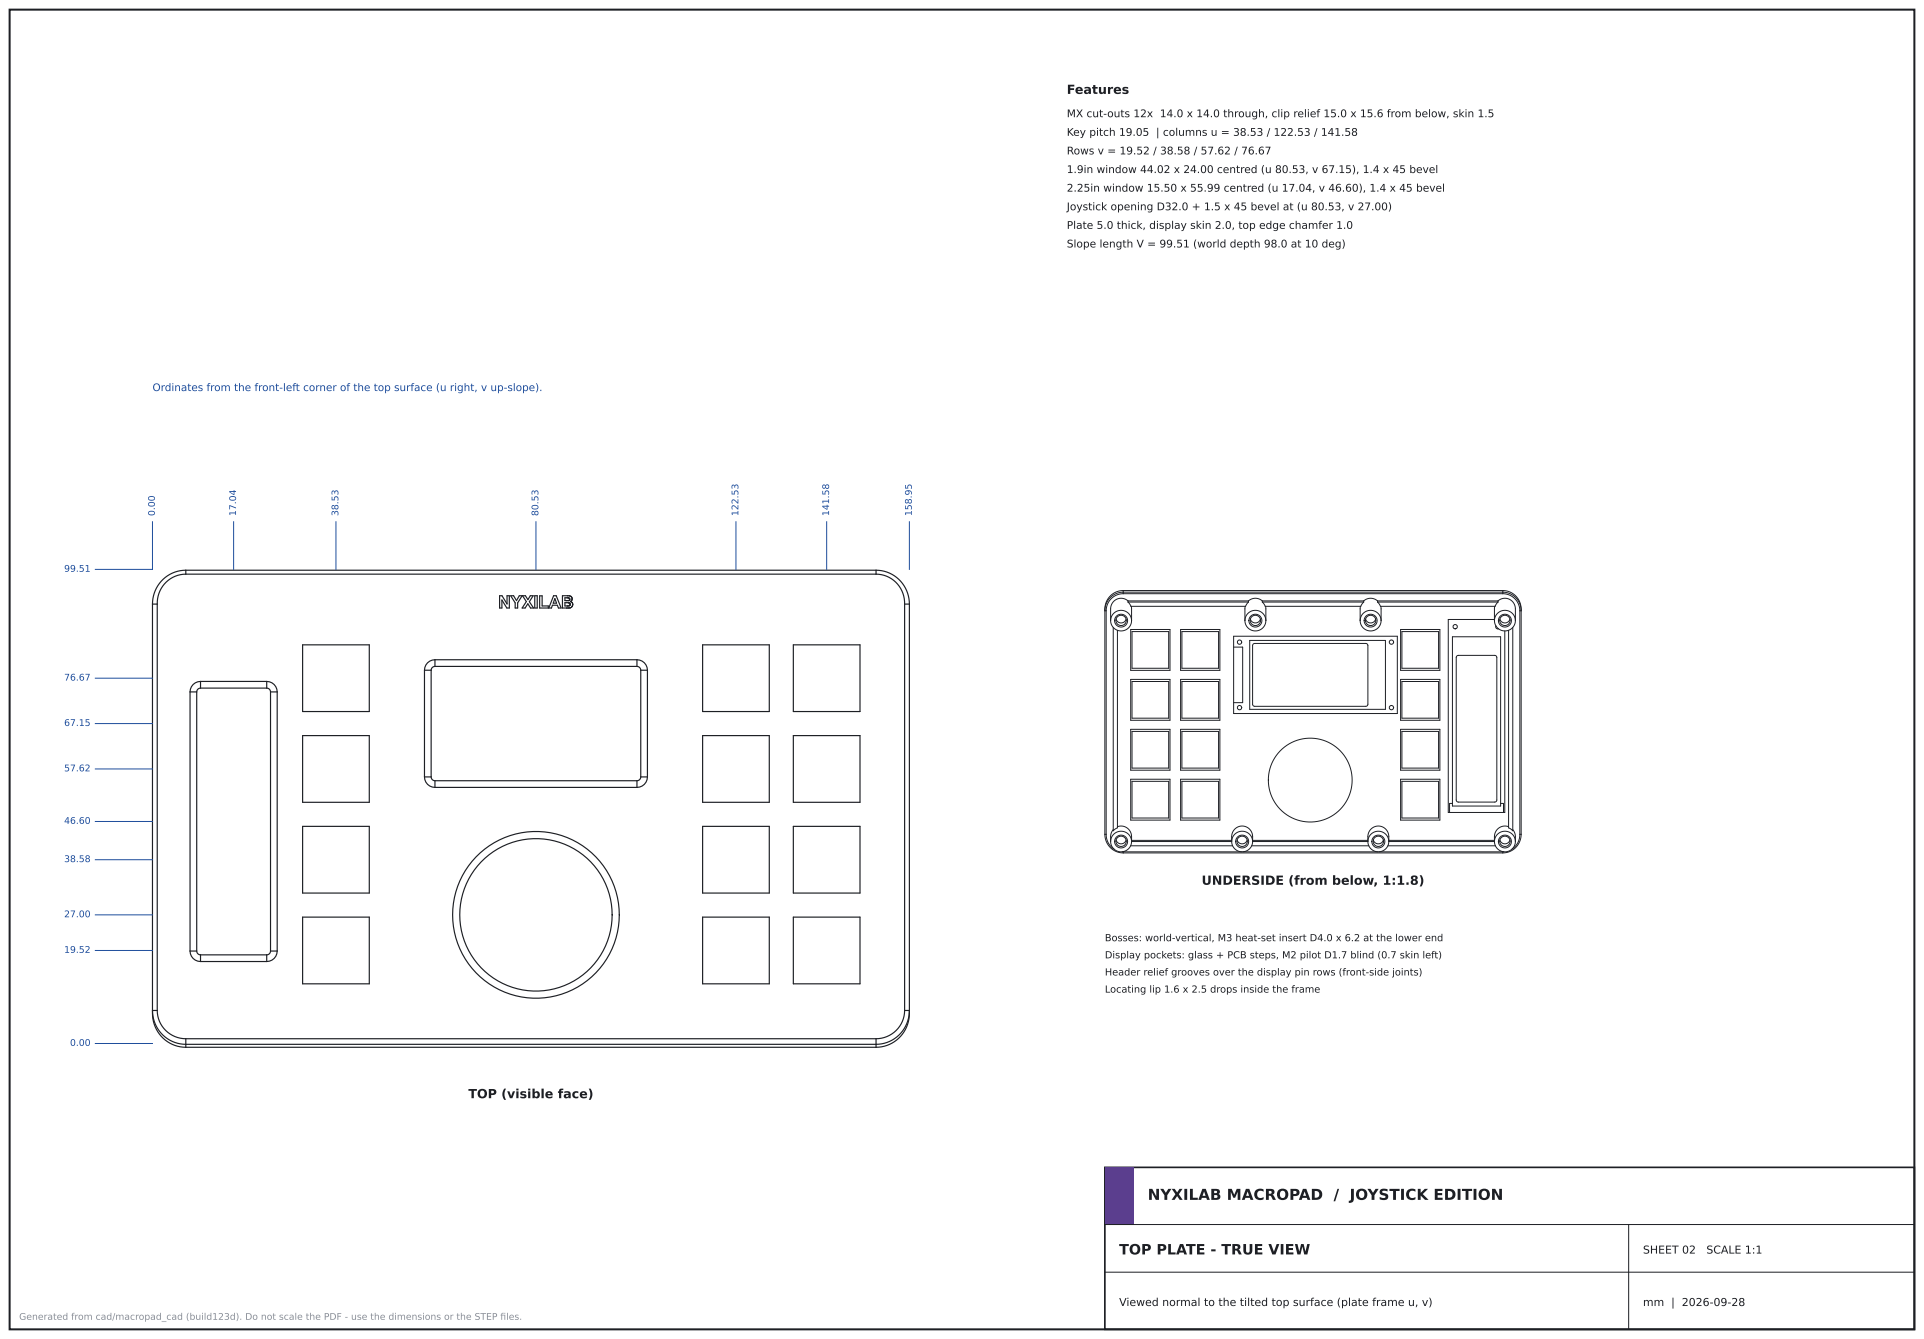
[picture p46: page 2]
SHEET 02 SCALE 1:1; Features

MX cut-outs 12x 14.0 x 14.0 through, clip relief 15.0 x 15.6 from below, skin 1.5
Key pitch 19.05 | columns u = 38.53 / 122.53 / 141.58
Rows v = 19.52 / 38.58 / 57.62 / 76.67
1.9in window 44.02 x 24.00 centred (u 80.53, v 67.15), 1.4 x 45 bevel
2.25in window 15.50 x 55.99 centred (u 17.04, v 46.60), 1.4 x 45 bevel
Joystick opening D32.0 + 1.5 x 45 bevel at (u 80.53, v 27.00)
Plate 5.0 thick, display skin 2.0, top edge chamfer 1.0
Slope length V = 99.51 (world depth 98.0 at 10 deg)

Ordinates from the front-left corner of the top surface (u right, v up-slope).

UNDERSIDE (from below, 1:1.8)

Bosses: world-vertical, M3 heat-set insert D4.0 x 6.2 at the lower end
Display pockets: glass + PCB steps, M2 pilot D1.7 blind (0.7 skin left)
Header relief grooves over the display pin rows (front-side joints)
Locating lip 1.6 x 2.5 drops inside the frame

TOP (visible face)

NYXILAB MACROPAD / JOYSTICK EDITION

TOP PLATE - TRUE VIEW

Viewed normal to the tilted top surface (plate frame u, v)

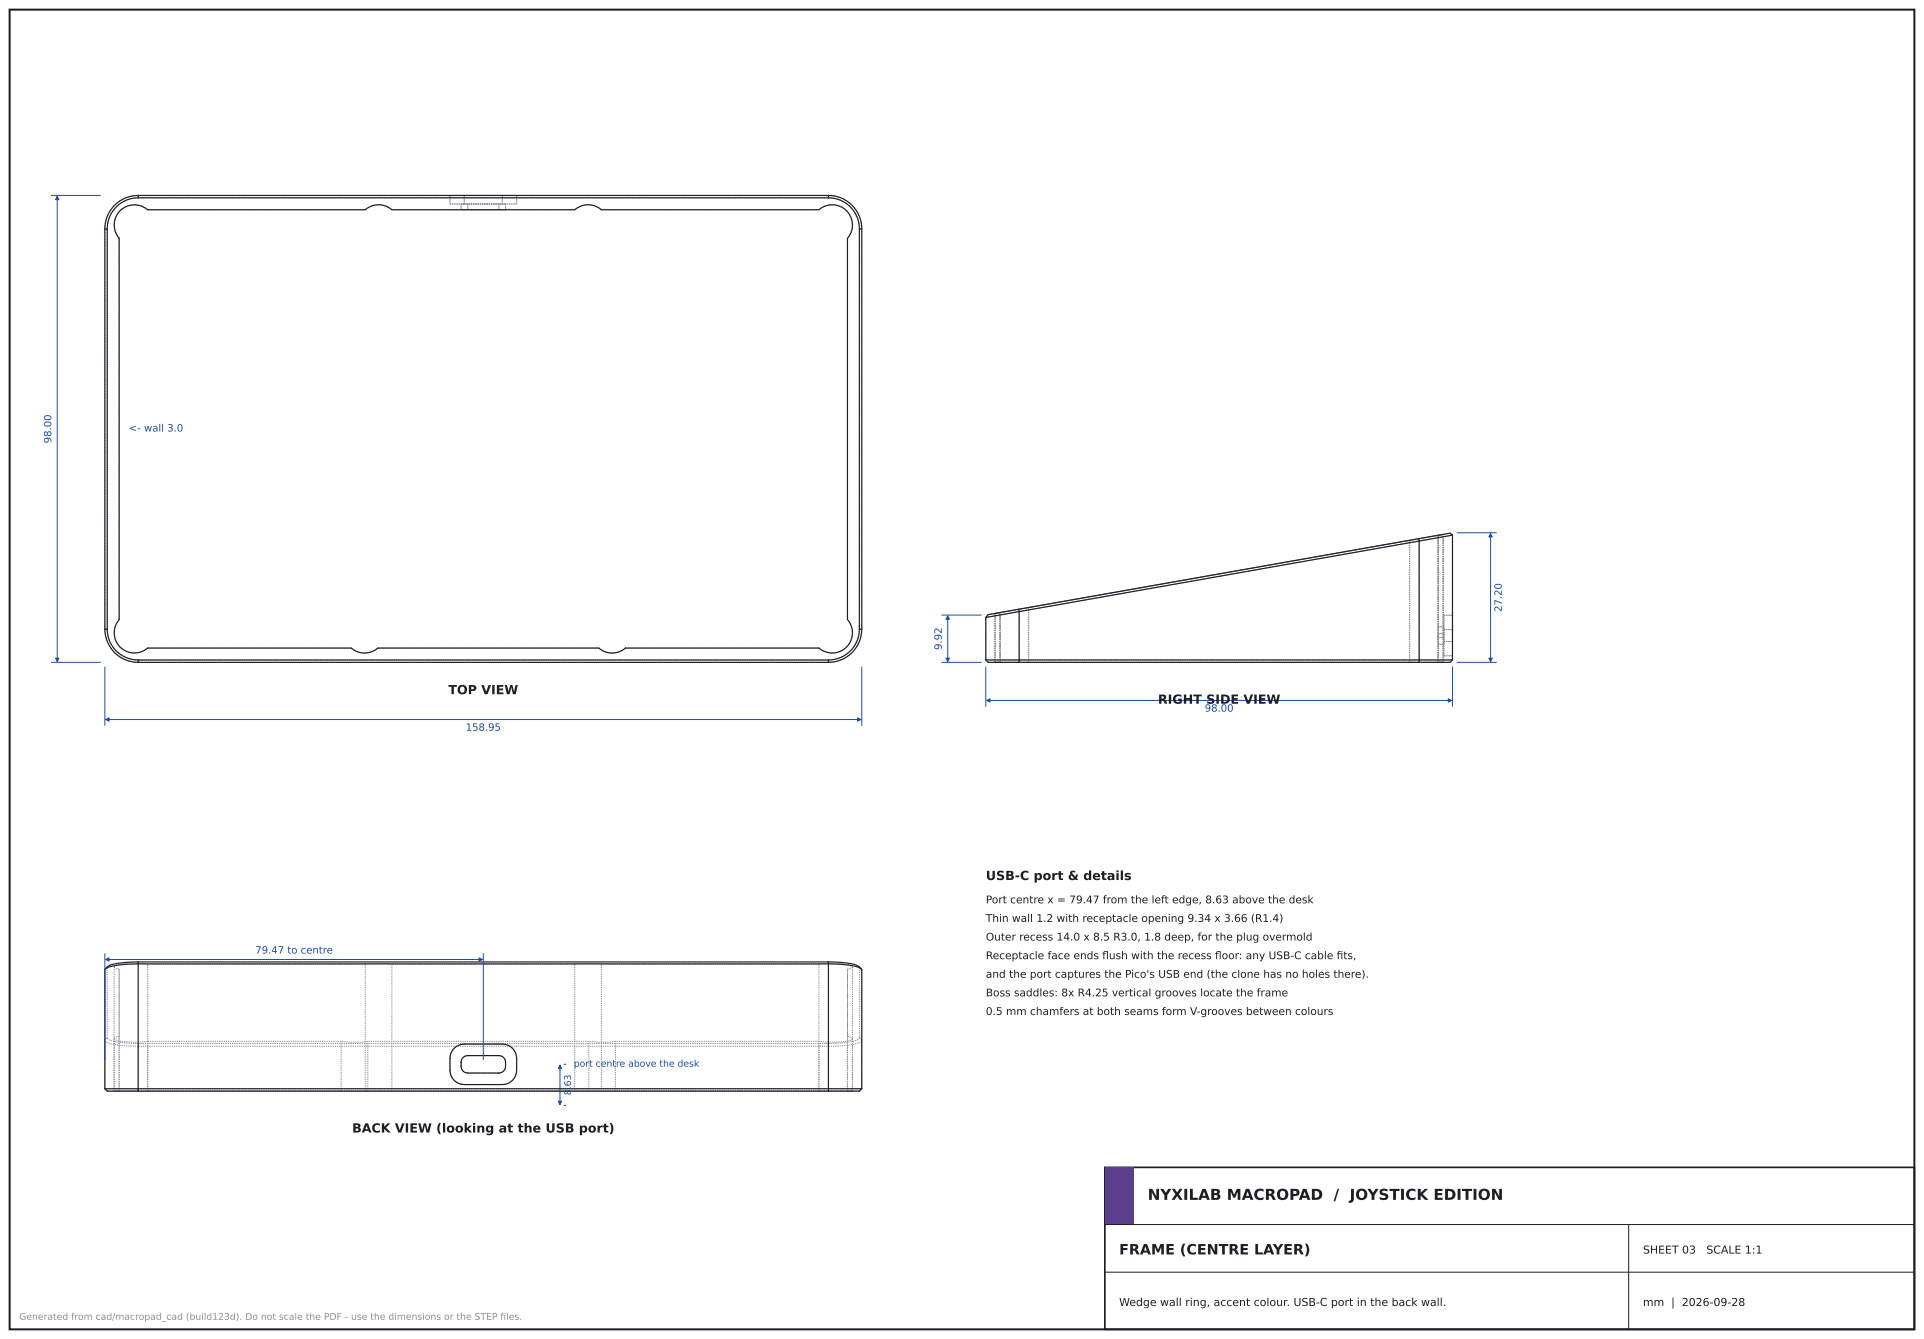
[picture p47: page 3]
SHEET 03 SCALE 1:1; TOP VIEW; RIGHT SIDE VIEW; <- wall 3.0; 79.47 to centre

USB-C port & details

Port centre x = 79.47 from the left edge, 8.63 above the desk
Thin wall 1.2 with receptacle opening 9.34 x 3.66 (R1.4)
Outer recess 14.0 x 8.5 R3.0, 1.8 deep, for the plug overmold
Receptacle face ends flush with the recess floor: any USB-C cable fits,

and the port captures the Pico's USB end (the clone has no holes there).
Boss saddles: 8x R4.25 vertical grooves locate the frame
0.5 mm chamfers at both seams form V-grooves between colours

port centre above the desk

BACK VIEW (looking at the USB port)

NYXILAB MACROPAD / JOYSTICK EDITION

FRAME (CENTRE LAYER)

Wedge wall ring, accent colour. USB-C port in the back wall.

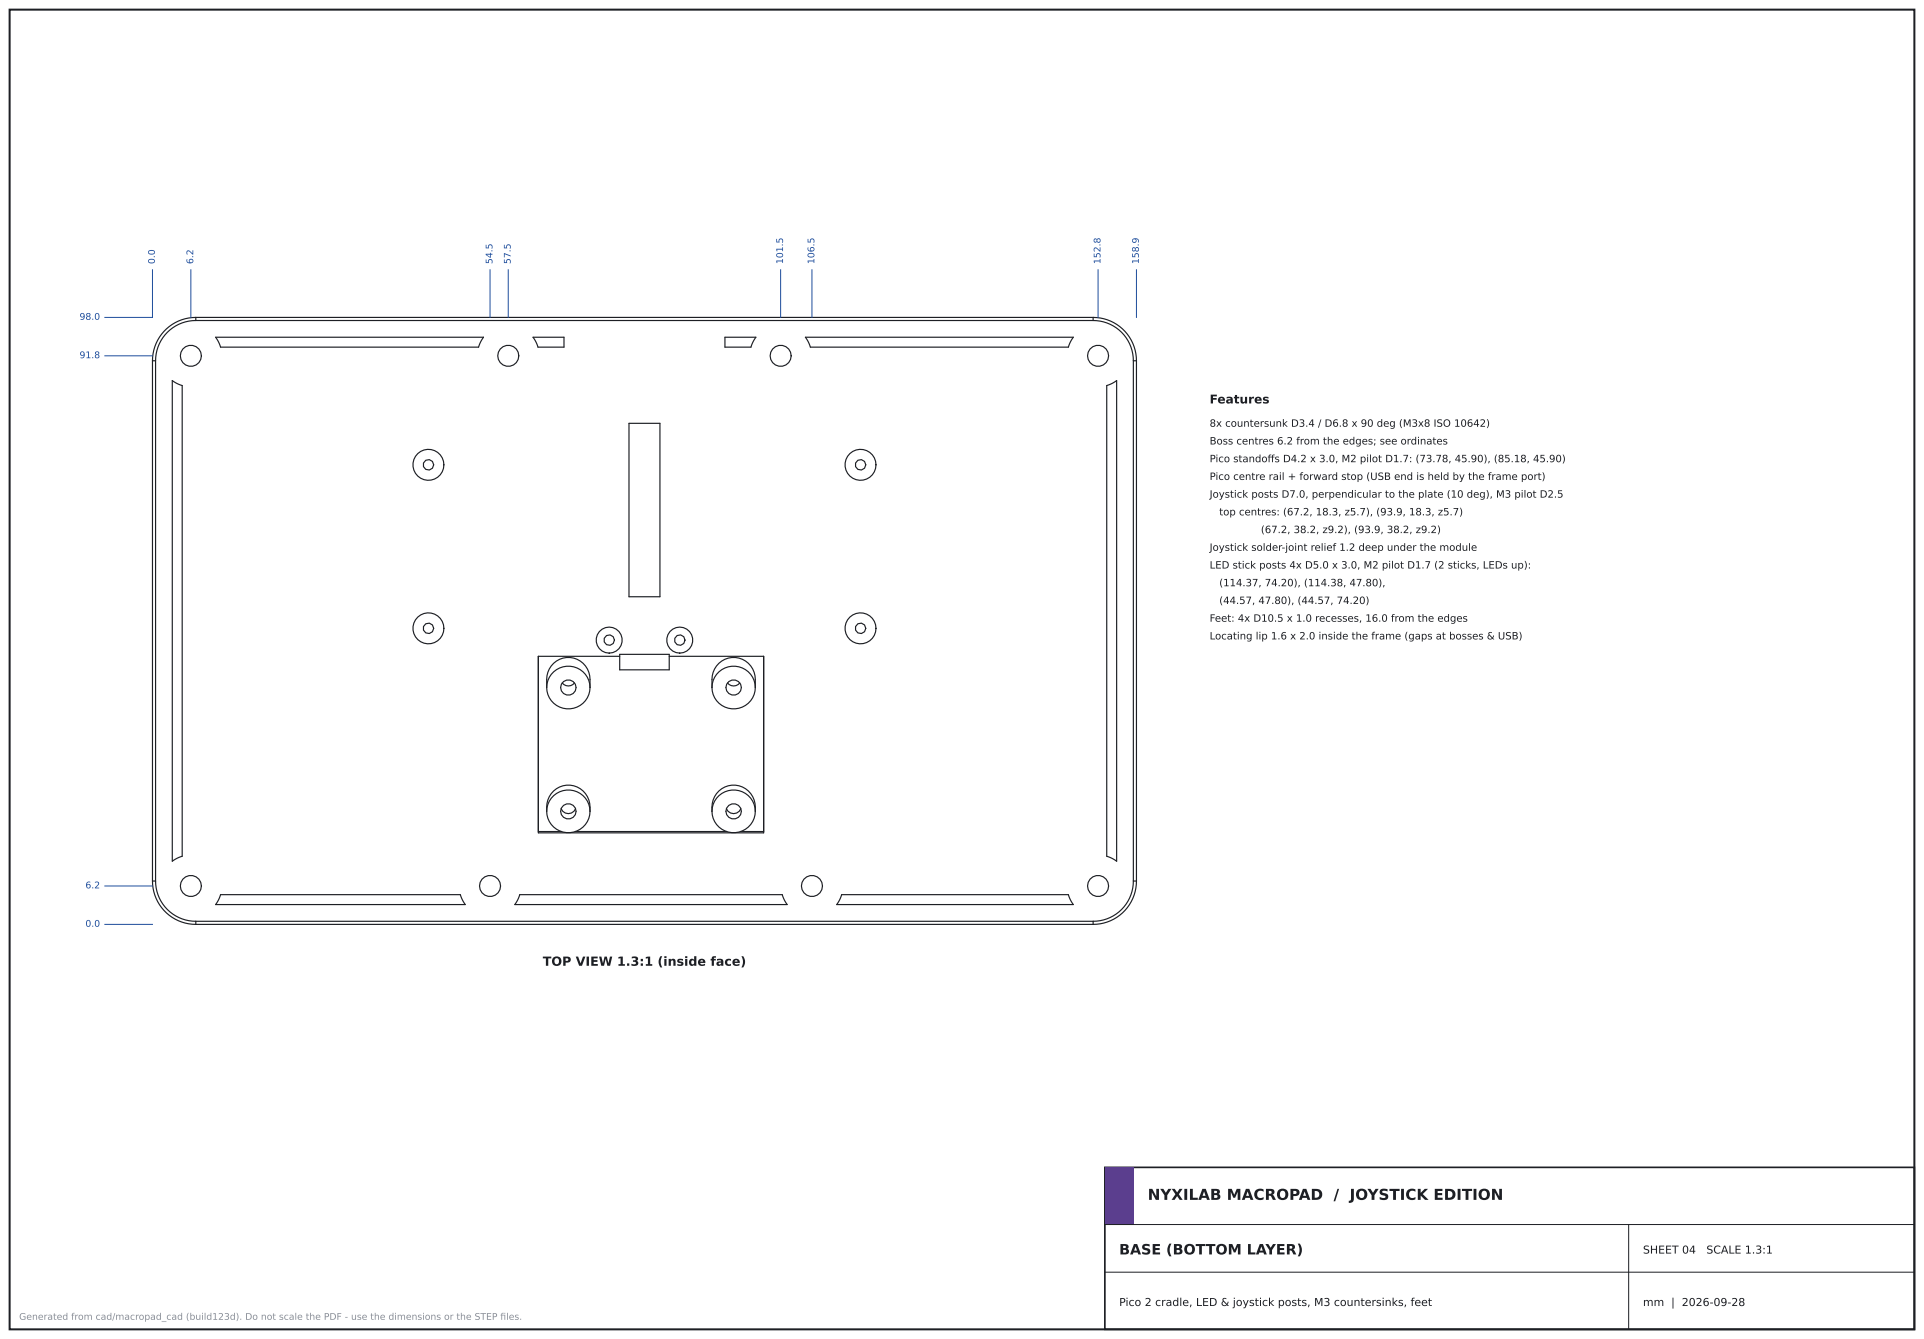
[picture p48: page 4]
SHEET 04 SCALE 1.3:1; Features; top centres: (67.2, 18.3, z5.7), (93.9, 18.3, z5.7)

8x countersunk D3.4 / D6.8 x 90 deg (M3x8 ISO 10642)

Boss centres 6.2 from the edges; see ordinates
Pico standoffs D4.2 x 3.0, M2 pilot D1.7: (73.78, 45.90), (85.18, 45.90)

Pico centre rail + forward stop (USB end is held by the frame port)

Joystick posts D7.0, perpendicular to the plate (10 deg), M3 pilot D2.5

Joystick solder-joint relief 1.2 deep under the module

LED stick posts 4x D5.0 x 3.0, M2 pilot D1.7 (2 sticks, LEDs up):

Feet: 4x D10.5 x 1.0 recesses, 16.0 from the edges

Locating lip 1.6 x 2.0 inside the frame (gaps at bosses & USB)

TOP VIEW 1.3:1 (inside face)

NYXILAB MACROPAD / JOYSTICK EDITION

BASE (BOTTOM LAYER)

Pico 2 cradle, LED & joystick posts, M3 countersinks, feet

## NYXILAB MACROPAD / JOYSTICK EDITION

## BAR DISPLAY SPINE & FIT TESTS

Clamp for the 2.25in module; coupons to print first

SHEET 05 SCALE 2:1


SPINE - TOP 2:1

SPINE - SIDE 2:1 (bed face down)

Bar display spine

Held by the bar module's own two M2 holes (M2x8 through spine + PCB into the plate).

Arches 3.0 mm over the FPC / ZIF / parts on the module back,

pad presses the PCB 3-16 mm from the header end (0.2 mm preload).
Print flat side down, 100 % infill.

Fit-test coupons (print these first, ~1 h total)

fit_switch 3 MX holes 13.9 / 14.0 / 14.1 - pick the one your switches click into

fit_plate_d19 1.9in window, pockets and M2 pilots

fit_plate_bar 2.25in window, pockets and pilots

fit_plate_joy joystick opening and bevel

fit_usb | back wall + Pico cradle: plug a cable in, check alignment
fit_joystick | base patch with the 4 posts: check the KY-023 hole grid
fit_led | base strip with the posts of one LED stick: check the hole pitch

If a fit is off, change the value in the edition's edition.py or common/cad/macropad_cad/params.py

and rebuild (make cad). Values marked MEASURE are the likely suspects.

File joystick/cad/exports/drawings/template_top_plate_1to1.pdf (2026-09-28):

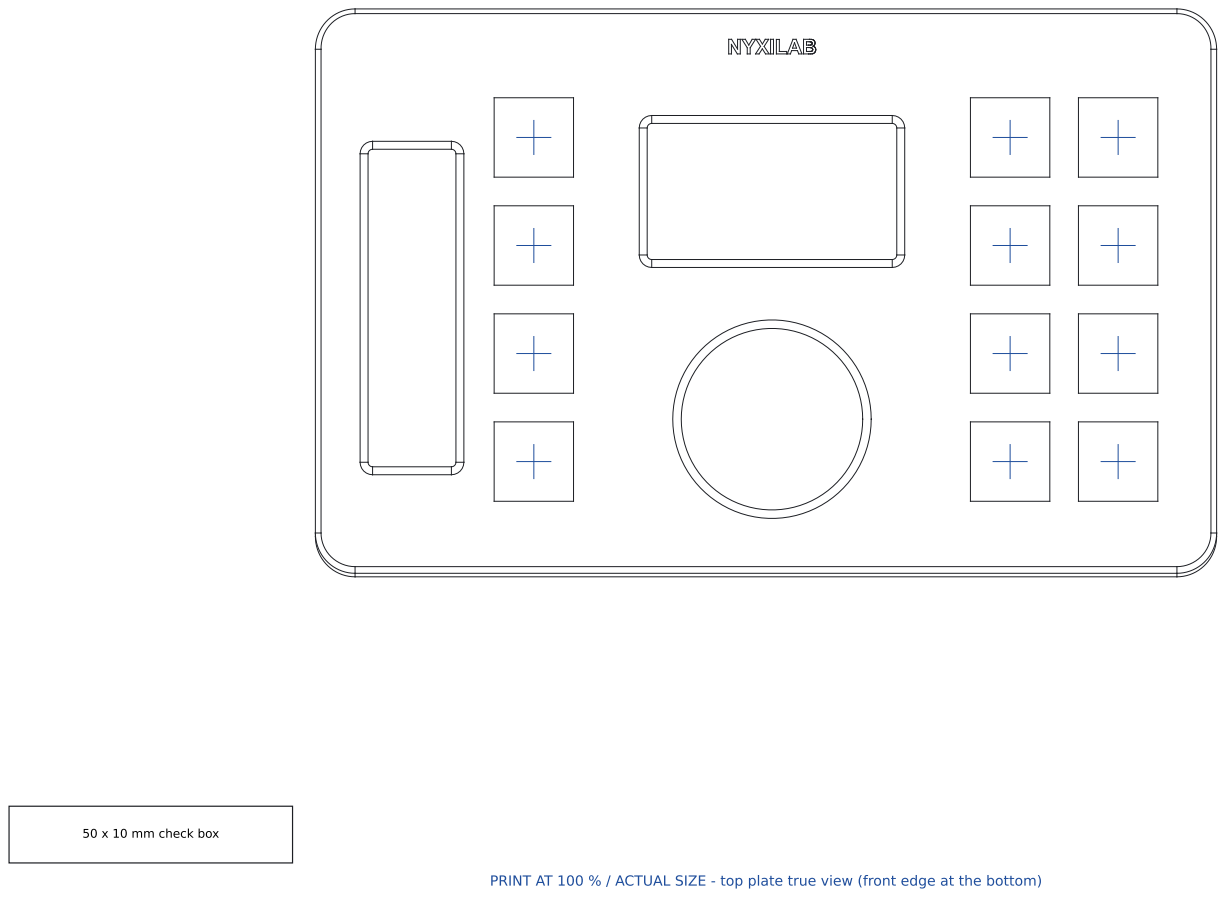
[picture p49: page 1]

50 x 10 mm check box

PRINT AT 100 % / ACTUAL SIZE - top plate true view (front edge at the bottom)

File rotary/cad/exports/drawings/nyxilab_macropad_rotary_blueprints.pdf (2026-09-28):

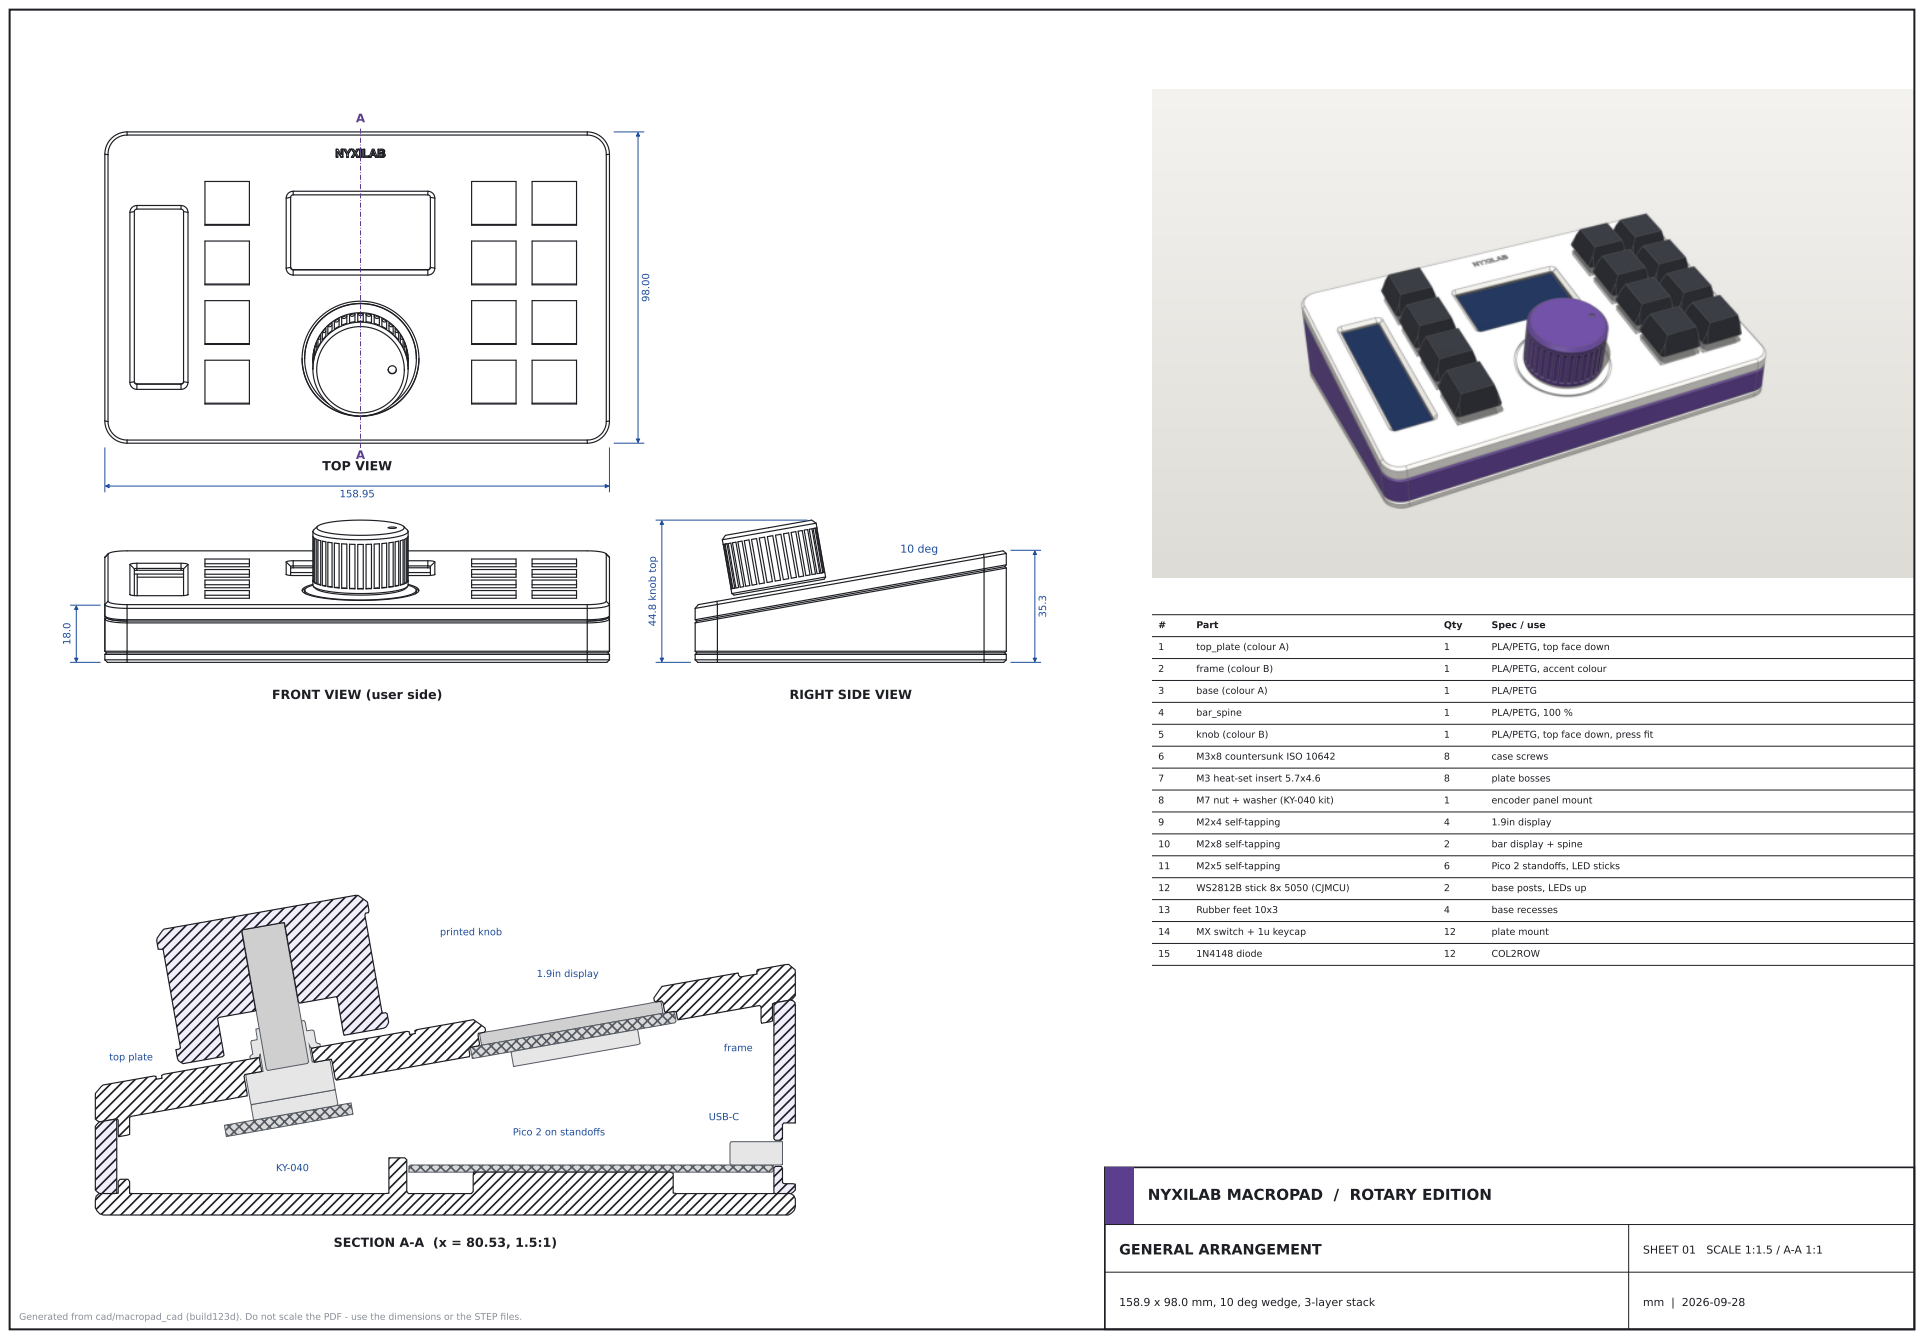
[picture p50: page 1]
GENERAL ARRANGEMENT; SHEET 01 SCALE 1:1.5 / A-A 1:1; TOP VIEW; FRONT VIEW (user side); RIGHT SIDE VIEW; 44.8 knob top; 10 deg; SECTION A-A (x = 80.53, 1.5:1); printed knob; 1.9in display; USB-C; top plate; frame; Part; Qty; Spec / use; top_plate (colour A); PLA/PETG, top face down; frame (colour B); PLA/PETG, accent colour; base (colour A); PLA/PETG; bar_spine; PLA/PETG, 100 %; knob (colour B); PLA/PETG, top face down, press fit; M3x8 countersunk ISO 10642; case screws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

Pico 2 on standoffs

NYXILAB MACROPAD / ROTARY EDITION

158.9 x 98.0 mm, 10 deg wedge, 3-layer stack

Generated from cad/macropad_cad (build123d). Do not scale the PDF - use the dimensions or the STEP files.

## NYXILAB MACROPAD / ROTARY EDITION

## TOP PLATE - TRUE VIEW

Viewed normal to the tilted top surface (plate frame u, v)

SHEET 02 SCALE 1:1

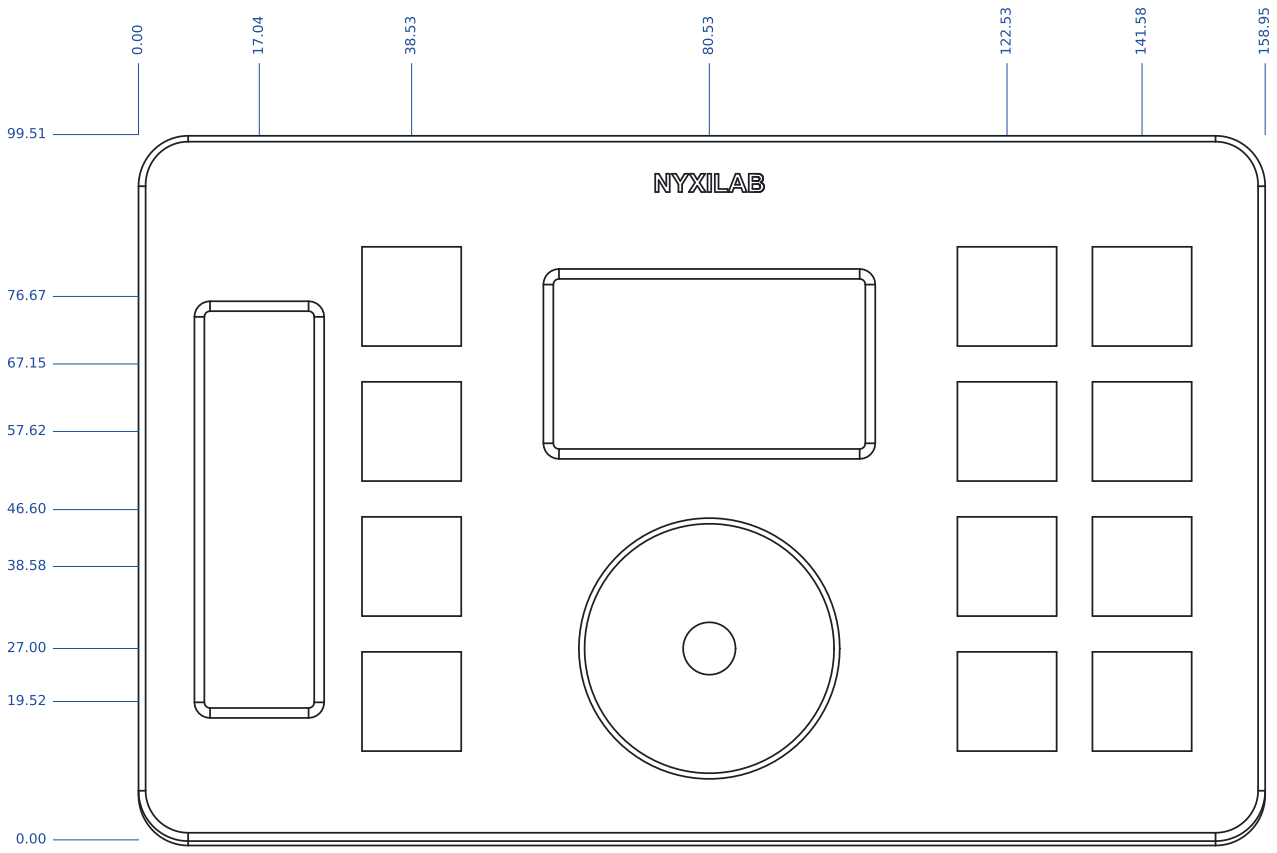
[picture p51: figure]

TOP (visible face)

Ordinates from the front-left corner of the top surface (u right, v up-slope).

Features

MX cut-outs 12x 14.0 x 14.0 through, clip relief 15.0 x 15.6 from below, skin 1.5

Key pitch 19.05 | columns u = 38.53 / 122.53 / 141.58

Rows v = 19.52 / 38.58 / 57.62 / 76.67

1.9in window 44.02 x 24.00 centred (u 80.53, v 67.15), 1.4 x 45 bevel

2.25in window 15.50 x 55.99 centred (u 17.04, v 46.60), 1.4 x 45 bevel

Encoder mount at (u 80.53, v 27.00): D7.4 bushing hole through a 2.0 clamp section

12.5 square key pocket from below, engraved ring D36.0 x 0.8 wide x 0.5 deep

Plate 5.0 thick, display skin 2.0, top edge chamfer 1.0

Slope length V = 99.51 (world depth 98.0 at 10 deg)

UNDERSIDE (from below, 1:1.8)

Bosses: world-vertical, M3 heat-set insert D4.0 x 6.2 at the lower end

Display pockets: glass + PCB steps, M2 pilot D1.7 blind (0.7 skin left)

Header relief grooves over the display pin rows (front-side joints)

Locating lip 1.6 x 2.5 drops inside the frame

Encoder body sits in the 12.5 square pocket: its M7 nut on top clamps 2.0 mm of plate

SHEET 03 SCALE 1:1; TOP VIEW; RIGHT SIDE VIEW; <- wall 3.0; 79.47 to centre

USB-C port & details

Port centre x = 79.47 from the left edge, 8.63 above the desk
Thin wall 1.2 with receptacle opening 9.34 x 3.66 (R1.4)
Outer recess 14.0 x 8.5 R3.0, 1.8 deep, for the plug overmold
Receptacle face ends flush with the recess floor: any USB-C cable fits,

and the port captures the Pico's USB end (the clone has no holes there).
Boss saddles: 8x R4.25 vertical grooves locate the frame
0.5 mm chamfers at both seams form V-grooves between colours

port centre above the desk

BACK VIEW (looking at the USB port)

NYXILAB MACROPAD / ROTARY EDITION

FRAME (CENTRE LAYER)

Wedge wall ring, accent colour. USB-C port in the back wall.

SHEET 04 SCALE 1.3:1; Features

8x countersunk D3.4 / D6.8 x 90 deg (M3x8 ISO 10642)

Boss centres 6.2 from the edges; see ordinates
Pico standoffs D4.2 x 3.0, M2 pilot D1.7: (73.78, 45.90), (85.18, 45.90)

Pico centre rail + forward stop (USB end is held by the frame port)

No posts: the KY-040 hangs from the top plate on its M7 nut,
so the floor under it stays flat

LED stick posts 4x D5.0 x 3.0, M2 pilot D1.7 (2 sticks, LEDs up):

Feet: 4x D10.5 x 1.0 recesses, 16.0 from the edges

Locating lip 1.6 x 2.0 inside the frame (gaps at bosses & USB)

TOP VIEW 1.3:1 (inside face)

NYXILAB MACROPAD / ROTARY EDITION

BASE (BOTTOM LAYER)

Pico 2 cradle, LED posts, M3 countersinks, feet

## NYXILAB MACROPAD / ROTARY EDITION
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

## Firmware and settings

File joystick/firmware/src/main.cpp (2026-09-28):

// Nyxilab macropad firmware, JOYSTICK edition.
//
// Everything shared (matrix, engine, USB HID, displays, LEDs, console) lives in
// common/firmware/lib; this project adds the KY-023 thumbstick and its keymap.
#include <Arduino.h>

#include "app/app.h"
#include "stick.h"

static JoystickCentre g_stick;

void setup() { app::begin(g_stick); }
void loop() { app::loop(); }
void setup1() { app::begin1(); }
void loop1() { app::loop1(); }

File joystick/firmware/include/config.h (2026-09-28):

// ============================================================================
//  Hardware configuration, JOYSTICK edition - pins match docs/wiring.md
//
//  Raspberry Pi Pico 2 (RP2350) or Pico (RP2040), USB-C clone boards.
//  "GPx" numbers below are GPIO numbers, not physical pin numbers.
// ============================================================================
#pragma once
#include <stdint.h>

#include "core/keymap.h"

namespace cfg {

// ---- key matrix, COL2ROW: diode cathode (black band) towards the ROW wire --
constexpr uint8_t ROW_PINS[mp::ROWS] = {2, 3, 4, 5};  // R0 = back row ... R3 = front row
constexpr uint8_t COL_PINS[mp::COLS] = {6, 7, 8};     // C0 = left column, C1/C2 = right block
constexpr uint8_t DEBOUNCE_MS = 5;
constexpr uint32_t SCAN_INTERVAL_US = 1000;

// ---- KY-023 joystick.  Power it from 3V3 (pin 36), NOT 5 V: the ADC is 3.3 V max
constexpr uint8_t JOY_X_PIN = 26;   // ADC0  (module pin VRx)
constexpr uint8_t JOY_Y_PIN = 27;   // ADC1  (module pin VRy)
constexpr uint8_t JOY_SW_PIN = 22;  // module pin SW, internal pull-up
constexpr bool JOY_INVERT_X = false;  // flip if the pointer moves the wrong way
constexpr bool JOY_INVERT_Y = false;
constexpr bool JOY_SWAP_XY = false;
constexpr uint32_t JOY_PERIOD_MS = 8;

// ---- RGB LED sticks on the base: 2 x 8 WS2812B (CJMCU-2812-8), chained --------------
//  right stick DIN (back end) <- GP28 via 330 R; its DOUT (front) -> left stick DIN.
//  5V from VBUS (pin 40) through a 1N4001 diode, so 3.3 V data is a valid "high".
constexpr uint8_t LED_PIN = 28;
constexpr uint8_t LED_COUNT = 16;            // 0 = no LED sticks fitted
constexpr uint8_t LED_MAX_BRIGHTNESS = 160;  // cap on top of the display brightness (DIM-/DIM+)
constexpr uint16_t LED_BUDGET_MA = 250;      // hard limit for the sticks; USB 2.0 gives 500 mA in total

// ---- main display: 1.9" 170x320 ST7789 on SPI0 ---------------------------------
constexpr uint8_t MAIN_SCK = 18, MAIN_MOSI = 19, MAIN_CS = 17, MAIN_DC = 16, MAIN_RST = 20, MAIN_BL = 21;
constexpr uint16_t MAIN_W = 170, MAIN_H = 320;  // native panel size
constexpr uint8_t MAIN_ROTATION = 1;            // landscape; use 3 if the image is upside down
constexpr bool MAIN_INVERT = true;              // IPS panels need colour inversion
constexpr bool MAIN_BGR = false;                // set if red and blue are swapped

// ---- bar display: 2.25" 76x284 ST7789P3 on SPI1 --------------------------------
constexpr uint8_t BAR_SCK = 10, BAR_MOSI = 11, BAR_CS = 13, BAR_DC = 12, BAR_RST = 14, BAR_BL = 15;
constexpr uint16_t BAR_W = 76, BAR_H = 284;
constexpr uint8_t BAR_ROTATION = 2;  // portrait, header towards the user; use 0 if upside down
constexpr bool BAR_INVERT = true;
constexpr bool BAR_BGR = false;

constexpr uint32_t SPI_HZ = 40000000;  // safe for hand-wired leads; 62.5 MHz = faster refresh, 20 MHz if glitchy

// ---- backlight & idle ------------------------------------------------------------
constexpr uint8_t BRIGHTNESS_DEFAULT = 200;  // 0..255
constexpr uint8_t BRIGHTNESS_STEP = 32;
constexpr uint32_t DIM_AFTER_MS = 60UL * 1000;       // dim after 1 min idle
constexpr uint32_t SLEEP_AFTER_MS = 10UL * 60 * 1000;  // backlight off after 10 min
constexpr uint8_t BRIGHTNESS_DIMMED = 24;

// ---- USB --------------------------------------------------------------------------
constexpr const char* USB_VENDOR_NAME = "Nyxilab";
constexpr const char* USB_PRODUCT_NAME = "Nyxilab Macropad";

}  // namespace cfg

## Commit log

2026-09-27 Initial import: 3D-printable case, firmware and docs
    - cad/: parametric build123d model of the three-layer wedge case (top
    plate, centre frame, base, bar-display spine) with interference,
    clearance and printability checks; STEP/STL/3MF/GLB/FreeCAD exports,
    fit-test coupons, renders and A3 blueprints
    - firmware/: PlatformIO project for Pico 2 / Pico (TinyUSB composite
    HID, layers, tap-hold, macros, joystick mouse/scroll/arrows, two
    ST7789 displays), native unit tests, UI simulator and prebuilt UF2s
    - docs/: design notes, printing, assembly and wiring guides, diagrams
    and an interactive 3D viewer
    [bar_spine.3mf, bar_spine.step, bar_spine.stl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]
2026-09-28 Split into per-edition projects, add the rotary knob, LED sticks, a soldering guide and the docs site
    Structure: joystick/{cad,firmware} and rotary/{cad,firmware} are the four
    projects. common/cad is the shared case model (build123d) with an Edition
    hook interface; common/firmware/lib holds the shared firmware as PlatformIO
    libraries (core, hw, ui, app), the editions plug in their centre control
    through app::Centre.
    CAD: rotary edition (KY-040 panel mount, printed knob with a D-bore that ends
    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
    [bar_spine.3mf, bar_spine.step, bar_spine.stl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]
2026-10-21 fix(engine): release a pending tap before the next tap-hold tap
    A tap-hold whose tap is a key stays down for 10 ms after release, and that
    timer is held while USB is not ready (host suspended / waking). A second tap
    in that window overwrote tap_release_, so the first key was never released
    and stayed stuck. The shipped keymaps only tap LNEXT, so custom keymaps were
    affected. Add a regression test (core tests: 28).
    Also: fix the .gitattributes pattern for the drawing SVGs (it matched
    nothing), and remove a stale pre-split joystick blueprint PDF that nothing
    generates or links to.
2026-10-21 docs(ui): render the knob dial in the rotary edition's UI images
    The UI simulator's scenes never set centre_encoder, which KnobCentre::fill_ui()
    sets on the device, so every rotary render showed the joystick widget.
2026-10-21 feat: host bridge - HOST layer dashboard fed by a Linux daemon (nyxd)
    An optional two-way link between the macropad and the computer:
    - Firmware: a second, vendor-defined HID interface (usage page 0xFF4E,
    64-byte reports, "Nyxilab Host Link"). core/host_proto parses packets,
    keeps the dashboard data and history, times the link out after 5 s and
    queues device->host events; hw/host_hid owns the interface with an
    IRQ-safe ring; nyx_app reports state and forwards HOST(n) events.
    - Keymaps: Layer.view (View::Host) and a HOST layer in both editions.
    Host layers are skipped by LayerNext while no daemon is connected.
    HOST(n) is a new action that sends an event to the daemon.
    - UI: the d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
2026-10-22 fix(engine): ignore MO/TG for layers the keymap does not define
    A typo such as TG(5) in a 3-layer keymap put layer 5 on top, and the UI,
    LEDs, stick mode and host view then read past LAYERS[]. Layer actions now
    only accept defined layers (regression test added). Also drop the unused
    UiState::presses_total.
2026-10-22 build(firmware): pin the platform, core and libraries
    The platform was taken from its git default branch and the libraries from
    caret ranges, so a build could silently change between machines or days.
    Pin the platform commit (which pins Arduino-Pico fd65f6d and the toolchain)
    and the exact versions of every compiled library.
2026-10-22 fix(cad): report the real bridge span of ring-shaped patches
    short_span was the bounding-box side, so the rotary plate's 0.8 mm engraved
    ring was reported as a 36.8 mm bridge. Use min(bbox side, 4 x area /
    perimeter); the longest bridge is now the 10.5 mm foot recess, as the
    README says.
2026-10-22 chore(docs): make the generated figures reproducible
    Stable SVG ids (svg.hashsalt) and no timestamps (SOURCE_DATE_EPOCH) in the
    matplotlib outputs, so make docs only changes files whose drawing changed.
    Regenerated the wiring and soldering figures once.
2026-10-22 feat(host): rewrite the host bridge daemon in Rust
    nyxd and nyxctl are now one Rust crate (host/) instead of a Python package,
    with the same behaviour, protocol and files around it:
    - src/protocol.rs mirrors core/host_proto.h; src/metrics.rs reads /proc and
    /sys (CPU, cores, memory, swap, disk, load, network, temperatures, AMD GPU,
    nvidia-smi); src/device.rs finds the host-link hidraw node by its report
    descriptor; src/daemon.rs is a single-threaded poll(2) loop with the
    control socket, reconnects, session replay and key -> command mapping.
    - The config file is parsed strictly: unknown keys are reported.
    - Tests: the daemon loop against a fake macropad on a SOCK_SEQPACKET pair
    (th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
2026-10-22 ci: run tests, sanitizers, firmware builds, CAD checks and the site on every push
    Four jobs: native tests + ASan/UBSan + the Rust daemon (clippy, rustfmt);
    all four firmware targets with a no-warnings gate for the project's own
    code, uploading the UF2s as artifacts; both editions' CAD checks; the docs
    site build and a pyflakes lint of the Python tools.
2026-10-22 ci: install Python tools from hash-locked, wheel-only requirements
    SonarCloud flagged every pip install in ci.yml (S8544 unlocked versions,
    S8541 source builds that run setup scripts), failing the PR's security
    rating. CI now installs from .github/requirements/{tools,cad}.txt, generated
    by uv with exact versions and sha256 hashes for every package (the CAD set
    constrained to the versions the checks were validated with), using
    --only-binary :all: --require-hashes. The CAD job no longer installs the
    local package: build.py already puts common/cad on sys.path.
2026-11-12 feat(cad): engrave a moon-and-star mark instead of the title
    The 3.6 mm NYXILAB lettering on the back border did not survive a 0.4 mm
    nozzle. A 9 mm crescent with a four-point star takes its place, in the same
    spot: every stroke and every wall between strokes is 1.4 mm or wider.
    Case.logo_h sets the height (0 = no logo) and replaces the Case.logo text.
    Nothing else on the plate moved. Both editions pass the fit checks (169 and
    191 pairs); the mark adds two small bridges (3.3 and 2.8 mm span). Exports,
    renders, drawings and the viewer are regenerated for the top plate and the
    assembly. The FreeCAD documents are not: freecadcmd was not available.
    Not yet test-printed.
2026-11-12 docs: add a build guide from soldering to flashing
    The soldering, wiring and assembly pages each cover one stage, and flashing
    was only described in the README and the firmware README. The build guide is
    the route through all of them: prepare, solder the matrix, solder the modules,
    wire the Pico, flash, assemble, with a test after every stage. It links to the
    existing pages for the detail instead of repeating it.
2026-11-12 fix(firmware): stop knob taps replaying and re-pressing, keep the save delay
    Three faults on the rotary edition's knob path, found by review:
    - Turning the knob while its press (or a consumer key) was held pressed
    the held usage again after every detent: MUTE toggled once per step.
    The consumer report carries one usage, so a newer consumer press now
    replaces the older one instead of stacking on it.
    - Detents turned while USB was suspended or not mounted filled the tap
    queue and all 17 played on resume. The app loop now clears the waiting
    taps while nobody listens, as it already does for wheel steps. The tap
    already down stays, so it still requests wake-up.
    - settings_task compar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
2026-11-12 test(firmware): pin the knob's decoder table, saved settings and FN bindings
    Mutation runs showed that several knob regressions passed every suite.
    These tests close the gaps; no production code changes.
    - Decoder: two-edge detents in both directions, a missed counter-clockwise
    edge, repeated states (contact bounce), half-step counter-clockwise,
    two-contact jumps, reset, and the steps-per-detent clamp.
    - Engine: pressing the knob while LAYER is still undecided resolves the
    hold, so the FN binding runs and not the base layer's MUTE.
    - Mocked hardware: the knob preset and direction reach flash after the
    save delay and survive a reload; a detent and a press report activity
    and a hit;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
2026-11-12 fix(firmware): save settings before BOOT/REBOOT, pin more knob behaviour
    A setting changed less than 3 s before a reboot was lost: FN + REV or
    FN + KNOB (also brightness, LED mode, base layer) only mark the settings
    dirty, and BOOT / REBOOT rebooted at once. hw::settings_flush() writes
    now if dirty; SYS_BOOTLOADER and SYS_REBOOT call it first, and
    settings_task uses it for the delayed save. Both editions get this.
    Rotary keymap: the VOLUME and SCROLL bindings are named once and used by
    both the presets and the layers. FN + KNOB hides a preset only while it
    equals the layer's own binding, so the copies must not drift. The values
    are unchanged. A comment notes that the preset index is saved i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
2026-11-13 perf(firmware): push only the display rows that changed
    Core 0 publishes the UI state every 10 ms, so core 1 redrew and pushed both
    full frames back to back: about 35 ms of blocking SPI per frame (25 ms for the
    1.9" panel, 10 ms for the bar, at the 37.5 MHz the Pico 2 really clocks).
    That capped the displays near 25 fps, not the 40 the code aimed for, and
    starved the LED task, which runs in the same loop and wants 50 fps.
    Each rendered frame is now hashed row by row and only the band of rows that
    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
2026-11-13 fix(firmware): drop input made with no host, keep held keys off macro text
    Keys and macros used while the pad had power but no enumerated host were
    queued (up to 64 states) and typed into the host at the first mount; a
    macro started then parked on its first character and typed its whole
    text. Every mount now drops the queue and publishes only what is held,
    and with no host the engine runs without waiting for delivery, so taps
    and macros play out into nothing. Suspend and remote wake-up are
    unchanged.
    A key held while a macro types shared its modifiers with the macro text
    (Ctrl+S during "Hello..." sent Ctrl+O, Ctrl+F, ...), and the macro's
    Shift landed on held keys and stick arrows. Held Key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
2026-11-13 fix(firmware): drop input a sleeping host refuses, save only the stick's range
    A suspended host that did not arm remote wake-up (Linux does so only for
    boot keyboards) cannot be woken from the pad. Presses, releases and macro
    text made meanwhile stayed in the queue and were typed when the PC woke
    some other way, usually into the lock screen. usb_task now drops the queue
    when the wake-up request is refused while still suspended, and the engine
    lets taps and macros play out unsent. A host that armed wake-up is woken
    as before.
    The joystick saved its whole calibration at every boot and every CAL,
    because the rest position, sampled again each time, differs by ADC noise.
    That centre is never rea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
2026-11-13 fix(firmware): start a host session with an empty queue, finish a stranded USB resync
    A HELLO from a daemon that came back inside the 5 s timeout kept the old
    session's TX queue. Queued HOST key packets then ran on the new daemon, and a
    full queue dropped HELLO_ACK and STATE. HELLO now empties the queue, like BYE
    and the timeout, and the app drops the one packet it held for the old session.
    A host that suspended between the reports of the mount resync, without arming
    remote wake-up, left the consumer and mouse resync unsent. The output then
    never reported delivered, so generated taps and macros stalled until some
    other input changed the HID state. The USB task now finishes a pending resync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
2026-11-13 fix(firmware): press a shared usage again on a key roll, keep a dropped key's modifiers out
    A key pressed onto a held key with the same usage (UNDO rolled into REDO:
    Ctrl+Z, then Ctrl+Shift+Z) only changed the modifiers, so the host saw no
    new key press. The usage now leaves the report for TAP_MS of delivered
    output and comes back with the new key's modifiers. Knob taps and the
    stick click are left as they were.
    Also:
    - A 7th held shortcut no longer puts its modifiers on the six older keys
    while its own key does not fit in the report.
    - The console takes CRLF as one line end, so a command is no longer
    followed by the help line. Line assembly moved to app::ConsoleLine so
    the mocked-har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
2026-11-13 feat(cad): engrave a signature and "Signature Edition" under the base
    Grooves 1.4 mm wide and 0.4 mm deep on the underside, readable with the pad
    turned over. The caption uses pen-stroke letters, not a font: font outlines
    at this size fail the 3MF mesh check. Case.sign_h = 0 removes it.
    Adds a render of the pad from below and shows it in the README, the design
    notes and the printing tips. Exports, drawings and the viewer are regenerated
    for the base.
2026-11-13 feat(site): add an animated product page as the site's home
    web/ holds the page: scroll-scrubbed frame sequences of the case coming
    apart and of the pad turning over to show the signature, layer tabs with
    the real display screens, LED effect and edition switches, use cases,
    specs and build steps. tools/site_renders.py renders its images on black.
    The README page moves to docs.html. build_site.py fails on a broken local
    link, Pages builds on pull requests as a check, and make site-dev serves
    the site with rebuild and reload on save.
